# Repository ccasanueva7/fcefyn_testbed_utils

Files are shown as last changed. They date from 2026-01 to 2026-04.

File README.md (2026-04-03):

# fcefyn-testbed-utils

Complementary infrastructure for the FCEFyN HIL (Hardware-in-the-Loop) testbed: configs, scripts, and firmwares that are not part of the contributed repositories libremesh-tests and openwrt-tests.

---

Documentation: https://fcefyn-testbed.github.io/fcefyn_testbed_utils/

### Local preview (MkDocs)

Use the same dependencies as CI (includes `mkdocs-panzoom-plugin` for Mermaid pan/zoom):

```bash
python3 -m venv .venv-docs
source .venv-docs/bin/activate   # Windows: .venv-docs\Scripts\activate
pip install -r requirements-docs.txt
mkdocs serve #or mkdocs serve --livereload
```

If `mkdocs serve` reports `The "panzoom" plugin is not installed`, the active environment is missing dependencies: run `pip install -r requirements-docs.txt` again (or `pip install mkdocs-panzoom-plugin`) in that environment.

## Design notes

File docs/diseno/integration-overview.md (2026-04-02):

# Integration overview

How the FCEFyN testbed integrates with the existing openwrt-tests ecosystem. Intended as the entry point for the Design section: read this first, then follow the links to the detailed docs.

---

## 1. Starting point: openwrt-tests ecosystem

Before the FCEFyN lab existed, [openwrt-tests](https://github.com/openwrt/openwrt-tests) already operated a global testing infrastructure:

- A **VM in a datacenter** (public IP) runs a `labgrid-coordinator` and a pool of GitHub Actions **self-hosted runners**.
- **Remote labs** contributed by developers around the world each run a `labgrid-exporter`. They register their physical DUTs with the global coordinator over a **WireGuard** tunnel.
- When CI triggers (daily, PR, or manual), runners on the VM reserve and lock a device via the coordinator, then flash and test it by SSHing to the lab host over WireGuard.

```mermaid
flowchart TD
    subgraph vm ["Datacenter VM (Paul / aparcar)"]
        R_OWT["GitHub runners"]
        COORD["labgrid-coordinator :20408"]
    end

    subgraph lab_ext ["Remote lab (any contributor)"]
        EXP_E["labgrid-exporter"]
        HW_E["DUTs"]
    end

    R_OWT -- "1" --> COORD
    EXP_E -- "2" --> COORD
    R_OWT -- "3" --> HW_E
```

| # | Connection | Detail |
|---|---|---|
| 1 | Runner → Coordinator | WebSocket localhost:20408 (reserve / lock / unlock) |
| 2 | Exporter → Coordinator | WebSocket via WireGuard (register resources) |
| 3 | Runner → DUTs | SSH via WireGuard (LG_PROXY=labgrid-X) |

See [openwrt-tests CI flow](openwrt-tests-ci-flow.md) for the detailed sequence of how a single job runs end-to-end.

---

## 2. Our hardware contribution to openwrt-tests

The FCEFyN lab contributes physical devices to the openwrt-tests pool. This means:

- `labgrid-fcefyn` is added as a lab entry in `labnet.yaml` (the upstream registry).
- A **`labgrid-exporter`** on the FCEFyN host registers all DUTs with the global coordinator over WireGuard.
- Runners on Paul's VM can then run openwrt-tests jobs on our hardware, exactly as they do with any other lab.

From the coordinator's perspective, our lab is indistinguishable from any other contributor. The process to set this up is documented in [openwrt-tests onboarding](openwrt-tests-onboarding.md).

---

## 3. Our own CI: libremesh-tests runner

For LibreMesh-specific tests, we run our **own GitHub Actions self-hosted runner** on the FCEFyN lab host (not on Paul's VM). This is the key architectural difference from openwrt-tests.

```mermaid
flowchart TD
    subgraph vm ["Datacenter VM (Paul / aparcar)"]
        R_OWT["openwrt-tests runners"]
        COORD["labgrid-coordinator :20408"]
    end

    subgraph lab ["FCEFyN lab host"]
        R_LM["libremesh-tests runner"]
        EXP["labgrid-exporter"]
        BC["labgrid-bound-connect"]
        DUTs["DUTs"]
    end

    R_OWT -- "1" --> COORD
    EXP -- "2" --> COORD
    R_LM -- "3" --> COORD
    R_OWT -- "4" --> BC
    R_LM -- "5" --> BC
    BC -- "6" --> DUTs
```

| # | Connection | Detail |
|---|---|---|
| 1 | openwrt-tests runner → Coordinator | WebSocket localhost:20408 (reserve / lock) |
| 2 | Exporter → Coordinator | WebSocket via WireGuard (register resources) |
| 3 | libremesh-tests runner → Coordinator | WebSocket via WireGuard (LG_COORDINATOR=WG_IP:20408) |
| 4 | openwrt-tests runner → bound-connect | SSH via WireGuard (LG_PROXY=labgrid-fcefyn) |
| 5 | libremesh-tests runner → bound-connect | SSH local (LG_PROXY=labgrid-fcefyn → 127.0.1.1) |
| 6 | bound-connect → DUTs | socat bindtodevice → vlanXXX |

### Key differences vs openwrt-tests runner

| | openwrt-tests runner | libremesh-tests runner |
|---|---|---|
| **Location** | Paul's VM (datacenter) | FCEFyN lab host |
| **Runner label** | `global-coordinator` | `[self-hosted, testbed-fcefyn]` |
| **`LG_COORDINATOR`** | `localhost:20408` (default, same VM) | `vars.LG_COORDINATOR` = WireGuard IP of Paul's VM |
| **`LG_PROXY`** | SSH via WireGuard to lab host | SSH to `127.0.1.1` (localhost, same machine) |
| **SSH to DUT** | WireGuard + `labgrid-bound-connect` | Local `labgrid-bound-connect` |
| **VLAN per test** | Isolated VLANs 100-108 (no change needed) | Switches to VLAN 200 for mesh, restores on teardown |

### `LG_PROXY` in the local case

Both runners set `LG_PROXY=labgrid-fcefyn`. The difference is in how that hostname resolves:

- From Paul's VM: `labgrid-fcefyn` is a WireGuard peer - SSH traverses the tunnel.
- From the lab host itself: Ansible sets `127.0.1.1 labgrid-fcefyn` in `/etc/hosts` - SSH goes to localhost. The `labgrid-bound-connect` proxy command still runs, but entirely on the same machine.

### VLAN difference between test suites

openwrt-tests runs single-node tests. Each DUT stays on its **isolated VLAN** (100-108) for the entire test - no switch reconfiguration needed.

libremesh-tests runs multi-node mesh tests. Participating DUTs must all be on **VLAN 200** to form a mesh. The test fixture switches each port to VLAN 200 at start and restores it on teardown. This is the only test suite that modifies VLAN state.

See [Lab architecture](lab-architecture.md) for the full VLAN design and the `vlan_manager` API.

### `LG_COORDINATOR` configuration

`LG_COORDINATOR` is set as a **GitHub Actions repository variable** in the libremesh-tests repo (`Settings > Secrets and variables > Actions > Variables`):

```
LG_COORDINATOR = <WireGuard IP of Paul's VM>:20408
```

The workflows use `vars.LG_COORDINATOR || 'localhost:20408'`, so if the variable is unset they fall back to localhost (useful for local development against a local coordinator).

---

## 4. Shared coordinator, no conflicts

Both runners - Paul's (openwrt-tests) and ours (libremesh-tests) - talk to the **same `labgrid-coordinator`** on Paul's VM. They share the same pool of places (DUTs).

The coordinator serializes access via **Labgrid locks**: only one runner can hold a lock on a place at a time. A runner that wants a busy device waits (`reserve --wait`) until the lock is released.

```mermaid
sequenceDiagram
    participant R_OWT as openwrt-tests runner
    participant COORD as coordinator
    participant R_LM as libremesh-tests runner

    R_OWT->>COORD: reserve device=linksys_e8450
    COORD-->>R_OWT: LG_TOKEN=A
    R_OWT->>COORD: lock +A

    R_LM->>COORD: reserve device=linksys_e8450
    Note over COORD: place locked
    COORD-->>R_LM: waiting...

    Note over R_OWT: test runs
    R_OWT->>COORD: unlock +A

    COORD-->>R_LM: LG_TOKEN=B
    R_LM->>COORD: lock +B
    Note over R_LM: test runs
    R_LM->>COORD: unlock +B
```

---

## 5. Reading guide for the Design section

| Goal | Start here |
|---|---|
| Understand how openwrt-tests CI runs step by step | [openwrt-tests CI flow](openwrt-tests-ci-flow.md) |
| Set up the WireGuard tunnel and contribute hardware to openwrt-tests | [openwrt-tests onboarding](openwrt-tests-onboarding.md) |
| VLAN design, `vlan_manager` API, switch configuration | [Lab architecture](lab-architecture.md) |
| Virtual mesh tests with QEMU and vwifi | [Virtual mesh](virtual-mesh.md) |

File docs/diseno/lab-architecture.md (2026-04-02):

# Lab architecture (dynamic VLAN per test) {: #lab-architecture }

**Technical design document** for the current HIL lab: one global coordinator, one exporter, shared DUT inventory, and VLAN as a per-test attribute. Context: [openwrt-tests](https://github.com/openwrt/openwrt-tests) and [LibreMesh](https://libremesh.org/) workloads on the same hardware.

---

## 1. Scope

- All DUTs are scheduled from a **single Labgrid inventory** (`dut-config.yaml` `duts` as hardware DB).
- VLAN changes apply only where a test requires them (e.g. mesh); openwrt-tests runs on isolated VLANs by default.

---

## 2. Design principle

The VLAN on a DUT port follows the **test run that holds the Labgrid lock**: the test applies the VLAN it needs at start and restores the port on teardown. Labgrid locking serializes access so two jobs do not reconfigure the same port at once.

---

## 3. Architecture

### 3.1 One coordinator, one exporter

| Component | Role |
|---|---|
| Coordinator | One global (datacenter VM, via WireGuard) |
| Exporter | One `labgrid-exporter` process for all DUTs |
| DUT inventory | `dut-config.yaml` `duts` (hardware database for Labgrid) |
| VLAN / scheduling | Per-test VLAN where needed; Labgrid lock serializes access |

The global coordinator is the single source of locks. libremesh-tests points `LG_COORDINATOR` at the coordinator WireGuard IP instead of `localhost:20408`. For the full connection topology (runners, WireGuard, LG_PROXY) see [Integration overview](integration-overview.md).

```mermaid
flowchart LR
    subgraph lab ["FCEFyN lab host"]
        EXP["labgrid-exporter"]
        SW["Switch TP-Link\n(VLANs 100-108, 200)"]
        DUTs["DUTs"]
    end

    COORD["labgrid-coordinator\n(datacenter VM)"]

    EXP -->|"WebSocket via WireGuard\n(register resources)"| COORD
    SW -->|"access port\n(isolated or VLAN 200)"| DUTs
```

### 3.2 Default state: isolated (fail-safe)

All switch ports start on their **isolated VLAN** (100-108):

- openwrt-tests needs no VLAN changes
- If a test fails or the runner crashes, the DUT stays isolated (no cross-talk)

### 3.3 Dynamic VLAN: the test that needs it changes it

Only libremesh-tests needs VLAN 200. Flow:

```mermaid
sequenceDiagram
    participant CI as libremesh runner
    participant COORD as Global Coordinator
    participant SW as Switch
    participant DUT as DUT port

    CI->>COORD: reserve device=belkin_rt3200
    COORD-->>CI: place allocated
    CI->>COORD: lock place
    CI->>SW: set_port_vlan port 12 vlan 200
    SW->>DUT: Port moves to VLAN 200
    Note over CI,DUT: Test runs - serial flash SSH
    CI->>SW: set_port_vlan port 12 vlan 101
    SW->>DUT: Port restored to isolated VLAN
    CI->>COORD: unlock place
```

Switching overhead: 2-5 s (SSH to switch + CLI). Negligible vs flash + boot (minutes).

### 3.4 Static infrastructure (all VLANs always on)

Configured once and left alone:

| Component | Permanent configuration |
|---|---|
| Switch uplinks (ports 9, 10) | Trunk of ALL VLANs (100-108 + 200) |
| Host netplan | vlan100-108 AND vlan200 up |
| dnsmasq | Instances for all VLANs (DHCP + TFTP) |
| Gateway | Interfaces for all VLANs |

## 4. Key component: `vlan_manager` API (labgrid-switch-abstraction)

Implementation lives in the **labgrid-switch-abstraction** package (`switch_abstraction.vlan_manager`). It uses `SwitchClient` + the existing driver:

```python
def set_port_vlan(dut_name, vlan_id, *, config_path=None):
    """Switch a DUT port to the target VLAN. Thread-safe via flock."""
```

The primitive already exists on the driver interface: `assign_port_vlan_commands(port, vlan_id, mode, remove_vlans)`. Expose it as a high-level function with DUT-to-port resolution from `dut-config.yaml`.

### Pytest fixture (libremesh-tests)

```python
@pytest.fixture
def mesh_vlan(request):
    """Switch DUT port to VLAN 200 before test, restore on teardown."""
    set_port_vlan(dut_name, VLAN_MESH)
    yield
    set_port_vlan(dut_name, isolated_vlan)
```

## 5. Repository split

The split between openwrt-tests and libremesh-tests **does not change**:

| Repo | Responsibility | What changes |
|---|---|---|
| **openwrt-tests** (upstream) | Vanilla OpenWrt tests, single-node | Nothing |
| **libremesh-tests** (ours) | LibreMesh single and multi-node | VLAN fixture; `LG_COORDINATOR` to global |
| **fcefyn_testbed_utils** (ours) | Lab infra, switch drivers, scripts | Static config; host: `switch-vlan` CLI |

## 6. Layers and upstream contribution

```mermaid
flowchart TB
    subgraph layer1 [Layer 1 - Switch Abstraction - contributable]
        DRV[switch_drivers/\ntplink_jetstream openwrt_ubus]
        SC[SwitchClient\nNetmiko]
        VM["vlan_manager API\n(set_port_vlan)"]
        DRV --> SC
        SC --> VM
    end

    subgraph layer2 [Layer 2 - Topology Fixture - contributable]
        TF["topology_fixture\ngeneric pytest\nVLAN per test restore teardown"]
    end

    subgraph layer3a [Layer 3a - libremesh-tests]
        MF["conftest_mesh.py\nVLAN 200 N devices"]
    end

    subgraph layer3b [Layer 3b - openwrt-tests future]
        WF["multi-device fixture\nWiFi speed test"]
    end

    VM --> TF
    TF --> MF
    TF --> WF
```

**Layer 1** supports an abstract layer for switches or network topologies.

**Layer 2** enables multi-device tests for openwrt-tests (WiFi speed, golden-device pattern).

## 7. Relation to Switch Topology Daemon (future)

The `vlan_manager` module in **labgrid-switch-abstraction** is the library base for a daemon. If an HTTP API is needed (like PDUDaemon), add an HTTP server on top of `set_port_vlan()`. Internal logic stays the same.

## 8. Trade-offs

| Aspect | Value | Mitigation |
|---|---|---|
| WireGuard dependency | All testing depends on the tunnel | Stable WireGuard with keepalive; temporary local coordinator fallback |
| Coordinator API latency | Lock/unlock via WireGuard | Light messages; SSH to DUTs is local |
| dnsmasq complexity | 9+ VLANs at once | One-time config; independent instances |
| VLAN switching overhead | 2-5 s per test (libremesh only) | Negligible vs flash+boot |

## 9. What is reused

- `SwitchClient` + `tplink_jetstream.py` driver
- `assign_port_vlan_commands()` (driver interface)
- `dut-config.yaml` `duts` section (DUT to switch port map)
- PDUDaemon and `poe_switch_control.py`
- Serial, TFTP, SSH proxy infra

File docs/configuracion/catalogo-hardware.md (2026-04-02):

# Lab hardware catalog

**Photos and main characteristics** of the physical testbed equipment.

## Sponsors and acknowledgments {: #sponsors-and-acknowledgments }

Part of the equipment arrived as **donations** from manufacturers, institutions or people:

| Sponsor | Equipment |
|---|---|
| [**Banana Pi**](https://banana-pi.org/) | **OpenWrt One** and **Banana Pi R4** boards. |
| [**Nisuta**](https://nisuta.com/) | **USB hub** connected to the host. |
| [**AlterMundi**](https://altermundi.net/) | Several **LibreRouter** units; **TP-Link TL-WDR3500** testbed **gateway** router. |
| [**LibreMesh**](https://libremesh.org/) / [**aparcar**](https://github.com/aparcar) | **Belkin RT3200** DUT routers (LibreMesh ecosystem; hardware via community / typical contact **aparcar**). |
| [**FCEFyN**](https://fcefyn.unc.edu.ar/) | **Lenovo ThinkPad T430** orchestration host (**university** equipment). |
| [**GL.iNet**](https://www.gl-inet.com/) | **Mango** router; **not yet** integrated in the rack (hardware too limited for the usual DUT role in the lab). |

<div class="catalog-sponsors" markdown="0">
<div class="catalog-sponsors__row">
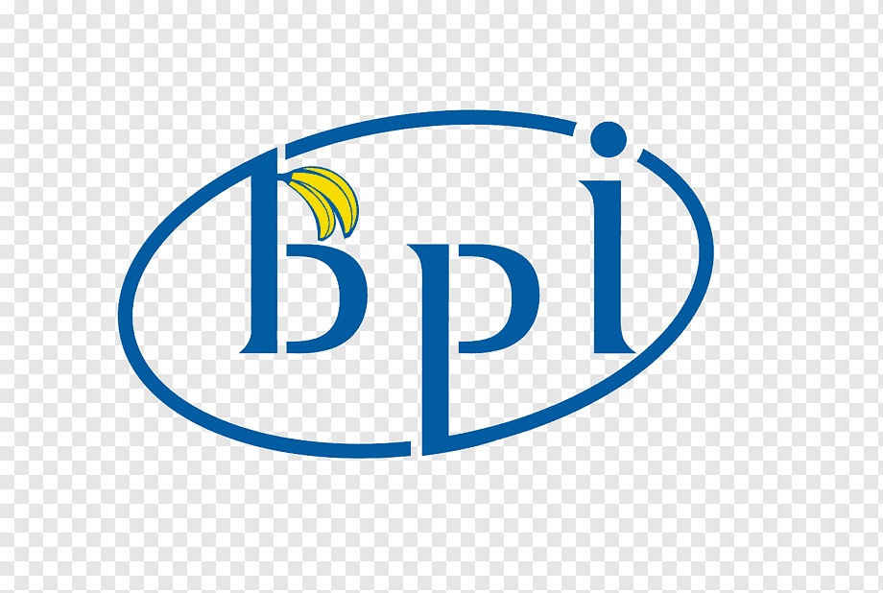
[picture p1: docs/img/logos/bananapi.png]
Banana Pi logo

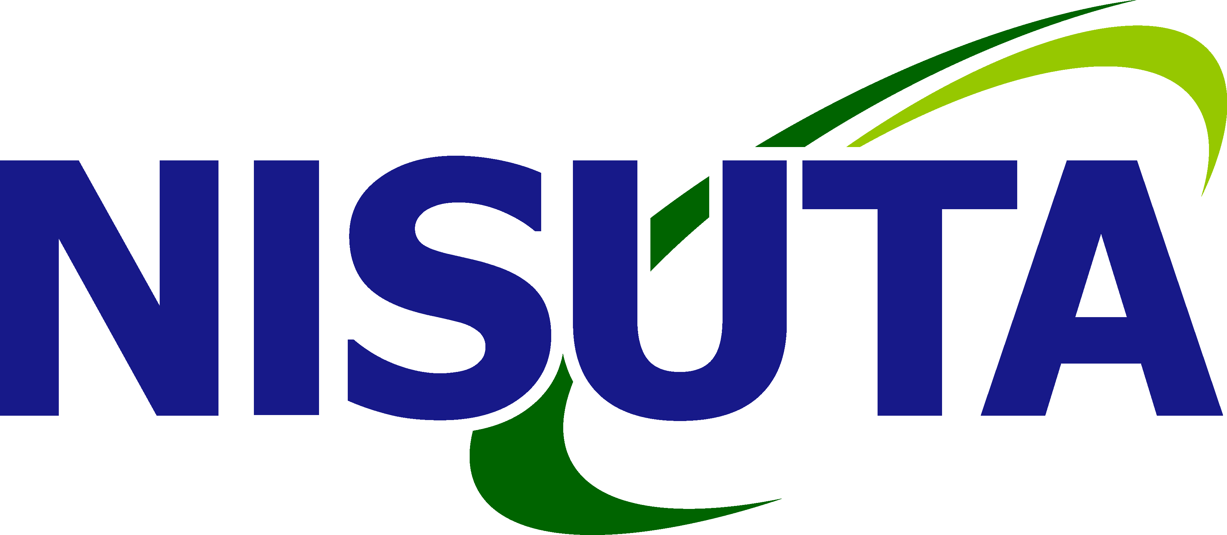
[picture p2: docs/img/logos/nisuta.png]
Nisuta logo

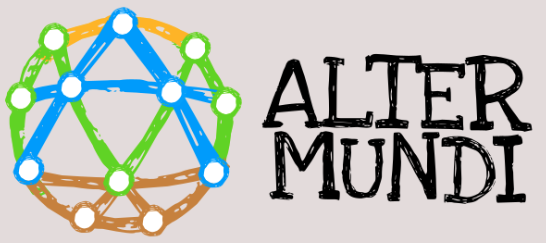
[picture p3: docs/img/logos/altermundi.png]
AlterMundi logo

<a href="https://www.fcefyn.unc.edu.ar/" class="catalog-sponsors__link" title="FCEFyN - UNC">FCEFyN logo</a>
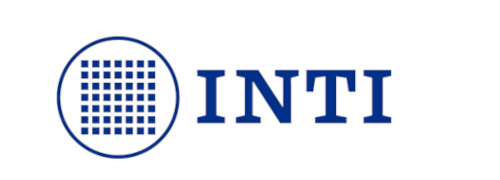
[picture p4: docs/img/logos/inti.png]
INTI logo

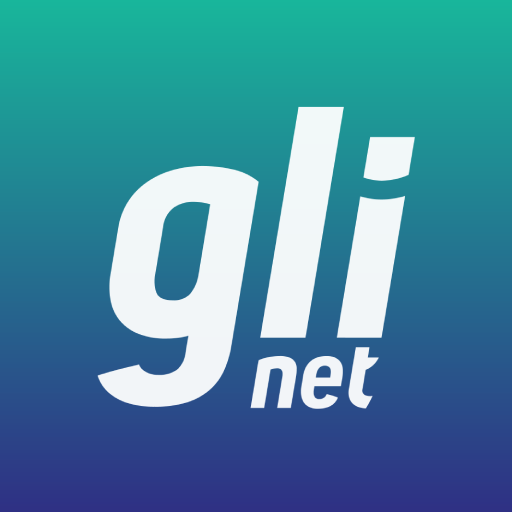
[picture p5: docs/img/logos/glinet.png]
GL.iNet logo

</div>
</div>

## Arduino-controlled rack relays {: #arduino-rack-relays }

The **Arduino Nano** switches power to DUTs and rack infrastructure (cooler, PSU) by sending GPIO signals to the control pins of the relays. More details[here](arduino-relay.md).

### Arduino Nano

<div class="catalog-hardware-row catalog-hardware-row--balanced" markdown="block">

| Attribute | Detail |
|---|---|
| MCU | Microchip **ATmega328P** |
| Logic voltage | 5 V |
| USB | Mini-USB or USB depending on clone (serial to PC) |
| Clock | 16 MHz (typical) |
| In the lab | Custom firmware; **11 outputs** to SSR modules and mechanical relays |

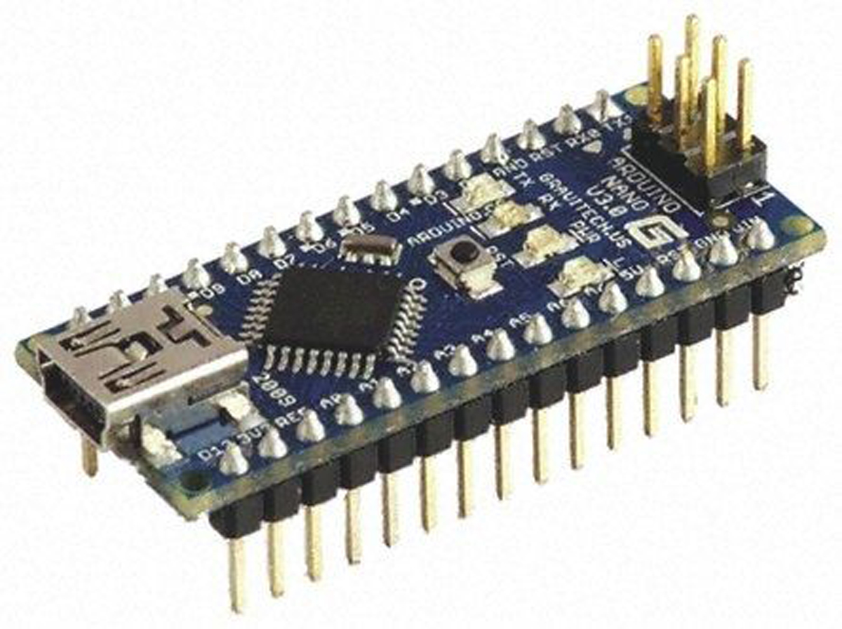
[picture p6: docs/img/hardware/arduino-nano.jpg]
Arduino Nano (relay control)


</div>

### 4-channel SSR module (Omron G3MB-202P)

Placed inside the rack's [AC control box](arduino-relay.md#ac-control-box-lab-build).

<div class="catalog-hardware-row catalog-hardware-row--balanced" markdown="block">

| Parameter | Value |
|---|---|
| Relay | Omron G3MB-202P per channel; phototriac; zero-cross |
| Control | 5 V DC; active low (~0-2.5 V, ~2 mA); module up to ~48 mA |
| Load | 100-240 V AC, 0.1-2 A per channel; fuse |
| Board / connections | ~57 x 55 x 25 mm; **DC+** / **DC-**; **CH1-CH4** |
| In the lab | CH1 no load (D10 wired); CH2 cooler; CH3-CH4 per [arduino-relay](arduino-relay.md) |

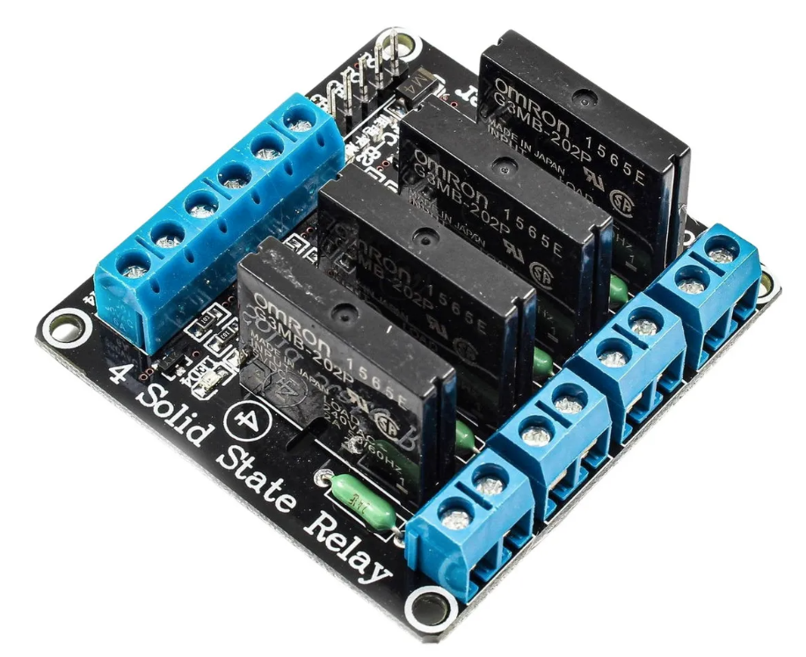
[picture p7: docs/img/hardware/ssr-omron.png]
4-channel Omron G3MB-202P SSR module


</div>

### Fotek SSR-25DA (channel 10)

Placed inside the rack's [AC control box](arduino-relay.md#ac-control-box-lab-build).

This SSR cuts phase to the **AC** load on channel 10 (rack PSU). In Arduino firmware logic is **active high** (channel 10: HIGH = ON; channels 0-9: LOW = ON).

<div class="catalog-hardware-row catalog-hardware-row--balanced catalog-hardware-row--micro-photo" markdown="block">

| Parameter | Value |
|---|---|
| Type | DC in → AC out, high voltage |
| Input | 4-32 V DC |
| Output | 90-480 V AC, up to 25 A (per manufacturer and wiring) |

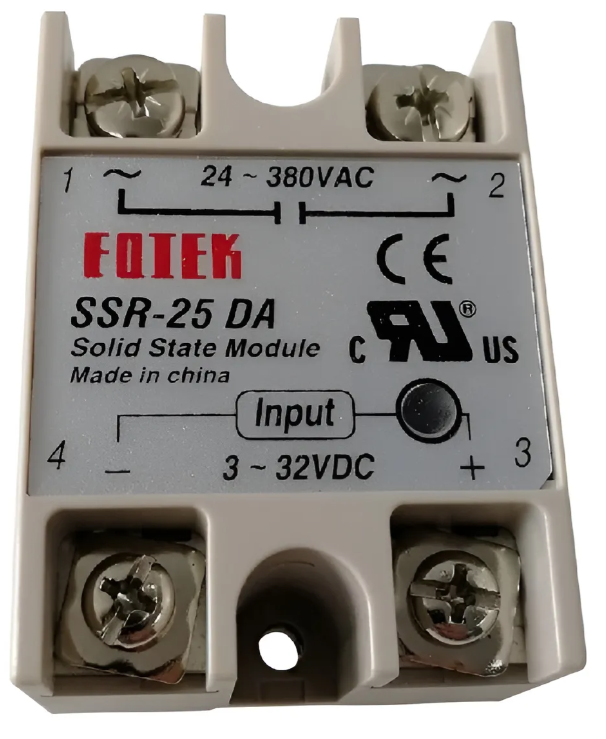
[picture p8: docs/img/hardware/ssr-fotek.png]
Fotek SSR-25DA


</div>

### 8-relay module

Used for channels **0 to 7** (Arduino pins **D2-D9**): optocoupled electromechanical relays, **5 V DC** supply.

<div class="catalog-hardware-row catalog-hardware-row--balanced catalog-hardware-row--relay8" markdown="block">

| Parameter | Value |
|---|---|
| Supply | 5 V DC; opto; SMD LED per channel |
| Contacts | Up to 10 A @ 250 V AC or 30 V DC / 10 A (per module) |
| Firmware | Same digital drive pattern as other inputs |

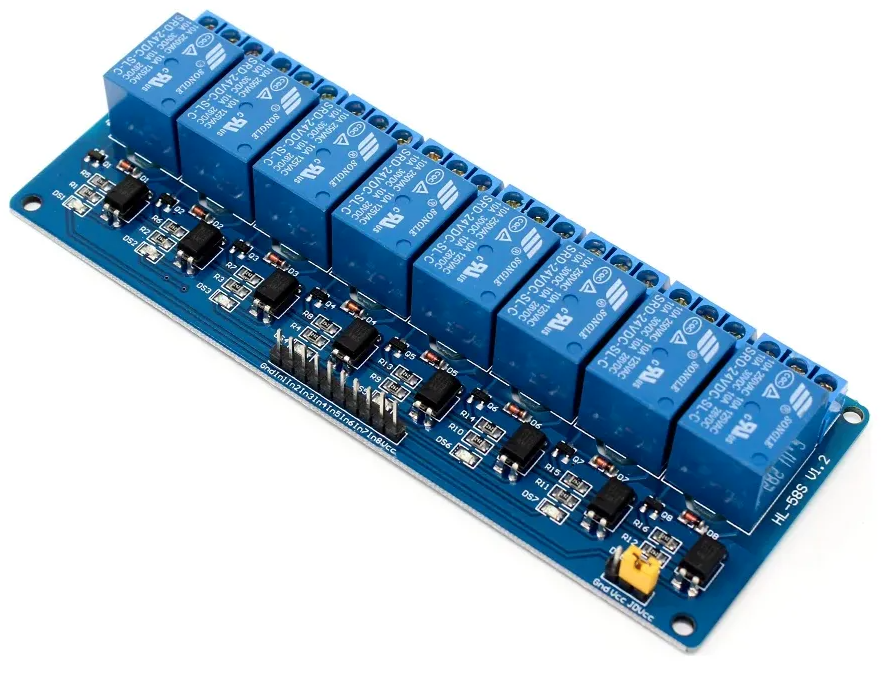
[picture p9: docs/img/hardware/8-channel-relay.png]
8-channel electromechanical relay module


</div>

**AC to rack outlet boxes:** modular switch with **phase break**; visual reference under [Electrical safety and connection](#electrical-safety-and-connection).

## Electrical safety and connection {: #electrical-safety-and-connection }

Reference parts for **AC** (outlet), **12 V DC** positive from DUT relays toward jacks, **common GND** from PSU toward jacks, and **DC connector** assembly per DUT. Wiring detail: [arduino-relay](arduino-relay.md).

| Part | Role in the rack |
|---|---|
| Modular switch / flush outlet | **AC** branch toward outlet boxes; **phase break**. |
| Polyamide terminal block | **12 V+** from DUT relay outputs toward cables to barrel jacks. |
| DIN-rail unipolar distributor (ground) | **GND** from **12 V** PSU toward barrel jack return per DUT. |
| Male DC plug with screw terminals | **Barrel jack** body feeding each DUT (workshop assembly). |

<div class="rack-gallery rack-gallery--catalog-safety" data-rack-gallery tabindex="0">
  <div class="rack-gallery__viewport">
    <figure class="rack-gallery__slide" data-caption="x4 Modular outlets used in the AC control box (phase break, AC branch).">
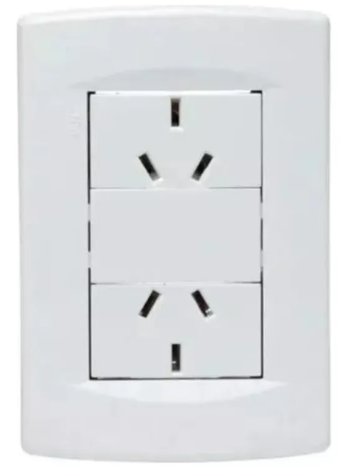
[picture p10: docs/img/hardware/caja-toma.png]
Modular flush outlet reference
      
    </figure>
    <figure class="rack-gallery__slide" data-caption="Polyamide terminal block: 12 V+ from DUT relays to jacks.">
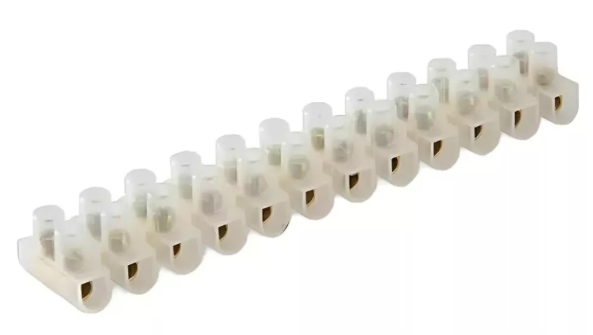
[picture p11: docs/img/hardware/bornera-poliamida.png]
Polyamide pass-through terminal for 12 V positive
      
    </figure>
    <figure class="rack-gallery__slide" data-caption="GND distributor on DIN rail: 12 V PSU to jacks.">
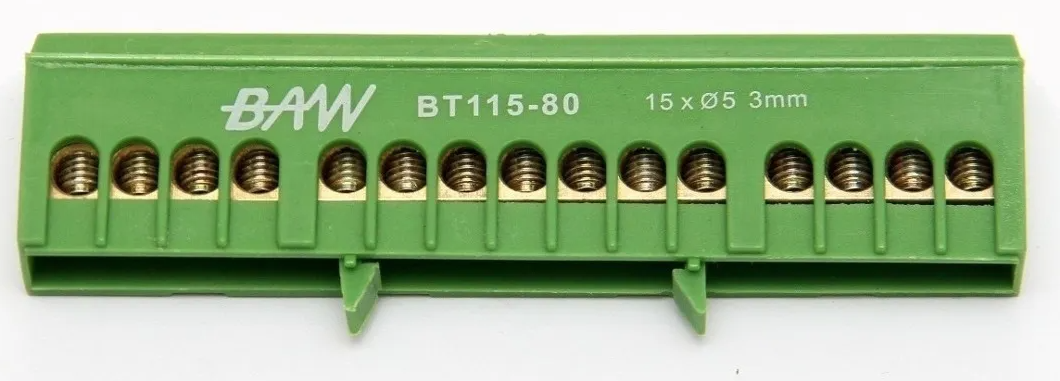
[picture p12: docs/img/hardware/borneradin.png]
Unipolar ground distributor on DIN rail
      
    </figure>
    <figure class="rack-gallery__slide" data-caption="Male DC plug with screw terminals: barrel jack per DUT.">
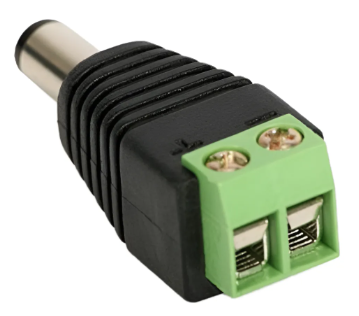
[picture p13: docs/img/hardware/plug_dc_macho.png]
Male DC connector with screw terminals for barrel jack
      
    </figure>
    <div class="rack-gallery__overlay">
      <span class="rack-gallery__counter" data-rack-counter aria-live="polite"></span>
      <button type="button" class="rack-gallery__btn" data-rack-prev aria-label="Previous image">&#8249;</button>
      <button type="button" class="rack-gallery__btn" data-rack-next aria-label="Next image">&#8250;</button>
    </div>
  </div>
  
</div>

## AC supply (channel 10 load) {: #ac-supply-channel-10-load }

The PSU feeding that **AC** branch plugs behind the **Fotek**; channel 10 role in the rack is explained in [arduino-relay](arduino-relay.md).

<div class="catalog-hardware-row catalog-hardware-row--balanced catalog-hardware-row--psu-photo" markdown="block">

| Specification | Value |
|---|---|
| Brand / model | Coper Light metal case |
| Power | 480 W |
| Input | 12-110 VAC, 50/60 Hz |
| Output | 12-220 V |
| Operating temperature | 0-40 °C |
| Protection | Short circuit |

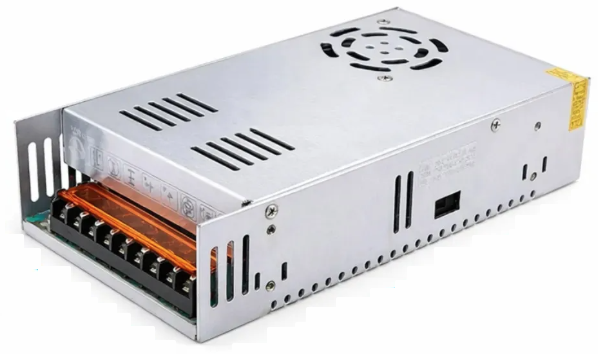
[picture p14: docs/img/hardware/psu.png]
Coper Light metal PSU


</div>

## Bosser 120 mm AC fan {: #bosser-120mm-rack-fan }

**120 mm** frame axial fan at **220 V** mains at the **rack base** (not the Arduino 12 V supply). Pushes air into the curved printed duct; assembly with 3D parts is in [Physical rack](../diseno/diy-rack.md).

<div class="catalog-hardware-row catalog-hardware-row--balanced catalog-hardware-row--cooler-photo" markdown="block">

| Attribute | Value |
|---|---|
| Brand | Bosser |
| Line | 220 V coolers |
| Model | **CBO-12038B-220** |
| Supply | AC **220 V** |
| Current | 0.09 A |
| Frequency | 50 / 60 Hz |
| Bearing | Ball |
| Form factor | **120 x 120 mm** frame |

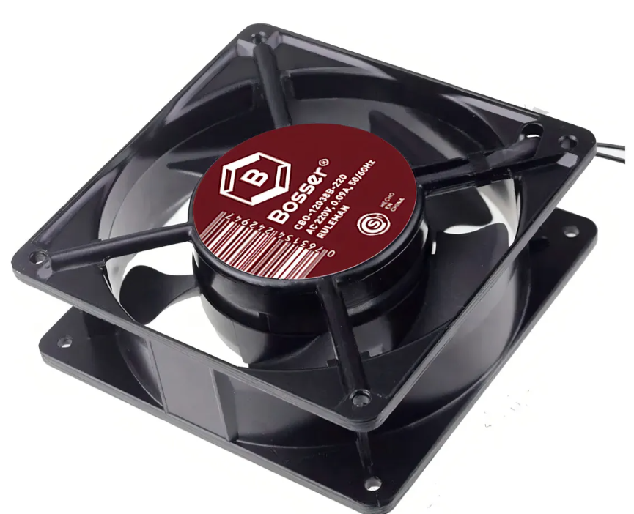
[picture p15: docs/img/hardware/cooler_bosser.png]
Bosser 120 mm fan (product reference)


</div>

In the lab the cooler is switched via **SSR** (channel 9); detail in [arduino-relay](arduino-relay.md).

## USB hub

Mounted in the rack and connected to the orchestration host: **metal enclosure** hub with several USB 3.0 ports.

*Donation **Nisuta** (see [sponsors table](#sponsors-and-acknowledgments)).*

<div class="catalog-hardware-row catalog-hardware-row--balanced catalog-hardware-row--hub-photo" markdown="block">

| Attribute | Detail |
|---|---|
| USB ports | 10 x USB 3.0 (5 Gbps), type A female |
| Fast charge | 1 x QC3.0 port (5 V / 3 A; 9 V / 2 A; 12 V / 1.5 A) |
| Compatibility | USB 2.0 and older |
| Enclosure | Metal |
| Included cable | USB 3.0 A male - B male, 1 m (to PC) |
| External PSU | 12 V, 5.4 A |
| Per USB 3.0 port | Up to 5 V, 0.9 A max per port |

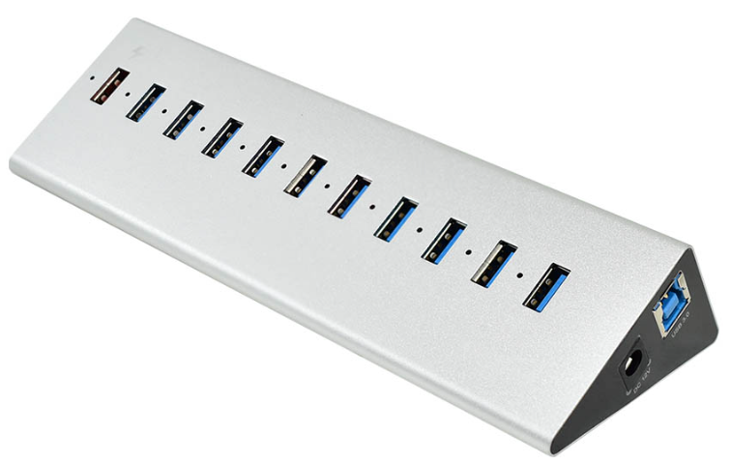
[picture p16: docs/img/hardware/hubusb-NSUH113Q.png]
10-port USB 3.0 hub with PSU


</div>

With several serial adapters and peripherals, the hub runs with **external PSU connected** in addition to the PC USB bus.

## Managed switch (TP-Link SG2016P)

**L2+** lab switch: trunk to host and gateway, access ports to DUTs, some ports **PoE**. Configuration: [switch-config.md](switch-config.md). **Switch power does not go through the Arduino or rack SSR module** (fixed mains); see [arduino-relay](arduino-relay.md).

<div class="catalog-hardware-row catalog-hardware-row--balanced catalog-hardware-row--switch-photo" markdown="block">

| Attribute | Detail |
|---|---|
| Model | **TP-Link SG2016P** |
| Ports | **16 x Gigabit Ethernet** |
| PoE | **8 ports** with PoE (802.3af/at per manufacturer datasheet) |
| Management | Web / SNMP; VLAN 802.1Q, trunk and access |
| In the lab | Port 9 trunk **host** (Lenovo), 10 trunk **gateway**, 1-4 and 11-16 to DUTs (see switch-config) |

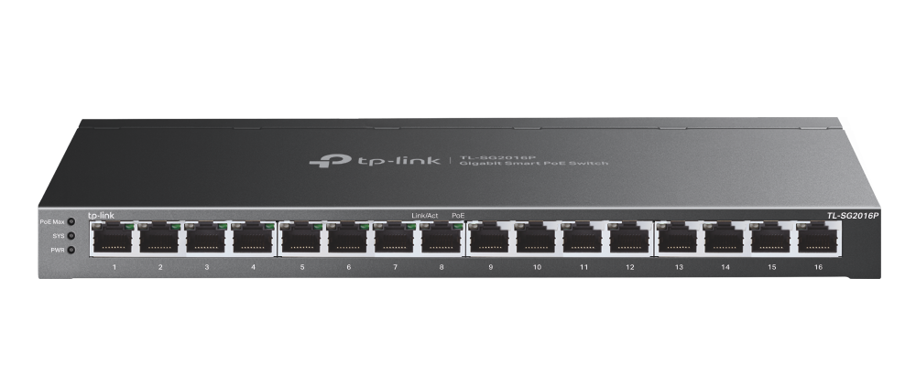
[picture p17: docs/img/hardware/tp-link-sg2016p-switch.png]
TP-Link SG2016P


</div>

## Orchestration host (Lenovo ThinkPad T430)

Lab orchestration host is a **Lenovo ThinkPad T430** notebook with **Ubuntu**: Labgrid, dnsmasq/TFTP, switch scripts, PDUDaemon, and CI runner. Documentation: [host-config.md](host-config.md).

<div class="catalog-hardware-row catalog-hardware-row--balanced catalog-hardware-row--dut-board" markdown="block">

| Attribute | Detail |
|---|---|
| Model | **Lenovo ThinkPad T430** (14" chassis, **T430** generation) |
| Platform | Intel **QM77** chipset; **Ivy Bridge** mobile dual-core CPU (SKU varies) |
| RAM | **DDR3L** 1600 MHz; up to **16 GB** (2 x SO-DIMM) |
| Storage | **2.5" SATA** bay (SSD/HDD per lab unit) |
| Ethernet | **1 x GbE** Intel (e.g. **82579LM**), RJ-45 to switch (802.1Q trunk; typical iface `enp0s25`) |
| USB | **2 x USB 3.0** + **2 x USB 2.0** |
| Display | **14"** (resolution per panel) |
| Video outputs | VGA, **Mini DisplayPort** |
| Expansion | **ExpressCard/54** |
| OS in lab | **Ubuntu** (LTS); Netplan + NetworkManager: [host-config](host-config.md) |
| Lab role | Labgrid, dnsmasq/TFTP, switch scripts, PDUDaemon, SSH to DUTs, CI runners |

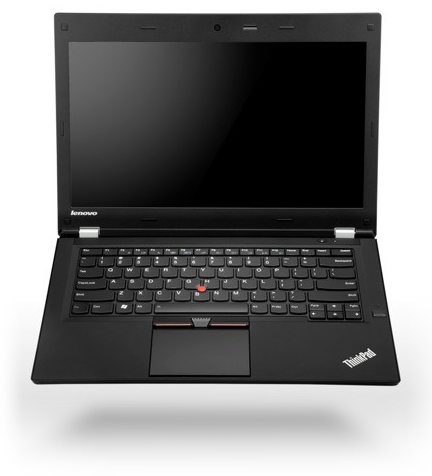
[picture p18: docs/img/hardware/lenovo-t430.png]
Lenovo ThinkPad T430 (lab host)


</div>

*Host **Lenovo**: **faculty** property (FCEFyN / UNC). **INTI** contributes **project hours** (no hardware donation); **INTI** logo in the strip below is acknowledgment only.*

## USB-TTL serial adapters

**USB-UART TTL** converters for DUT console. Symlinks under `/dev/` and **udev** rules: [host-config](host-config.md#7-udev-rules-for-serial-adapters).

| Type | In the lab |
|---|---|
| **FT232RNL** | Preferred: **one USB serial per unit**; **udev** may not depend on hub port. |
| **CH340** | Acceptable budget option; clones share **VID/PID**. TTL level per jumper (**3.3 V** / **5 V**). |
| **CH341** | Budget; **not** reliable on **LibreRouter** console in the rack: during boot serial showed garbage and **U-Boot prompt could not be captured** with labgrid/minicom at 115200, breaking TFTP boot and tests. After **replacing the adapter** with an FT232RNL, console became readable. |
| **Three cheap generics** (last 3 carousel photos) | **Not** used in rack: no DUT console; after DUT reboot **USB must be re-plugged** to recover serial; overheating or sporadic failures under test. |

<div class="rack-gallery rack-gallery--catalog-ttl" data-rack-gallery tabindex="0">
  <div class="rack-gallery__viewport">
    <figure class="rack-gallery__slide" data-caption="FT232RNL (preferred).">
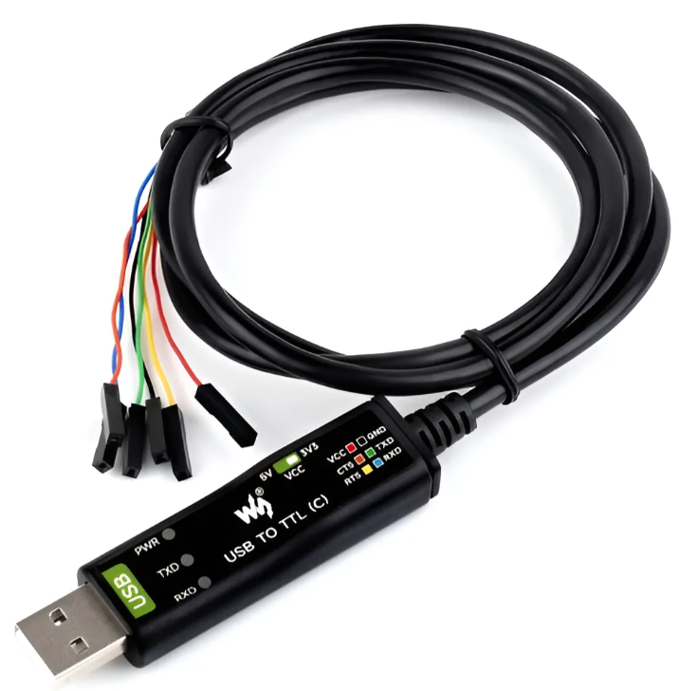
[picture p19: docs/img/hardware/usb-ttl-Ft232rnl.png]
FTDI FT232RNL USB-TTL adapter
      
    </figure>
    <figure class="rack-gallery__slide" data-caption="CH340.">
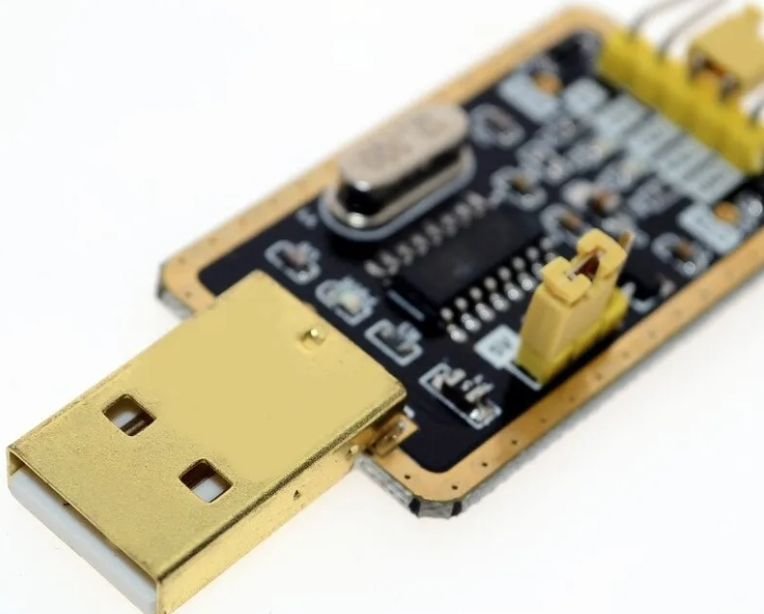
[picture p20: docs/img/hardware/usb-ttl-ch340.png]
CH340 USB-TTL adapter
      
    </figure>
    <figure class="rack-gallery__slide" data-caption="CH341 (budget): unreadable console on lab LibreRouter at boot; see table.">
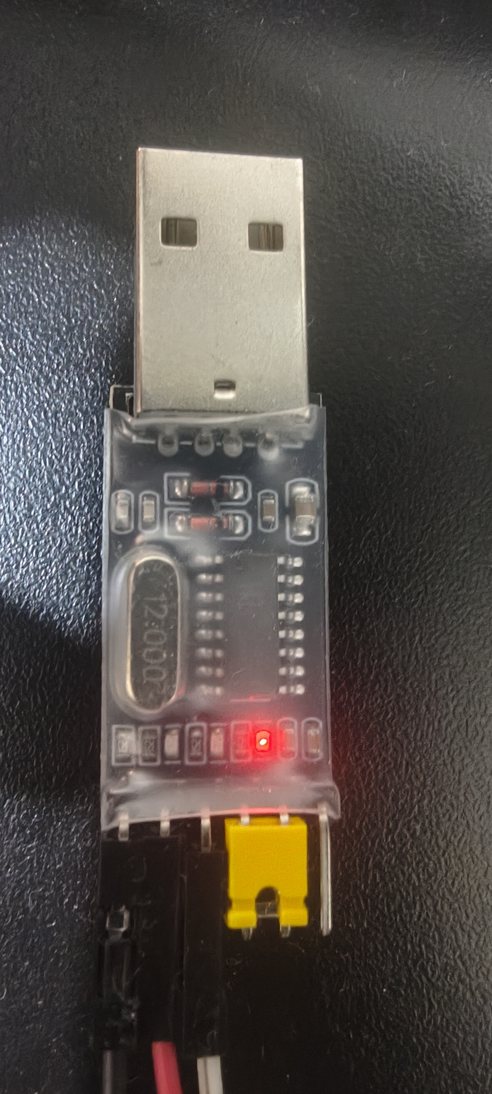
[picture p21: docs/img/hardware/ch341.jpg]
CH341 USB-TTL adapter
      
    </figure>
    <figure class="rack-gallery__slide" data-caption="Cheap generic: not recommended.">
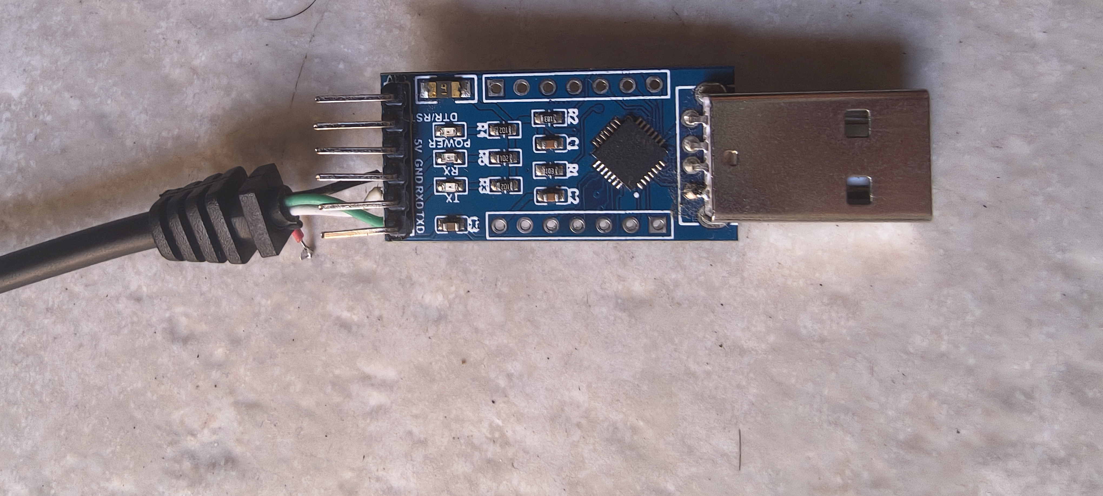
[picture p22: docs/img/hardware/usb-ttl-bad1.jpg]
Cheap generic USB-TTL adapter 1
      
    </figure>
    <figure class="rack-gallery__slide" data-caption="Cheap generic: not recommended.">
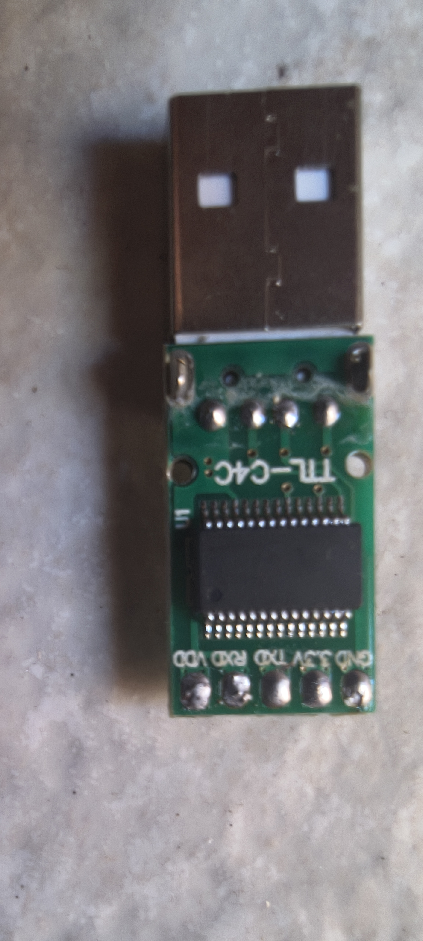
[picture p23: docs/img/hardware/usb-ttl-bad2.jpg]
Cheap generic USB-TTL adapter 2
      
    </figure>
    <figure class="rack-gallery__slide" data-caption="Cheap generic: not recommended.">
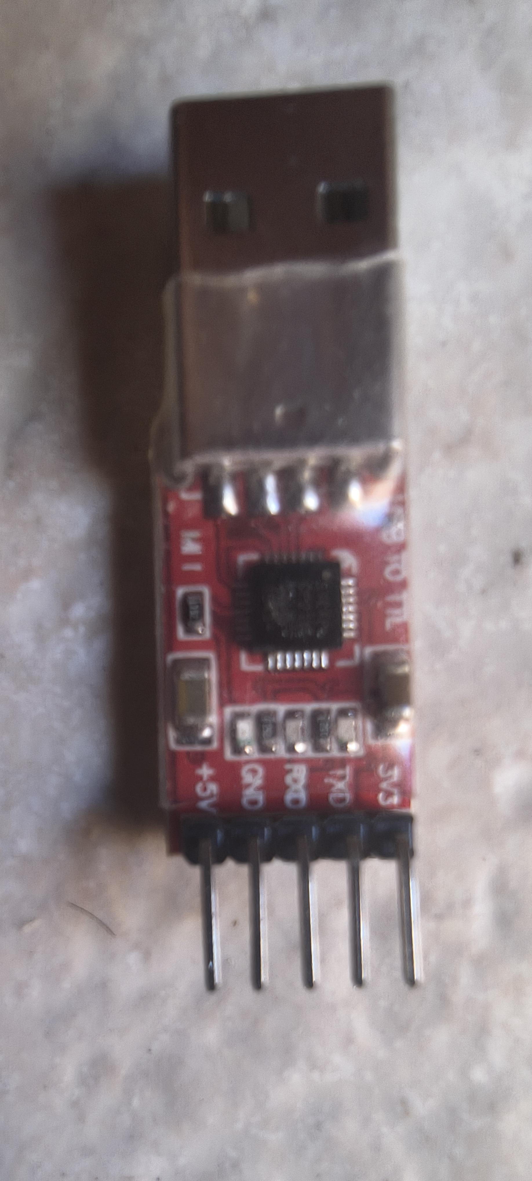
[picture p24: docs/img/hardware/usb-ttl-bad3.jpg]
Cheap generic USB-TTL adapter 3
      
    </figure>
    <div class="rack-gallery__overlay">
      <span class="rack-gallery__counter" data-rack-counter aria-live="polite"></span>
      <button type="button" class="rack-gallery__btn" data-rack-prev aria-label="Previous image">&#8249;</button>
      <button type="button" class="rack-gallery__btn" data-rack-next aria-label="Next image">&#8250;</button>
    </div>
  </div>
  
</div>

For **logs** when boot fails in multi-node tests (libremesh-tests, `mesh_boot_node`), see [LibreMesh testing approach](https://github.com/francoriba/libremesh-tests/blob/main/docs/libremesh-testing-approach.md#mesh-boot-logs) (libremesh-tests repo).

## Testbed gateway (TP-Link TL-WDR3500)

**OpenWrt** router on switch trunk: DUT VLANs, `.254` gateway per subnet. Detail in [gateway.md](gateway.md).

<div class="catalog-hardware-row catalog-hardware-row--balanced catalog-hardware-row--gateway-photo" markdown="block">

| Attribute | Detail |
|---|---|
| Manufacturer | TP-Link |
| SoC | Qualcomm Atheros **AR9344** (MIPS 74Kc) ~560 MHz |
| Architecture | MIPS |
| RAM | 128 MB |
| Flash | 8 MB NOR |
| Ethernet | 5 x **100 Mbit/s** (1 WAN + 4 LAN, integrated AR934x switch) |
| Wi-Fi | Dual-band **N600**: 2.4 GHz 2x2 + 5 GHz 2x2 (802.11n) |
| PoE | No |
| USB | 1 x USB 2.0 |
| OpenWrt | **ath79**; in lab as gateway (e.g. 24.x / 25.x). [TOH / techdata](https://openwrt.org/toh/hwdata/tp-link/tp-link_tl-wdr3500_v1) |

TP-Link TL-WDR3500 (testbed gateway)

</div>

!!! note "TL-WDR3500 role in the testbed"
    For current standards CPU and Fast Ethernet are limiting; the unit is adequate as **VLAN/gateway router** for the lab, not as a high-performance DUT.

*Donation **AlterMundi**.*

## Devices under test (DUTs)

Rack status, switch ports, VLANs, firmware: [duts-config.md](duts-config.md). Technical sheets per model in use; data may vary by board revision. General reference: [OpenWrt Techdata](https://openwrt.org/toh/start).

### OpenWrt One

**Official OpenWrt community** board (Banana Pi hardware); dual NAND + NOR flash oriented to recovery.

<div class="catalog-hardware-row catalog-hardware-row--balanced catalog-hardware-row--dut-board" markdown="block">

| Attribute | Detail |
|---|---|
| Manufacturer / design | Banana Pi (hardware) + **OpenWrt** (official project design) |
| SoC | MediaTek **MT7981B** (Filogic 820), dual-core Cortex-A53 @ 1.3 GHz |
| Architecture | ARM64 |
| RAM | 1 GB DDR4 |
| Storage | **256 MB** SPI NAND + **16 MB** SPI NOR (recovery) |
| Expansion | **M.2** 2242/2230 **NVMe** (PCIe Gen2 x1) |
| Ethernet | 1 x **2.5 GbE** (WAN) + 1 x **1 GbE** (LAN) |
| Wi-Fi | Wi-Fi 6, **MT7976C**: 2.4 GHz **2x2** + 5 GHz **3x3** |
| PoE | **Yes** (802.3af/at on WAN input, per product docs) |
| USB | 1 x USB 2.0 type A + **USB-C** (power / data, per SKU) |
| Other | RTC with battery, **mikroBUS**, MMCX antennas |
| OpenWrt | **Official** support (`mediatek/filogic` images) |

OpenWrt One

</div>

*Donation **Banana Pi**.*

### Banana Pi BPI-R4

Powerful router with **10G** and optional Wi-Fi 7 via miniPCIe modules; used in the lab as a high-performance DUT.

<div class="catalog-hardware-row catalog-hardware-row--balanced catalog-hardware-row--dut-board" markdown="block">

| Attribute | Detail |
|---|---|
| Manufacturer | Banana Pi (Sinovoip) |
| SoC | MediaTek **MT7988A** (Filogic 880), quad-core Cortex-A73 @ 1.8 GHz |
| Architecture | ARM64 |
| RAM | **4 GB or 8 GB** DDR4 (per commercial variant) |
| Storage | **8 GB eMMC** + SPI-NAND (**128 MB or 256 MB**, per revision) |
| Expansion | microSD + **M.2 NVMe** (KEY-M) + M.2 KEY-B (cellular, per board) |
| Ethernet | **4 x 1 GbE** + **2 x 10 GbE SFP+** (RJ45/SFP combo variants exist) |
| Wi-Fi | No on-board radio; **2 x miniPCIe** (PCIe 3.0) for modules (e.g. Wi-Fi 7) |
| PoE | Not integrated on base board |
| USB | 1 x **USB 3.2** |
| OpenWrt | **Yes** (`mediatek/filogic`); in lab as DUT with 10G links |

Banana Pi BPI-R4

</div>

*Donation **Banana Pi**.*

### Libre Router (AlterMundi / LibreRouter.org)

Open hardware for **community networks** and LibreMesh; in the lab with case or bare board per unit.

<div class="catalog-hardware-row catalog-hardware-row--double-img" markdown="block">

| Attribute | Detail |
|---|---|
| Manufacturer / project | **AlterMundi** / **LibreRouter** community |
| SoC | Qualcomm Atheros **QCA9558** MIPS ~720 MHz |
| Architecture | MIPS |
| RAM | 128 MB DDR2 |
| Flash | 16 MB NOR |
| Ethernet | 2 x **1 GbE** (QCA8337 switch), **PoE** and **passthrough** per design |
| Wi-Fi | Integrated 2.4 GHz **2x2** + up to **2 x miniPCIe** for 5 GHz radios (e.g. 802.11an/ac) |
| USB | **2 x USB 2.0** on PCB (may be inaccessible in some enclosures) |
| Other | Published schematics/Gerbers, GPIO, watchdog |
| OpenWrt / LibreMesh | **Yes**; in lab often **LibreRouterOS** / LibreMesh derived from OpenWrt |

<div class="catalog-hardware-row__stack">
<p>Libre Router (rack unit)</p>
<p>Libre Router (board)</p>
</div>

</div>

*Donation **AlterMundi** (LibreRouter project).*

### Belkin RT3200 / Linksys E8450

Same hardware under **Belkin** (RT3200) and **Linksys** (E8450) brands. OpenWrt uses **UBI** layout.

<div class="catalog-hardware-row catalog-hardware-row--double-img" markdown="block">

| Attribute | Detail |
|---|---|
| Commercial OEM | **Belkin** (RT3200) / **Linksys** (E8450) |
| SoC | MediaTek **MT7622BV** (dual Cortex-A53) + **MT7915E** (Wi-Fi 6) |
| Architecture | ARM64 |
| RAM | 512 MB DDR3 |
| Flash | 128 MB SPI-NAND (**UBI** layout on OpenWrt) |
| Ethernet | 5 x **1 GbE** (1 WAN + 4 LAN) |
| Wi-Fi | Dual-band **AX3200** (per manufacturer spec) |
| PoE | No |
| USB | 1 x USB 2.0 on chassis |
| OpenWrt | Install and **UBI** migration: [TOH E8450 / RT3200](https://openwrt.org/toh/linksys/e8450) |

<div class="catalog-hardware-row__stack">
<p>Belkin RT3200</p>
<p>Linksys E8450 (same hardware)</p>
</div>

</div>

*Hardware **LibreMesh** community / **aparcar** channel (see [sponsors](#sponsors-and-acknowledgments)).*

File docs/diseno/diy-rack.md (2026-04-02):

---
title: DIY Rack
---

# DIY Rack

Overview of the lab's **DIY rack** consisting of:

* **Stackable plastic drawers**
* **Multiple 3D printed parts** (ventilation ducts and cases for devices) - CAD sources [`here`](https://github.com/fcefyn-testbed/fcefyn_testbed_utils/tree/main/3d_parts)
* **AC control box interface** for control of devices via SSR relays - electrical schematics can be found in [here](../configuracion/arduino-relay.md).

## Rack photos

<div class="rack-gallery" data-rack-gallery tabindex="0">
  <div class="rack-gallery__viewport">
    <figure class="rack-gallery__slide" data-caption="Tower rack overview: drawers, cabling, and gear per shelf.">
      Tower rack with plastic drawers and cabling
    </figure>
    <figure class="rack-gallery__slide" data-caption="Initial bench setup: routers, USB hub, relays, and wiring before rack integration.">
      Bench test setup with routers and relays
    </figure>
    <figure class="rack-gallery__slide" data-caption="Inside a drawer: USB hub, relay module, and cable routing.">
      Rack drawer with USB hub and relays
    </figure>
    <figure class="rack-gallery__slide" data-caption="Upper drawers open: PSU, hub, and inter-level wiring.">
      Two rack levels open with PSU and wiring
    </figure>
    <div class="rack-gallery__overlay">
      <span class="rack-gallery__counter" data-rack-counter aria-live="polite"></span>
      <button type="button" class="rack-gallery__btn" data-rack-prev aria-label="Previous image">&#8249;</button>
      <button type="button" class="rack-gallery__btn" data-rack-next aria-label="Next image">&#8250;</button>
    </div>
  </div>
  
</div>

## AC Control box

Separate box from the rack: relays/SSR, **UTP** (signals) and **230 V** to cooler and PSU. Detailed wiring schematics [here](../configuracion/arduino-relay.md#electrical-schematics-reference).

<div class="rack-gallery" data-rack-gallery tabindex="0">
  <div class="rack-gallery__viewport">
    <figure class="rack-gallery__slide" data-caption="Relay module enclosure (control box) exterior.">
      Relay module enclosure exterior
    </figure>
    <figure class="rack-gallery__slide" data-caption="Interior: Arduino, relays/SSR, wiring to terminals and UTP.">
      Relay box interior
    </figure>
    <div class="rack-gallery__overlay">
      <span class="rack-gallery__counter" data-rack-counter aria-live="polite"></span>
      <button type="button" class="rack-gallery__btn" data-rack-prev aria-label="Previous image">&#8249;</button>
      <button type="button" class="rack-gallery__btn" data-rack-next aria-label="Next image">&#8250;</button>
    </div>
  </div>
  
</div>

## Thermal considerations and ventilation {: #thermal-considerations }

With vertical stacking, hot air from lower levels **rises** and tends to stagnate at the top, risking overheating of upper equipment. Mitigation is a **bottom fan** (120 mm, 220 V) pushing **cold air upward** and **printed ducts** guiding flow toward the drawers. Fan datasheet: [Hardware catalog - Bosser 120 mm](../configuracion/catalogo-hardware.md#bosser-120mm-rack-fan).

## 3D printed parts

Renders and photos of parts used for ducts, bases, and accessories. Models aim for **support-free** printing where applicable (printer used was a Creality Ender 3 Pro).

| Qty | STL file | Use |
|-----|---|-----|
| 1 | `curved_intake_duct.stl` | Curved duct: 120 mm fan to chimney |
| 4 | `airflow_chimney_duct_3levels.stl` | Vertical segments with grilles (3 levels each) |
| 1 | `airflow_chimney_duct_2levels.stl` | Segment with 2 levels |
| 1 | `chimney_duct_cover.stl` | Chimney top cover |
| 3 | `belkin_rt3200_base.stl` | Compact Belkin RT3200 base |
| 1 | `CE3PRO_librerouter_rack.stl` | Open LibreRouter enclosure (vented base, standoffs) |
| 1 | `NanoHolderA.stl` | Arduino Nano holder |
| 1 | (aux.) `drawer_stop` | Drawer guide / stop (visual asset; filename per `3d_parts/`) |
| 1 | `logo fcefyn.stl`, `logo unc.stl` | Decorative logos |

<div class="rack-gallery rack-gallery--schematics" data-rack-gallery tabindex="0">
  <div class="rack-gallery__viewport">
    <figure class="rack-gallery__slide" data-caption="Curved intake duct (OpenSCAD render / reference).">
      Curved intake duct render
    </figure>
    <figure class="rack-gallery__slide" data-caption="3-level chimney module (grilles toward routers).">
      Three-level chimney render
    </figure>
    <figure class="rack-gallery__slide" data-caption="2-level chimney module.">
      Two-level chimney render
    </figure>
    <figure class="rack-gallery__slide" data-caption="Chimney top cover.">
      Chimney cover render
    </figure>
    <figure class="rack-gallery__slide" data-caption="120 mm fan with curved duct mounted (photo).">
      Fan with curved duct mounted
    </figure>
    <figure class="rack-gallery__slide" data-caption="Printed Belkin RT3200 base in rack.">
      Adapted Belkin base in rack
    </figure>
    <figure class="rack-gallery__slide" data-caption="Open LibreRouter enclosure.">
      Open LibreRouter enclosure
    </figure>
    <figure class="rack-gallery__slide" data-caption="Arduino Nano holder (NanoHolder).">
      Printed Nano holder
    </figure>
    <figure class="rack-gallery__slide" data-caption="FCEFyN and UNC logos.">
      FCEFyN and UNC logos
    </figure>
    <div class="rack-gallery__overlay">
      <span class="rack-gallery__counter" data-rack-counter aria-live="polite"></span>
      <button type="button" class="rack-gallery__btn" data-rack-prev aria-label="Previous image">&#8249;</button>
      <button type="button" class="rack-gallery__btn" data-rack-next aria-label="Next image">&#8250;</button>
    </div>
  </div>
  
</div>

The Belkin base was adapted from [RT3200/E8450 Wall Mount Case](https://www.thingiverse.com/thing:5864938) (TuxInvader): base only, open top for ventilation.

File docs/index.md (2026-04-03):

# FCEFyN testbed documentation

**Hardware-in-the-loop** testing for [OpenWrt](https://openwrt.org/) and [LibreMesh](https://libremesh.org/) at [FCEFyN](https://fcefyn.unc.edu.ar/), [Universidad Nacional de Córdoba](https://www.unc.edu.ar/). Source and tooling live in [fcefyn_testbed_utils](https://github.com/ccasanueva7/fcefyn_testbed_utils). Tests align with [openwrt-tests](https://github.com/aparcar/openwrt-tests) and [libremesh-tests](https://github.com/francoriba/libremesh-tests).

---

## Before you start

**Testbed goal** and scope, in brief:

- **Validate firmware** for *OpenWrt* and *LibreMesh*-based routers in an **automated, repeatable** way using the [Labgrid](https://labgrid.readthedocs.io/en/latest/) + [pytest](https://docs.pytest.org/en/stable/) ecosystem, following *openwrt-tests* and *libremesh-tests*.
- **Cover physical and emulated targets**: tests on **physical devices** in a rack over physical links and on [QEMU](https://www.qemu.org/) instances with WiFi simulated via [vwifi](https://github.com/sysprog21/vwifi).
- **Operate a shared lab**: one DUT inventory for both projects ([Lab architecture](diseno/lab-architecture.md)) and remote access for administrators.

### Testbed overview

Relationship between orchestration host, switch, gateway, DUTs, power, and serial access:

High-level diagram of the testbed and main components

The design builds on the **remote lab** model from [openwrt-tests](https://github.com/aparcar/openwrt-tests), but scope is not limited to **adding devices** to that network. It also **reuses and extends** the approach with **local infrastructure**, along the same axes (orchestration, network, power, serial) with a focus on **LibreMesh** testing.
<!-- test comment mié 01 abr 2026 17:27:50 -03 -->

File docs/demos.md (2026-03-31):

# Video demos

This section collects demo videos showing various operations on the testbed.

---

## Remote access to the HIL testbed

Demonstration of **remote access** to the testbed.

**Watch on YouTube:** [Demo Remote Access to HIL Testbed](https://www.youtube.com/watch?v=QeCQGfZZQgE)

<div class="video-embed">
  <iframe
    src="https://www.youtube.com/embed/QeCQGfZZQgE"
    title="Demo Remote Access to HIL Testbed"
    allow="accelerometer; autoplay; clipboard-write; encrypted-media; gyroscope; picture-in-picture; web-share"
    allowfullscreen
    loading="lazy"
    referrerpolicy="strict-origin-when-cross-origin"
  ></iframe>
</div>

---

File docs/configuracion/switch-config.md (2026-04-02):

# Switch configuration

The lab uses a **TP-Link SG2016P** (16× Gigabit, 8× PoE). **VLAN configuration** is **applied by scripts**, not as a manual CLI routine. Another **802.1Q** switch can reuse the same scheme with another driver under `scripts/switch/switch_drivers/`.

---

## 1. Context

The switch connects three roles:

1. **Gateway** (OpenWrt; formerly MikroTik): layer 3, routes between VLANs and Internet. [gateway.md](./gateway.md).
2. **Host** (Lenovo T430): Labgrid, dnsmasq/TFTP, SSH to DUTs.
3. **DUTs:** one OpenWrt or LibreMesh router per VLAN.

Gateway and host use **trunk** ports (802.1Q, tagged traffic). Each DUT is **access** (untagged traffic on its VLAN).

| Type | Role | Traffic |
|---|---|---|
| **Access** | One DUT per port | Untagged |
| **Trunk**  | Multi-VLAN | Tagged (802.1Q) |

Trunks carry several VLANs; each DUT has a dedicated access port.

---

## 2. Switch requirements

- **802.1Q:** numeric IDs (e.g. 100+); each port access (untagged) or trunk (tagged).
- **PVID:** default VLAN if the frame arrives untagged (access = DUT VLAN; trunk = 1).
- **Ingress checking** on; **acceptable frame types:** Admit All.

---

## 3. Port-to-device mapping (FCEFyN)

### 3.1 Assignment table

| SG2016P port | Device | VLAN | Type |
|---|---|---|---|
| 1 | OpenWrt One | 104  | Access |
| 2 | LibreRouter #1 | 105  | Access (PoE + 48V→12V splitter) |
| 3 | LibreRouter #2 | 106  | Access |
| 4 | LibreRouter #3 | 107  | Access |
| 9 | Lenovo T430 (server) | Trunk | Trunk |
| 10 | OpenWrt router (gateway) | Trunk | Trunk |
| 11 | Belkin RT3200 #1  | 100  | Access |
| 12 | Belkin RT3200 #2  | 101  | Access |
| 13 | Belkin RT3200 #3  | 102  | Access |
| 14 | Banana Pi R4 | 103  | Access |
| 15 | (available) | - | - |
| 16 | OpenWrt One (LAN) | 104  | Access |

Port 16 connects **LAN** of OpenWrt One when **PoE** power is on port 1; see [duts-config OpenWrt One](duts-config.md#openwrt-one). Ports 5-8 unassigned (default VLAN 1).

### 3.2 VLAN names in use

| VLAN ID | Name on switch | Subnet |
|---|---|---|
| 100 | belkin_rt3200_1 | 192.168.100.0/24 |
| 101 | belkin_rt3200_2 | 192.168.101.0/24 |
| 102 | belkin_rt3200_3 | 192.168.102.0/24 |
| 103 | banana-pi-r4 | 192.168.103.0/24 |
| 104 | openwrt-one | 192.168.104.0/24 |
| 105 | libre_router_1 | 192.168.105.0/24 |
| 106 | libre_router_2 | 192.168.106.0/24 |
| 107 | libre_router_3 | 192.168.107.0/24 |
| **200** | **mesh** | 192.168.200.0/24 |

!!! note "Gateway and Internet on DUTs when changing mode"
    Besides **applying the VLAN preset on the switch**, `switch-vlan` (labgrid-switch-abstraction) can open **parallel SSH** to each DUT and adjust gateway, routes, and interfaces per preset. Steps and tables: [duts-config Internet access (opkg)](duts-config.md#internet-access-opkg).

    - **isolated:** per-VLAN gateway `192.168.XXX.254`.
    - **mesh:** gateway `192.168.200.254`.

    In both cases the script sets a **secondary IP** on the gateway subnet (`192.168.{vlan}.x` or `192.168.200.x` per `libremesh_fixed_ip`). Without it the testbed gateway does not route return traffic correctly (NAT / Internet). The same flow **stops the firewall** on the DUT.

---

## 4. Automated configuration

Testbed VLAN configuration is **not done manually** on the switch; these tools apply it:

| Tool | Use |
|---|-----|
| **switch-vlan** | labgrid-switch-abstraction CLI: per-DUT VLAN change (`switch-vlan <dut> <vlan>`, `--restore`, `--restore-all`). Used by tests and manual ops. |
| **labgrid-bound-connect** | SSH ProxyCommand (`socat` + `SO_BINDTODEVICE`) binds each DUT alias to its isolated VLAN. See [SSH access to DUTs](../operar/dut-ssh-access.md). |

Day-to-day: [Routine operations - Dynamic VLAN](../operar/lab-routine-operations.md#dynamic-vlan-and-switch-vlan) (`switch-vlan` / `labgrid-switch-abstraction`; design: [Lab architecture](../diseno/lab-architecture.md)).

!!! note "Manual configuration (reference)"
    For recovery or debug: one test VLAN per access port (untagged); trunk ports with all VLANs tagged; PVID and ingress as in §2 (Admit All).

---

## 5. TP-Link SG2016P: SSH and PoE

### 5.1 SSH and CLI access

The switch accepts SSH for CLI management. Default IP: `192.168.0.1`. The switch **does not accept public-key auth**; use **password**.

See [host-config 3.6](host-config.md#36-ssh-config-for-manual-access-sshconfig) or template `configs/templates/ssh_config_fcefyn`.

Connect:

```bash
ssh switch-fcefyn
```

Prompt is `SG2016P>`.

!!! note "SSH client and authentication"
    The client tries public keys first; the switch rejects and drops the session. Set `PreferredAuthentications password` and `PubkeyAuthentication no` (template above).

**OpenWrt One** is on port 1 (PoE). For software power-cycle:

**Manual (SSH from host):**
```text
enable
configure
interface gigabitEthernet 1/0/1
power inline supply disable    # Power off OpenWrt One
# Wait 5-10 seconds
power inline supply enable     # Power on OpenWrt One
end
```

**Automatic (script):** Install via Ansible (recommended) or manually. Script needs `switch_client.py` and `switch_drivers/` alongside.

**Ansible install:**
```bash
# From fcefyn_testbed_utils
ansible-playbook -i ansible/inventory/hosts.yml ansible/playbook_testbed.yml --tags poe_switch -K
```

**Manual install:** Install `labgrid-switch-abstraction` (`pip install git+https://github.com/fcefyn-testbed/labgrid-switch-abstraction.git`). Copy `scripts/switch/poe_switch_control.py` to `/usr/local/bin/`. Switch config in `~/.config/switch.conf`.

!!! warning "Credentials (out of repo)"
    That file holds the switch password: restrictive perms (`chmod 600`) and do not commit to git.

```bash
# Once: copy template and set switch password
cp configs/templates/switch.conf.example ~/.config/switch.conf
chmod 600 ~/.config/switch.conf
# Edit and set SWITCH_PASSWORD=real_password

# Use (from any directory)
poe_switch_control.py on 1    # Power on port 1 (OpenWrt One)
poe_switch_control.py off 1   # Power off
poe_switch_control.py cycle 1 # Power cycle (off, 5s, on)
poe_switch_control.py on 2    # Port 2 (Librerouter 1)
```

!!! note "Running with sudo"
    Both `poe_switch_control.py` and `switch-vlan` read config from the home of the user who invoked sudo (`SUDO_USER`). If you run `sudo switch-vlan libremesh`, password comes from `/home/<user>/.config/switch.conf`, not `/root/.config/`.

!!! note "PoE and concurrent SSH sessions"
    PDUDaemon may invoke several `poe_switch_control.py` in parallel (multiple PoE DUTs). TP-Link firmware **does not reliably tolerate** concurrent SSH sessions (timeouts). The script serializes access with a lock (`/tmp/switch.lock`, `fcntl.flock`); background calls queue.

!!! note "PDUDaemon integration"
    PoE uses **one** PDUDaemon PDU (`fcefyn-poe`); Labgrid selects the switch port via **index** (same number as in `poe_switch_control.py`). Multiple PoE DUTs do not use separate PDU names. Concurrent power scripts queue on a **lockfile** (switch SSH is not safe in parallel). See [host-config 5.2](host-config.md#52-pdudaemon-etcpdudaemonpdudaemonconf). If PDUDaemon was installed with Ansible (DynamicUser), use systemd override with `SWITCH_PASSWORD`; see [host-config 5.2.1](host-config.md#521-poe-pdu-password-with-dynamicuser).

### 5.2 OpenWrt One: two cables (PoE + LAN for U-Boot TFTP)

!!! note "WAN PHY timeout and second link (LAN)"
    With PoE on port 1, U-Boot on WAN (EN8811H) can hit PHY timeout. **Two links:** WAN (PoE) to port 1; LAN to port 16. Port 16 is VLAN 104 (untagged, PVID 104) so DHCP/TFTP reach the host. More in [duts-config OpenWrt One](duts-config.md#openwrt-one).

!!! note "LibreRouter 1 (port 2) and PoE"
    Uses PoE via 48V→12V splitter. LibreRouter needs passive PoE; switch delivers active (802.3af/at). A generic injector/splitter (e.g. POE-48V-12W Gigabit) converts 48V→12V. Enable PoE on switch port 2 to feed the splitter.

---

## 6. Labgrid integration

### 6.1 Consistency with exporter

VLAN ↔ DUT mapping must match Labgrid `exporter.yaml`:

```yaml
labgrid-fcefyn-belkin_rt3200_1:
  NetworkService:
    address: "192.168.1.1%vlan100"   # VLAN 100 = port 11
    username: "root"

labgrid-fcefyn-openwrt_one:
  NetworkService:
    address: "192.168.1.1%vlan104"   # VLAN 104 = port 1
    username: "root"
```

The `%vlanXXX` in `address` must match the DUT port **VLAN ID** on the switch; tagged traffic hits that interface on the server.

### 6.2 Traffic flow

1. Server sends to `192.168.1.1` from `192.168.1.100` (`vlan100` interface).
2. Frame leaves tagged VLAN 100 toward switch (port 9).
3. Switch forwards on port 11 (VLAN 100 access) untagged to Belkin.
4. Belkin replies; switch retags and sends to port 9 (server) or 10 (gateway) as appropriate.

---

## 7. Other switches

Same 802.1Q logic; need a driver that emits the vendor CLI commands.

1. Add a driver in `labgrid-switch-abstraction` per [DRIVER_INTERFACE.md](https://github.com/fcefyn-testbed/labgrid-switch-abstraction/blob/main/src/switch_abstraction/drivers/DRIVER_INTERFACE.md).
2. In `~/.config/switch.conf`: `SWITCH_DRIVER=<name>` and `SWITCH_DEVICE_TYPE=<netmiko_type>`.

Implement `PRESETS`, `build_preset_commands()`, `build_poe_commands()`, `build_hybrid_commands()`. Reference: `tplink_jetstream.py`.

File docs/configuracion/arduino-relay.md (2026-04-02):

# Relay control via Arduino microcontroller

Automated power control over USB-serial (**115200** baud): DUTs and rack infrastructure (cooler, PSU). The **network switch is neither fed nor switched** from this Arduino; it stays on mains continuously.

## 1. System overview

The Arduino Nano controls **11 channels** over USB-serial. Device: `/dev/arduino-relay` (udev). The `arduino_daemon.py` daemon keeps serial open to avoid bootloader resets; `arduino_relay_control.py` talks to the daemon or the port directly.

| Range | Role |
|---|---|
| 0-7 | Electromechanical relays (8-ch module, 5 V, opto) for DUTs |
| 8-10 | SSR / Fotek: infrastructure (channel 8 wired no-load; cooler; PSU) |

## 2. Hardware and channel map

**Module and channel 10 PSU photos:** [Hardware catalog - Arduino relays](catalogo-hardware.md#arduino-rack-relays) and [AC supply (channel 10)](catalogo-hardware.md#ac-supply-channel-10-load).

### 2.1 Infrastructure (SSR)

| Channel | Pin | Device | Hardware | Logic |
|---|-----|---|---|---|
| **8** | D10 | No load (CH1 on 4-ch SSR; signal wired on UTP) | 4-ch SSR module, CH1 | Active low |
| **9** | D11 | Booster AC cooler | 4-ch SSR module, CH2 | Active low |
| **10** | D12 | Power supply | Fotek SSR-25DA (standalone) | **Active high** |

!!! note "Channel polarity"
    Channel 10: HIGH = ON. Channels 0-9: LOW = ON.

Per-channel AC box build (Omron **CH1-CH4**, Fotek): [AC control box (lab build)](#ac-control-box-lab-build).

### 2.2 DUTs (mechanical relays)

| Channels | Pins | Hardware |
|---|---|---|
| 0-7 | D2-D9 | 8-channel electromechanical relay module (5 V DC, optocoupled) |

### 2.3 Module specifications

Manufacturer tables, load limits, and board data: [Hardware catalog - Arduino relays](catalogo-hardware.md#arduino-rack-relays).

## 3. Physical wiring (DUTs - DC power)

**12 V DC** cut by electromechanical relay (channels 0-7):

| Conductor | Path |
|---|---|
| 12 V+ (PSU) | PSU V+ → relay COM bus → NO contact → DUT DC+ |
| GND (PSU) | PSU GND → common GND bus → DUT GND (not switched) |

## 4. Signal wiring (UTP)

UTP Cat5e/6, ~2 m: signals and common GND.

| Pair | Color | Function | Arduino pin | Relay terminal |
|---|---|---|---|---|
| Orange | Orange | Channel 8 signal (CH1, no load) | D10 | CH1 (4-ch SSR) |
| | White/Orange | GND | GND | DC- |
| Green | Green | Cooler signal | D11 | CH2 (4-ch SSR) |
| | White/Green | GND | GND | DC- |
| Brown | Brown | PSU signal | D12 | Terminal 3 (Fotek) |
| | White/Brown | GND | GND | Terminal 4 (Fotek) |

### Electrical schematics (arduino - relays inside AC control box) {: #electrical-schematics-reference }

<div class="rack-gallery rack-gallery--schematics" data-rack-gallery tabindex="0">
  <div class="rack-gallery__viewport">
    <figure class="rack-gallery__slide" data-caption="UTP signal wiring: D10/D11 to 4-ch SSR (CH1 no load, CH2 cooler), D12 to Fotek, common GND.">
      UTP signal wiring Arduino SSR Fotek
    </figure>
    <figure class="rack-gallery__slide" data-caption="230 V AC infrastructure (single-line): 4-ch SSR, cooler, channel without Arduino signal, Fotek and Coper Light PSU.">
      AC single-line rack SSR and loads
    </figure>
    <figure class="rack-gallery__slide" data-caption="DUTs 0-7: Arduino D2-D9, 8-relay module, 12 V DC PSU and feed per DUT.">
      DC DUTs 8-channel relays and 12 V PSU
    </figure>
    <div class="rack-gallery__overlay">
      <span class="rack-gallery__counter" data-rack-counter aria-live="polite"></span>
      <button type="button" class="rack-gallery__btn" data-rack-prev aria-label="Previous image">&#8249;</button>
      <button type="button" class="rack-gallery__btn" data-rack-next aria-label="Next image">&#8250;</button>
    </div>
  </div>
  
</div>

### AC control box {: #ac-control-box-lab-build }

Serial **command channels** are **0-10** (`ON n`, `arduino_relay_control.py`). On the **Omron G3MB-202P**, silkscreen **CH1-CH4** map as below.

* **Cmd ch** = arduino sketch
* **—** = no Arduino output for that module channel

| Module | Omron CH | Cmd ch | Pin | AC box wired | Load | Arduino signal |
|---|---|---|-----|---|---|---|
| G3MB-202P | CH1 | 8 | D10 | Yes | None | Yes |
| G3MB-202P | CH2 | 9 | D11 | Yes | AC cooler | Yes |
| G3MB-202P | CH3 | — | — | Yes | None | No |
| G3MB-202P | CH4 | — | — | No | None | No |
| Fotek SSR-25DA | Single | 10 | D12 | Yes | PSU (AC branch) | Yes |

Channels **0-9**: active low. Channel **10**: active high. Summary: [§2.1 Infrastructure (SSR)](#21-infrastructure-ssr).

## 5. Serial commands

Baud rate: **115200** bps.

| Command | Description | Example |
|---|---|---|
| `ON n [n ...]` | Turn channel(s) on | `ON 9 10` |
| `OFF n [n ...]` | Turn off | `OFF 10` |
| `TOGGLE n [n ...]` | Toggle | `TOGGLE 9` |
| `PULSE n ms` | Pulse ms | `PULSE 0 500` |
| `ALLON` / `ALLOFF` | All on/off | |
| `STATUS` | State of 11 channels | |
| `HELP` / `ID` | Help / ID | |

```bash
# With arduino_relay_control.py (uses daemon if running)
arduino_relay_control.py on 9 10
arduino_relay_control.py off 10
arduino_relay_control.py pulse 0 3000
arduino_relay_control.py status

# Direct serial (no daemon)
stty -F /dev/arduino-relay 115200 raw -echo && echo "ON 9 10" > /dev/arduino-relay
```

## 6. Arduino Relay Daemon (`arduino_daemon.py`) {: #arduino-relay-daemon }

Avoids Arduino reset when opening/closing the port: persistent serial connection, Unix socket `/tmp/arduino-relay.sock`. `arduino_relay_control.py` and PDUDaemon benefit when the service is enabled.

### 6.1 systemd service (recommended)

Unit source: `configs/templates/arduino-relay-daemon.service` → `/etc/systemd/system/`.

```bash
# From fcefyn-testbed-utils repo root:
sudo cp scripts/arduino/arduino_daemon.py /usr/local/bin/ && sudo chmod +x /usr/local/bin/arduino_daemon.py
sudo cp configs/templates/arduino-relay-daemon.service /etc/systemd/system/
sudo systemctl daemon-reload && sudo systemctl enable --now arduino-relay-daemon
```

### 6.2 Manual (testing)

```bash
./scripts/arduino/start_daemon.sh
# or: python3 scripts/arduino/arduino_daemon.py start --port /dev/arduino-relay
```

Daemon commands: `start`, `stop`, `status`. PID `/tmp/arduino-relay.pid`, socket as above, log `/tmp/arduino-daemon.log` with `start_daemon.sh`.

## 7. Resolve the symlink

```bash
readlink -f /dev/arduino-relay
```

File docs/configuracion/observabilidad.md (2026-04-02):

# Observability - DUT and host metrics

The **lab host** runs the metrics stack. On each **DUT**, only the OpenWrt exporter is required (`prometheus-node-exporter-lua`); the orchestration host exposes its own metrics via `prometheus-node-exporter`. The Ansible **`observability`** role automates the following on the host:

* **Public HTTPS** [Grafana](https://grafana.com/) (Oracle VM, Nginx, reverse SSH tunnel), [more details here](grafana-public-access.md). 
* **Below:** [Prometheus](https://prometheus.io/) scrape and local Grafana on the lab host.

---

## What Ansible automates

| Action | Detail |
|---|---|
| Packages | Installs `autossh`, `prometheus`, `grafana` (official Grafana repo), `prometheus-node-exporter` (host). |
| DUT tunnels | For each `observability_duts` row: unit **`dut-metrics-tunnel-<name>.service`** (`autossh`, forward `127.0.0.1:<local_port>` to `127.0.0.1:9100` on the DUT). |
| Host node exporter | Installs `prometheus-node-exporter`, binds to loopback `127.0.0.1:9100`, generates job `orchestrator-host` in `jobs.d/`. |
| Prometheus | Writes **`/etc/prometheus/prometheus.yml`** from template; validates with `promtool`. Loads jobs from **`/etc/prometheus/jobs.d/*.yml`**. |
| Grafana | Creates **Prometheus** datasource (`uid: prometheus`) via provisioning. Provisions dashboards from JSON in the repo: **Orchestrator Host** and **DUTs & gateway**. |
| Services | Enables and starts tunnels, `prometheus`, `prometheus-node-exporter`, `grafana-server`. |

**Does not** automate: exporter installation on the DUT (opkg) or optional Wi-Fi/hwmon collectors.

---

## Data flow

```mermaid
flowchart LR
  DUT[DUT exporter loopback :9100]
  Proxy[labgrid-bound-connect SSH]
  Tunnel[autossh host :191XX]
  Host[host node_exporter :9100]
  Prom[Prometheus scrape localhost]
  Graf[Grafana PromQL]
  DUT -->|"-L"| Proxy
  Proxy --> Tunnel
  Tunnel --> Prom
  Host --> Prom
  Prom --> Graf
```

Prometheus only talks to **127.0.0.1** on the host; the DUT IP on the VLAN is resolved via SSH + `labgrid-bound-connect` (static isolated VLAN per DUT). If the DUT VLAN changes briefly during tests, the session drops and **`autossh`** brings the forward back up.

---

## systemd units on the host (multiple DUTs)

Each DUT with observability has **its own** tunnel unit. Prometheus and Grafana are **one** each. The host exposes its metrics directly (no tunnel).

```mermaid
flowchart LR
  Tunnels["dut-metrics-tunnel-*.service x7"]
  HostExp[node_exporter.service]
  PromSvc[prometheus.service]
  GrafSvc[grafana-server.service]
  Tunnels -->|"127.0.0.1:1910x"| PromSvc
  HostExp --> PromSvc
  PromSvc --> GrafSvc
```

One tunnel unit per `observability_duts` entry. Useful commands: `systemctl status dut-metrics-tunnel-<name>`, `journalctl -u dut-metrics-tunnel-<name> -n 30`.

---

## Web UIs

| Service | URL | Access |
|---|-----|---|
| Prometheus | [http://127.0.0.1:9090](http://127.0.0.1:9090) | Host or SSH tunnel only |
| Grafana (local) | [http://127.0.0.1:3000](http://127.0.0.1:3000) | Host or SSH tunnel only |
| Grafana (public) | [https://fcefyn-testbed.duckdns.org](https://fcefyn-testbed.duckdns.org) | Internet via Oracle VPS + HTTPS |

In Prometheus: **Status → Targets** lists each job (name = `name` in `observability_duts`). In Grafana: **Prometheus** datasource is provisioned by Ansible.

VPS, Certbot, and tunnel unit: [grafana-public-access.md](grafana-public-access.md).

---

## Grafana dashboards

Two dashboards:

| Dashboard | Source | Description |
|---|---|---|
| **FCEFyN Testbed - DUTs & gateway** | Provisioned (JSON in repo) | DUTs + WDR3500 gateway. **device** variable with `label_values(up{dut!="lab-orchestrator"}, dut)`: **does not** include the orchestration host. All queries use `dut="$device"` and datasource `uid: prometheus`. |
| **FCEFyN Testbed - Orchestrator Host** | Provisioned (JSON in repo) | Orchestration host (~30 panels). Job `orchestrator-host`, label `dut=lab-orchestrator`. |

### DUTs & gateway dashboard sections

| Section | Content |
|---|---|
| Overview | Uptime, CPU, RAM, load, disk `/`, `up` |
| Device info | Instant tables `node_uname_info`, `node_openwrt_info` |
| CPU & load | CPU by mode (stacked), load 1/5/15m |
| Memory | Total / available / used |
| Network | Traffic and packets per interface (excluding `lo`) |
| Disk | Usage % per mountpoint, free space |
| Temperature | `node_hwmon_temp_celsius`, `node_thermal_zone_temp`, CPU stats / max / ieee80211 radios |
| Wi-Fi | `wifi_network_*` (AP), `wifi_stations` / `wifi_station_signal_dbm` (stations, if opkg packages present) |
| Labels | Table of scrape labels (`firmware`, `target`, etc.) from `up{dut="$device"}` |

### Orchestrator Host dashboard sections

| Section | Panels |
|---|---|
| System Overview | Uptime, CPU %, RAM %, Disk %, Swap %, Load, Processes, Open FDs |
| CPU | Usage stacked by mode, Load Average (1/5/15m + cores), Context Switches/Interrupts, Processes & Threads |
| Memory | Usage stacked (apps/buffers/cached/free), Swap |
| Disk / Filesystem | Usage % (bar gauge), Available Space, Inodes % |
| Disk I/O | Throughput (read/write), IOPS, I/O Wait Time, I/O in Progress |
| Network - Physical | Bandwidth (bps), Packets/s, Errors & Drops, TCP Connections |
| Network - VLANs | Bandwidth and packets for vlan100-108, vlan200 (collapsible) |
| System Internals | File Descriptors, Entropy, Sockets by Protocol, Systemd Units (active/failed), Socket Memory |

For **orchestration host only** metrics, always use **Orchestrator Host**; the DUT dashboard excludes it on purpose from the **device** dropdown.

---

## Deploy (Ansible)

```bash
ansible-playbook -i ansible/inventory/hosts.yml ansible/playbook_testbed.yml --tags observability -K
```

Active DUTs are listed in `ansible/roles/observability/defaults/main.yml` (repo root) under `observability_duts`.

---

## Adding a DUT

### Step 1 - On the DUT (manual, once over SSH)

Requires Internet on the DUT (opkg feeds). See also [duts-config - Internet access](duts-config.md#internet-access-opkg).

```sh
opkg update
opkg install prometheus-node-exporter-lua prometheus-node-exporter-lua-openwrt
uci set prometheus-node-exporter-lua.main.listen_interface='loopback'
uci commit prometheus-node-exporter-lua
/etc/init.d/prometheus-node-exporter-lua enable
/etc/init.d/prometheus-node-exporter-lua start
```

Verify: `wget -qO- http://127.0.0.1:9100/metrics | head -5`

The exporter listens **only on loopback** for security.

Optional collectors (hardware dependent):

```sh
opkg install prometheus-node-exporter-lua-hwmon prometheus-node-exporter-lua-wifi
```

#### Filesystem collector (no official package)

The `node_filesystem_*` collector is not an opkg package: upstream PR [#25535](https://github.com/openwrt/packages/pull/25535) has been open since 2020. Install manually as a Lua file:

```sh
cat > /usr/lib/lua/prometheus-collectors/filesystem.lua << 'EOF'
local nix = require "nixio"

local function scrape()
  local metric_size_bytes = metric("node_filesystem_size_bytes", "gauge")
  local metric_free_bytes = metric("node_filesystem_free_bytes", "gauge")
  local metric_avail_bytes = metric("node_filesystem_avail_bytes", "gauge")
  local metric_files = metric("node_filesystem_files", "gauge")
  local metric_files_free = metric("node_filesystem_files_free", "gauge")
  local metric_readonly = metric("node_filesystem_readonly", "gauge")

  for e in io.lines("/proc/self/mounts") do
    local fields = space_split(e)
    local device, mount_point, fs_type = fields[1], fields[2], fields[3]

    if mount_point:find("/dev/?", 1) ~= 1
    and mount_point:find("/proc/?", 1) ~= 1
    and mount_point:find("/sys/?", 1) ~= 1
    and fs_type ~= "overlay" and fs_type ~= "squashfs"
    and fs_type ~= "tmpfs"   and fs_type ~= "sysfs"
    and fs_type ~= "proc"    and fs_type ~= "devtmpfs"
    and fs_type ~= "devpts"  and fs_type ~= "debugfs"
    and fs_type ~= "cgroup"  and fs_type ~= "cgroup2"
    and fs_type ~= "pstore" then
      local ok, stat = pcall(nix.fs.statvfs, mount_point)
      if ok and stat then
        local labels = { device = device, fstype = fs_type, mountpoint = mount_point }
        local ro = (nix.bit.band(stat.flag, 0x001) == 1) and 1 or 0
        metric_size_bytes(labels, stat.blocks * stat.bsize)
        metric_free_bytes(labels, stat.bfree  * stat.bsize)
        metric_avail_bytes(labels, stat.bavail * stat.bsize)
        metric_files(labels, stat.files)
        metric_files_free(labels, stat.ffree)
        metric_readonly(labels, ro)
      end
    end
  end
end

return { scrape = scrape }
EOF
```

After creating or editing the file, **restart** the service so the collector loads (without restart, `wget … | grep node_filesystem` is often empty):

```sh
/etc/init.d/prometheus-node-exporter-lua restart
wget -qO- http://127.0.0.1:9100/metrics | grep node_filesystem
```

Requires `nixio` (usual dependency of `prometheus-node-exporter-lua`; if it fails, `opkg install luci-lib-nixio`).

**Note:** Root filesystem `/` is `overlay` (filtered by design, same as standard node_exporter).

### Thermal sensors by device

Not all SoCs expose temperature sensors in Linux. The table shows which devices report `node_hwmon_temp_celsius`:

| DUT | CPU sensor | Wi-Fi radio sensor | Notes |
|-----|---|---|---|
| openwrt-one | Yes (`thermal_thermal_zone0`) | Yes (`ieee80211_phy0`, `phy1`) | MediaTek Filogic |
| bananapi | Yes (`thermal_thermal_zone0`) | Yes (`ieee80211_phy0`) | MediaTek MT7988 |
| belkin-1 | No | Yes (`ieee80211_phy0`, `phy1`) | MediaTek MT7622 |
| belkin-2 | No | Yes (`ieee80211_phy0`) | MediaTek MT7622 |
| belkin-3 | No | Yes (`ieee80211_phy0`) | MediaTek MT7622 |
| librerouter-1 | No | No | IPQ4019 - not supported |
| gateway-wdr3500 | No | No | QCA9558 (ath79) - not supported |

In Grafana, temperature panels show "No data" for devices without sensors.

### Step 2 - In the repo

Add an entry under `observability_duts` in `ansible/roles/observability/defaults/main.yml`:

```yaml
observability_duts:
  - name: dut-name
    ssh_alias: dut-dut-name
    local_port: 19106
    remote_port: 9100
    labels:
      dut: dut-name
      firmware: openwrt-X.Y.Z
      target: platform-arch
```

Local ports (`local_port`) per DUT (align with [duts-config](duts-config.md) when changing firmware):

| `dut` (Grafana label) | Device | `local_port` | `ssh_alias` |
|---|---|---|---|
| openwrt-one | OpenWrt One | 19100 | `dut-openwrt-one` |
| belkin-1 | Belkin RT3200 #1 | 19101 | `dut-belkin-1` |
| belkin-2 | Belkin RT3200 #2 | 19102 | `dut-belkin-2` |
| belkin-3 | Belkin RT3200 #3 | 19103 | `dut-belkin-3` |
| bananapi | Banana Pi R4 | 19104 | `dut-bananapi` |
| librerouter-1 | Librerouter 1 | 19105 | `dut-librerouter-1` |

Until step 1 is done, the Prometheus target stays **DOWN** for that name; the tunnel may restart in a loop if the DUT is off.

### Step 3 - Apply

```bash
ansible-playbook -i ansible/inventory/hosts.yml ansible/playbook_testbed.yml --tags observability -K
```

---

## Verification

```bash
systemctl status dut-metrics-tunnel-<name>
curl -sS http://127.0.0.1:<local_port>/metrics | head -5
promtool check config /etc/prometheus/prometheus.yml
```

In [Prometheus](http://127.0.0.1:9090): **Status → Targets** - all DUTs plus `orchestrator-host` should appear. In [Grafana](http://127.0.0.1:3000): **FCEFyN Testbed - DUTs & gateway** and **FCEFyN Testbed - Orchestrator Host** (both provisioned by Ansible).

```bash
# Host node exporter
curl -sS http://127.0.0.1:9100/metrics | head -5
systemctl status prometheus-node-exporter
```

---

## Key files

Paths are relative to the repository root.

| Path | Description |
|---|---|
| `ansible/roles/observability/defaults/main.yml` | `observability_duts`, `orchestrator_node_exporter`, `grafana_public_tunnel`, `grafana_config` |
| `ansible/roles/observability/templates/dut-metrics-tunnel.service.j2` | autossh unit per DUT |
| `ansible/roles/observability/templates/dut-scrape-job.yml.j2` | Scrape fragment per DUT |
| `ansible/roles/observability/templates/orchestrator-scrape-job.yml.j2` | Host scrape fragment |
| `ansible/roles/observability/templates/prometheus.yml.j2` | Main `prometheus.yml` |
| `ansible/roles/observability/templates/grafana-dashboards-provider.yml.j2` | File-based dashboard provider in Grafana |
| `ansible/roles/observability/files/dashboards/orchestrator-node.json` | Orchestrator host dashboard JSON |
| `ansible/roles/observability/files/dashboards/duts-node.json` | DUTs + gateway dashboard JSON (variable excludes `lab-orchestrator`) |

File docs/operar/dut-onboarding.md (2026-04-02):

# Guide: add or replace a DUT on the testbed

Onboard a new DUT or replace hardware on an existing switch port.

---

## Summary: files to change

Repos involved: **fcefyn-testbed-utils** (lab config) and **libremesh-tests** (labnet, ansible, targets).

| Step | Repo | File / action |
|---|---|---|
| 1. Hardware | - | USB serial to hub, cable to switch, power (relay or PoE) |
| 2. udev | fcefyn-testbed-utils | `configs/templates/99-serial-devices.rules` → `/etc/udev/rules.d/` |
| 3. dut-config | fcefyn-testbed-utils | `configs/dut-config.yaml` (`duts` section) |
| 4. labnet | libremesh-tests | `labnet.yaml` (devices, device_instances) |
| 5. Exporter / dnsmasq | libremesh-tests | `ansible/files/exporter/labgrid-fcefyn/exporter.yaml`, `dnsmasq.conf` |
| 6. PDUDaemon | libremesh-tests | `ansible/files/exporter/labgrid-fcefyn/pdudaemon.conf` (if power changes) |
| 7. Targets | libremesh-tests | `targets/<device>.yaml` (only if new device type) |
| 8. Netplan | libremesh-tests | `ansible/files/exporter/labgrid-fcefyn/netplan.yaml` (if new VLAN) |
| 9. TFTP | Host | `mkdir /srv/tftp/<place>/`, firmware, symlink |
| 10. Observability | fcefyn-testbed-utils | Install exporter on DUT + add `observability_duts` entry (see [observabilidad](../configuracion/observabilidad.md)) |
| 11. Deploy | - | Ansible (`playbook_labgrid.yml`) |
| 12. Verify | - | `labgrid-client places`, serial, SSH |

---

## New DUT (connecting to a free port on switch)

### 1. Hardware

- Connect a *trustable* DUT USB-serial adapter to hub.
- Ethernet from DUT to free switch port (e.g. port 3 or 15).
- Power: Arduino relay (free channel) or PoE (free port). See [switch-config](../configuracion/switch-config.md) and [host-config 5](../configuracion/host-config.md#5-power-control-and-mapping).

### 2. Identify serial adapter

Follow [host-config 7.5](../configuracion/host-config.md#75-identifying-new-devices):

- Run `sudo dmesg -W` and plug the adapter to see `/dev/ttyUSB*` or `/dev/ttyACM*`.
- Inspect attributes with `udevadm info -a -n /dev/ttyUSB0` (adjust port).
- If **unique serial** (FTDI): rule by `ATTRS{serial}`.
- If **no serial** (CH340, generic CP210x): rule by `KERNELS` per hub port.

### 3. udev

Edit `fcefyn-testbed-utils/configs/templates/99-serial-devices.rules` and add the rule for the new adapter. Example by serial:

```
# Belkin RT3200 #4 - FTDI, serial BG01ABCD
SUBSYSTEM=="tty", ATTRS{idVendor}=="0403", ATTRS{idProduct}=="6001", ATTRS{serial}=="BG01ABCD", \
  SYMLINK+="belkin-rt3200-4", MODE="0666", GROUP="dialout", ENV{ID_MM_DEVICE_IGNORE}="1"
```

On the host:

```bash
sudo cp configs/templates/99-serial-devices.rules /etc/udev/rules.d/
sudo udevadm control --reload-rules && sudo udevadm trigger
ls -la /dev/belkin-rt3200-4   # must exist with DUT connected
```

### 4. dut-config.yaml

In `fcefyn-testbed-utils/configs/dut-config.yaml`, add under `duts`:

```yaml
  belkin_rt3200_4:
    location: fcefyn-testbed
    serial_port: "/dev/belkin-rt3200-4"
    serial_speed: 115200
    pdu_host: "localhost:16421"
    pdu_name: "fcefyn-arduino"
    pdu_index: 4                    # free relay channel
    switch_port: 3                  # physical switch port
    switch_vlan_isolated: 106       # free VLAN (100-108)
    tftp_path: "belkin_rt3200_4/"
    libremesh_fixed_ip: "10.13.200.XXX"   # LibreMesh fixed IP (avoid collisions)
```

For PoE DUTs: use a **single** PDUDaemon PDU name `fcefyn-poe` and set `pdu_index` to the switch PoE port number (same index passed to `poe_switch_control.py`). See `openwrt_one` and `librerouter_1` in `configs/dut-config.yaml` and `libremesh-tests` `ansible/files/exporter/labgrid-fcefyn/exporter.yaml`.

### 5. labnet.yaml

In `libremesh-tests/labnet.yaml`:

- If **device type already exists** and you add another instance (e.g. another Belkin): add under `device_instances`:

```yaml
    device_instances:
      linksys_e8450:
        - belkin_rt3200_1
        - belkin_rt3200_2
        - belkin_rt3200_3
        - belkin_rt3200_4    # new
```

- If it is a **new device type** (not in `devices`): add under `devices` and `labs.labgrid-fcefyn.devices`. For a single unit, `device_instances` may be optional (place `labgrid-fcefyn-<device>`).

### 6. Exporter and dnsmasq

In `libremesh-tests/ansible/files/exporter/labgrid-fcefyn/`:

**exporter.yaml** - add place with RawSerialPort, PDUDaemonPort, TFTPProvider, NetworkService:

```yaml
labgrid-fcefyn-belkin_rt3200_4:
  RawSerialPort:
    port: "/dev/belkin-rt3200-4"
    speed: 115200
  PDUDaemonPort:
    host: "localhost:16421"
    pdu: "fcefyn-arduino"
    port: 4
  TFTPProvider:
    internal: "/srv/tftp/belkin_rt3200_4/"
    external: "belkin_rt3200_4/"
    external_ip: "192.168.106.1"
  NetworkService:
    address: "192.168.1.1%vlan106"
    username: "root"
```

**dnsmasq.conf** - if VLAN is new, add:

```
interface=vlan106
dhcp-range=vlan106,192.168.106.100,192.168.106.200,24h
```

### 7. PDUDaemon

If you use a **new Arduino channel** or **new PoE port**: edit `pdudaemon.conf` to add PDU/port if missing. For multi-channel Arduino relay, same PDU works; for PoE you may need one PDU per port (see [host-config 5.2](../configuracion/host-config.md#52-pdudaemon-etcpdudaemonpdudaemonconf)).

### 8. Targets

Only for a **new device type** not supported yet: create `libremesh-tests/targets/<device>.yaml` (drivers, prompts, boot strategies). See `targets/linksys_e8450.yaml` as reference. If reusing an existing device, skip.

### 9. Netplan

If you added a **new VLAN** (100-108), edit exporter `netplan.yaml` and add the interface. Example:

```yaml
    vlan106:
      id: 106
      link: enp0s25
      addresses:
        - 192.168.106.1/24
        - 192.168.1.106/24
```

Then `netplan apply` and `systemctl restart dnsmasq` on the host.

### 10. TFTP

On the host:

```bash
sudo mkdir -p /srv/tftp/belkin_rt3200_4
# Copy firmware to device type firmwares dir
# Symlink with U-Boot expected name (see tftp-server.md)
ln -sf /srv/tftp/firmwares/linksys_e8450/openwrt-*.bin /srv/tftp/belkin_rt3200_4/linksys_e8450-initramfs-kernel.bin
```

See [tftp-server](../configuracion/tftp-server.md) for naming per device.

### 11. Gateway router

If VLAN is new, configure gateway to route `192.168.XXX.0/24`. See [gateway](../configuracion/gateway.md).

### 12. SSH config (optional)

For alias `ssh dut-belkin-4`: add block in `~/.ssh/config` per `configs/templates/ssh_config_fcefyn`, with `ProxyCommand sudo labgrid-bound-connect vlan106 192.168.1.1 22` (use the DUT's isolated VLAN).

### 13. Deploy and verify

```bash
cd fcefyn-testbed-utils
ansible-playbook -i ansible/inventory/hosts.yml ansible/playbook_labgrid.yml -K
labgrid-client places        # should list labgrid-fcefyn-belkin_rt3200_4
# Test serial and SSH
screen /dev/belkin-rt3200-4 115200
ssh dut-belkin-4
```

---

## Case B: Replace DUT (using a port where another device was connected)

When replacing hardware on an existing port (e.g. broken device in port 1 for another device in that port):

1. **udev**: If serial adapter differs (other chip or USB port), update rule in `99-serial-devices.rules` and reload udev. Same adapter: skip.
2. **dut-config**: Update `serial_port`, `libremesh_fixed_ip` if changed; `pdu_*` if power changes; keep `switch_port` and `switch_vlan_isolated`.
3. **labnet**: If device type changes (e.g. Belkin to LibreRouter), move between `device_instances` or adjust `devices`. Same type: often only place name changes if desired.
4. **exporter.yaml**: Update `RawSerialPort.port`, `TFTPProvider` if path changes, `NetworkService.address` if IP (mesh) changes. VLAN usually unchanged.
5. **pdudaemon.conf**: Only if PDU or port changes.
6. **targets**: Only if new device type.
7. **TFTP**: New directory if place name changes; appropriate firmware.
8. **Netplan / dnsmasq**: Unchanged (same VLAN).
9. **Deploy**: Ansible (`playbook_labgrid.yml`).
10. **duts-config.md**: Update DUT state in [duts-config](../configuracion/duts-config.md) and [rack-cheatsheets](rack-cheatsheets.md).

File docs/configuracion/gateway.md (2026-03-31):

# Gateway / ingress router

* OpenWrt router (currently TL-WDR3500) on trunk to switch.
* VLANs 100-108 and 200, gateway `.254` per subnet.
* MikroTik (personal network) uplink to OpenWrt (192.168.99.0/30); temporary setup.

## 1. Context {: #1-context }

openwrt-tests needs serial, SSH, and TFTP access to each DUT in an **isolated** way.

Each DUT on its own VLAN:

| Requirement | Effect |
|---|---|
| **Determinism** | Traffic stays on the VLAN; no cross-talk between DUTs in concurrent tests. |
| **Security** | No L2 between DUTs; lower risk of one misconfigured router affecting another. |
| **Addressing convention** | OpenWrt defaults to `192.168.1.1` on LAN; with one VLAN per DUT, the same IP can repeat per subnet without conflict (different broadcast domains). |
| **Coordinator** | The Labgrid exporter has an interface on each VLAN; SSH to `192.168.1.1` with binding to that VLAN interface. |

**Gateway role:** L3 (subnets, per-VLAN gateway), optional internet (opkg), firewall. The switch connects on a trunk port (802.1Q).

**DHCP:** The gateway router (OpenWrt) does not run DHCP on test VLANs. The orchestration host runs dnsmasq as DHCP and TFTP on each VLAN; see [tftp-server.md](./tftp-server.md).

---

## 2. Requirements

- **Trunk** - Port carrying tagged VLANs (802.1Q).
- **VLAN interfaces** - One per DUT for OpenWrt (VLANs 100-108, subnets 192.168.100.0/24, etc.). Plus VLAN 200 for LibreMesh (all DUTs on shared 192.168.200.0/24).
- **Firewall** - Allow traffic from test VLANs to the router (SSH, LuCI) and to the internet.
- **NAT** (optional) - For DUT internet access.

### Current implementation: TP-Link TL-WDR3500 v1

- **OpenWrt** installed (tested with 25.12.1, ath79).
- Dedicated WAN port for uplink to the MikroTik.
- At least one LAN port for 802.1Q trunk to the switch.
- VLAN support on the internal switch (swconfig or DSA).

| Field | Value |
|---|---|
| SoC | AR9344 (ath79/generic) |
| Internal switch | AR934x, swconfig, 5 ports (CPU + 4 LAN) |
| WAN | eth1 (separate interface, not through switch) |
| LAN | eth0 through internal switch (ports 1-4) |
| Trunk | Switch port 1 (physically LAN4 on rear panel) |

---

## 3. Network layout

### 3.1 Topology

```mermaid
flowchart TB
    isp["Internet ISP"]
    mt["MikroTik RB750Gr3\nHome LAN · VLANs 10-50 · DHCP · NAT\nether4 · 192.168.99.1/30"]
    ow["OpenWrt router · testbed gateway\nVLANs 100-108 and 200\nWAN 192.168.99.2/30 · gw 192.168.99.1\nLAN trunk 802.1Q tagged"]
    sw["TP-Link SG2016P\nPort 9 · trunk to host Lenovo\nPort 10 · trunk to OpenWrt\nPorts 1-4, 11-16 · access DUTs"]

    isp -->|"PPPoE"| mt
    mt -->|"Direct cable no VLANs"| ow
    ow -->|"Trunk · port 10"| sw
```

The MikroTik only provides internet to the OpenWrt router over a point-to-point link (192.168.99.0/30). The OpenWrt router NATs toward the MikroTik without the MikroTik knowing testbed subnets.

### 3.2 VLAN modes

FCEFyN lab mapping (8 DUTs). VLAN→gateway table: [duts-config.md](./duts-config.md#internet-access-opkg). Align IDs and subnets with `exporter.yaml` and host VLANs.

| Mode | VLANs | Use |
|---|---|-----|
| OpenWrt | 100-108 (isolated) | Isolated tests, one VLAN per DUT |
| LibreMesh | 200 (shared) | Multi-node L2 mesh tests |

### 3.3 Two IPs per VLAN on the host

The server uses two IPs per VLAN (see [host-config 2.4](./host-config.md#24-addressing-two-ips-per-vlan)):

- `192.168.X.1/24` - Provisioning phase: host as DHCP/TFTP server; DUT gets 192.168.X.x at boot.
- `192.168.1.X/24` - SSH phase: host on same subnet as OpenWrt (192.168.1.1); socket binding to reach the DUT.

### 3.4 Physical cabling

Two Ethernet cables:

| Cable | From | To |
|---|---|-----|
| **WAN** | OpenWrt router → WAN port | MikroTik → ether4 |
| **Trunk** | OpenWrt router → one LAN port | SG2016P switch → port 10 |

!!! note "TL-WDR3500: physical LAN port for trunk"
    The LAN port used as trunk maps to internal switch port 1. On the rear panel it is labeled LAN4 (reverse numbering: LAN1=port4, LAN2=port3, LAN3=port2, LAN4=port1).

---

## 4. Labgrid and host on this network {: #4-labgrid-and-host }

**OpenWrt router (from §5 onward):** VLANs 100-108 and 200, gateway `.254` per subnet, firewall, and trunk to the switch. Defines the testbed network environment.

**Orchestration host + Labgrid:** Not configured on the router. Each DUT in `exporter.yaml` declares a `NetworkService` with `%vlanXXX` suffix so SSH exits on the correct **host** VLAN; many DUTs share `192.168.1.1` on different broadcast domains.

```yaml
NetworkService:
  address: "192.168.1.1%vlan100"
  username: "root"
```

`%vlan100` forces traffic via the host `vlan100` interface. Labgrid uses `labgrid-bound-connect` (e.g. `socat` with `so-bindtodevice`) for TCP/SSH. Without binding, the kernel would use the default route and could not distinguish DUTs at the same IP.

**Flow summary (VLAN 100):**

1. The exporter publishes `address: "192.168.1.1%vlan100"` for the DUT place.
2. When opening SSH, Labgrid runs e.g. `labgrid-bound-connect vlan100 192.168.1.1 22`.
3. Traffic leaves on host `vlan100` (e.g. source `192.168.1.100`).
4. The switch delivers VLAN 100 to the DUT; in the SSH phase, host and DUT share `192.168.1.0/24` on that VLAN (same L2 domain): the session need not go through the gateway.

Netplan, host VLANs, and SSH detail: [host-config §1](host-config.md#1-context), [§2 Netplan](host-config.md#2-network-configuration-netplan-with-networkmanager), [§3 SSH to DUTs](host-config.md#3-ssh-to-duts).

---

## 5. OpenWrt configuration - current implementation

Apply over SSH or serial on a freshly installed OpenWrt router (`ssh root@192.168.1.1`).

### 5.1 `/etc/config/network`

Replace the entire file. Adapt commented sections if hardware differs from TL-WDR3500.

```
config interface 'loopback'
	option device 'lo'
	option proto 'static'
	list ipaddr '127.0.0.1/8'

config globals 'globals'
	option ula_prefix 'fdf5:5b96:8798::/48'

# --- Internal switch (only if router uses swconfig) ---
# On DSA routers, skip this section and use bridge VLANs.
# Check with: swconfig list

config switch
	option name 'switch0'
	option reset '1'
	option enable_vlan '1'

# VLAN 1: unused LAN ports (local management)
config switch_vlan
	option device 'switch0'
	option vlan '1'
	option vid '1'
	option ports '2 3 4 0t'

# Testbed VLANs: trunk on port 1 (tagged) + CPU (tagged)
# Port 1 = LAN port wired to SG2016P switch.

config switch_vlan
	option device 'switch0'
	option vlan '2'
	option vid '100'
	option ports '1t 0t'

config switch_vlan
	option device 'switch0'
	option vlan '3'
	option vid '101'
	option ports '1t 0t'

config switch_vlan
	option device 'switch0'
	option vlan '4'
	option vid '102'
	option ports '1t 0t'

config switch_vlan
	option device 'switch0'
	option vlan '5'
	option vid '103'
	option ports '1t 0t'

config switch_vlan
	option device 'switch0'
	option vlan '6'
	option vid '104'
	option ports '1t 0t'

config switch_vlan
	option device 'switch0'
	option vlan '7'
	option vid '105'
	option ports '1t 0t'

config switch_vlan
	option device 'switch0'
	option vlan '8'
	option vid '106'
	option ports '1t 0t'

config switch_vlan
	option device 'switch0'
	option vlan '9'
	option vid '107'
	option ports '1t 0t'

config switch_vlan
	option device 'switch0'
	option vlan '10'
	option vid '108'
	option ports '1t 0t'

config switch_vlan
	option device 'switch0'
	option vlan '11'
	option vid '200'
	option ports '1t 0t'

# --- WAN ---
# Uplink to MikroTik over point-to-point link.
# On TL-WDR3500, WAN is eth1 (outside the switch).

config interface 'wan'
	option device 'eth1'
	option proto 'static'
	option ipaddr '192.168.99.2'
	option netmask '255.255.255.252'
	option gateway '192.168.99.1'
	list dns '8.8.8.8'
	list dns '1.1.1.1'

# --- LAN (local management, unused ports) ---

config device
	option name 'br-lan'
	option type 'bridge'
	list ports 'eth0.1'

config interface 'lan'
	option device 'br-lan'
	option proto 'static'
	list ipaddr '192.168.1.1/24'

# --- Testbed VLAN interfaces ---
# One interface per VLAN. Gateway at .254 per subnet.
# Orchestration host is .1 and runs dnsmasq (DHCP/TFTP).

config interface 'vlan100'
	option device 'eth0.100'
	option proto 'static'
	option ipaddr '192.168.100.254'
	option netmask '255.255.255.0'

config interface 'vlan101'
	option device 'eth0.101'
	option proto 'static'
	option ipaddr '192.168.101.254'
	option netmask '255.255.255.0'

config interface 'vlan102'
	option device 'eth0.102'
	option proto 'static'
	option ipaddr '192.168.102.254'
	option netmask '255.255.255.0'

config interface 'vlan103'
	option device 'eth0.103'
	option proto 'static'
	option ipaddr '192.168.103.254'
	option netmask '255.255.255.0'

config interface 'vlan104'
	option device 'eth0.104'
	option proto 'static'
	option ipaddr '192.168.104.254'
	option netmask '255.255.255.0'

config interface 'vlan105'
	option device 'eth0.105'
	option proto 'static'
	option ipaddr '192.168.105.254'
	option netmask '255.255.255.0'

config interface 'vlan106'
	option device 'eth0.106'
	option proto 'static'
	option ipaddr '192.168.106.254'
	option netmask '255.255.255.0'

config interface 'vlan107'
	option device 'eth0.107'
	option proto 'static'
	option ipaddr '192.168.107.254'
	option netmask '255.255.255.0'

config interface 'vlan108'
	option device 'eth0.108'
	option proto 'static'
	option ipaddr '192.168.108.254'
	option netmask '255.255.255.0'

config interface 'vlan200'
	option device 'eth0.200'
	option proto 'static'
	option ipaddr '192.168.200.254'
	option netmask '255.255.255.0'
```

### 5.2 `/etc/config/firewall`

Replace the entire file.

```
config defaults
	option syn_flood '1'
	option input 'REJECT'
	option output 'ACCEPT'
	option forward 'REJECT'

config zone
	option name 'lan'
	option input 'ACCEPT'
	option output 'ACCEPT'
	option forward 'ACCEPT'
	list network 'lan'

config zone
	option name 'wan'
	option input 'REJECT'
	option output 'ACCEPT'
	option forward 'REJECT'
	option masq '1'
	option mtu_fix '1'
	list network 'wan'

config zone
	option name 'testbed'
	option input 'ACCEPT'
	option output 'ACCEPT'
	option forward 'ACCEPT'
	list network 'vlan100'
	list network 'vlan101'
	list network 'vlan102'
	list network 'vlan103'
	list network 'vlan104'
	list network 'vlan105'
	list network 'vlan106'
	list network 'vlan107'
	list network 'vlan108'
	list network 'vlan200'

config forwarding
	option src 'lan'
	option dest 'wan'

config forwarding
	option src 'testbed'
	option dest 'wan'

config rule
	option name 'Allow-DHCP-Renew'
	option src 'wan'
	option proto 'udp'
	option dest_port '68'
	option target 'ACCEPT'
	option family 'ipv4'

config rule
	option name 'Allow-Ping'
	option src 'wan'
	option proto 'icmp'
	option icmp_type 'echo-request'
	option target 'ACCEPT'
	option family 'ipv4'
```

### 5.3 Disable DHCP on testbed VLANs

The orchestration host runs dnsmasq as DHCP/TFTP server on each VLAN (see [tftp-server.md](./tftp-server.md)). The OpenWrt router **must not** serve DHCP on testbed VLANs.

```bash
for vid in 100 101 102 103 104 105 106 107 108 200; do
    uci set dhcp.vlan${vid}=dhcp
    uci set dhcp.vlan${vid}.interface="vlan${vid}"
    uci set dhcp.vlan${vid}.ignore='1'
done
uci commit dhcp
```

### 5.4 Apply and reboot

```bash
reboot
```

After reboot, move cables per section 3.4 if not done yet. Interfaces take ~30-60s to become usable (ARP resolution).

### 5.5 SSH access to gateway from host {: #55-ssh-access-to-gateway-from-host }

The host reaches the OpenWrt router via VLAN 100 (`192.168.100.254`) in both isolated and mesh modes. Switch trunks (ports 9 and 10) carry VLANs 100-108 tagged in both modes.

Add to the host `~/.ssh/config` (or copy from `configs/templates/ssh_config_fcefyn`):

```
Host gateway-openwrt
    HostName 192.168.100.254
    User root
```

Usage: `ssh gateway-openwrt`

| Mode | VLANs on trunk | Gateway access |
|---|---|---|
| Isolated | 100-108 | `192.168.100.254` (or any 101-108) |
| Mesh | 100-108, 200 | `192.168.100.254` or `192.168.200.254` |

### 5.6 Extroot (USB) - expand storage

The TL-WDR3500 has only 8MB flash (~1MB usable on `/overlay`). ZeroTier and etherwake need more space. Extroot mounts a USB stick as `/overlay`.

**Requirements:** USB stick (any size, e.g. 2-8GB), free USB port.

```bash
apk update
apk add kmod-usb-storage block-mount kmod-fs-ext4 e2fsprogs

ls /dev/sd*     # Expect /dev/sda, /dev/sda1
dmesg | tail -5

# Format as ext4 (compatible features)
mkfs.ext4 -O ^metadata_csum,^64bit,^orphan_file -F /dev/sda1

# If mkfs.ext4 fails, install kmod-fs-ext4 first.
# If space is tight, remove e2fsprogs: apk del e2fsprogs && apk add kmod-fs-ext4
# and format the USB on the orchestration host before plugging it in.

modprobe ext4
mount /dev/sda1 /mnt
cp -a /overlay/. /mnt/
umount /mnt

block detect | uci import fstab
uci set fstab.@mount[0].target='/overlay'
uci set fstab.@mount[0].enabled='1'
uci commit fstab

apk del e2fsprogs
reboot
```

Check: `df -h /overlay` (should show USB size).

### 5.7 ZeroTier (remote access) {: #57-zerotier-remote-access }

Remote access to the gateway router from outside the LAN. Needs extroot (section 5.6) due to flash size.

```bash
apk update
apk add zerotier

uci set zerotier.global.enabled='1'

# Join lab network: OpenWrt init only applies UCI sections of type "network"
# (see note below). Name "fcefyn_vpn" is arbitrary.
uci set zerotier.fcefyn_vpn=network
uci set zerotier.fcefyn_vpn.id='b103a835d2ead2b6'
uci set zerotier.fcefyn_vpn.allow_managed='1'
uci set zerotier.fcefyn_vpn.allow_global='0'
uci set zerotier.fcefyn_vpn.allow_default='0'
uci set zerotier.fcefyn_vpn.allow_dns='0'

uci commit zerotier

/etc/init.d/zerotier enable
/etc/init.d/zerotier restart
sleep 8

zerotier-cli info            # ONLINE
zerotier-cli listnetworks    # b103a835d2ead2b6 OK + IP (ej. 10.246.3.95/24)
```

**UCI and persistence:** `/etc/init.d/zerotier` calls `config_foreach join_network network`: only UCI `config …` sections of type `network` with `option id '<nwid>'` are applied; it generates `networks.d/<nwid>.conf`. Other templates (e.g. `list join` / `openwrt_network`) are ignored: the service starts but does not join on reboot. If a `network` section has an invalid NWID (`zerotier.earth` → `NOT_FOUND`), remove it and keep only the entry with `b103a835d2ead2b6`.

**Typical cleanup** (if `listnetworks` shows a NWID in `NOT_FOUND` or leftover template junk):

```bash
uci delete zerotier.earth 2>/dev/null
uci delete zerotier.openwrt_network 2>/dev/null
uci commit zerotier
```

Then add the `fcefyn_vpn` section (or equivalent) as above and `restart`.

Authorize the node at [my.zerotier.com](https://my.zerotier.com) → network `b103a835d2ead2b6` → Members.

**Firewall:** add ZeroTier interface to `testbed` zone:

```bash
uci add_list firewall.@zone[2].device='zt+'
uci commit firewall
service firewall restart
```

Wildcard `zt+` matches any `zt*` interface. If the zone index changes, adjust (`@zone[2]` = `testbed`). Check with `uci show firewall`.

| Symptom | Cause | Fix |
|---|---|-----|
| `disabled in /etc/config/zerotier` | `zerotier.global.enabled` is `0` | `uci set zerotier.global.enabled='1'; uci commit zerotier` |
| `missing port and zerotier-one.port not found` | Daemon not running | `/etc/init.d/zerotier restart` |
| `ACCESS_DENIED` in `listnetworks` | Node not authorized | Authorize on my.zerotier.com |
| `NOT_FOUND` for a NWID in `listnetworks` | Invalid NWID or missing network; often stale UCI `network` section (`earth`, etc.) | `uci delete zerotier.<name>` for that section; use only `option id` with correct NWID (see above) |
| `listnetworks` shows header only (no networks) | Missing UCI `network` section with `id`, or only `openwrt_network.join` left | Add `uci set zerotier.fcefyn_vpn=network` + `id='b103a835d2ead2b6'` + `allow_*`; `commit`; `restart` |
| `zerotier-cli info` ONLINE but SSH from outside: *No route to host* | Node not on ZT network or wrong IP | Check `listnetworks` OK on router; laptop on same ZT (`zerotier-cli listnetworks`) |
| `Connection refused` SSH to ZeroTier IP | Firewall blocks zt* | Add `zt+` to firewall (above) |

### 5.8 Wake-on-LAN (remote host power-on) {: #58-wake-on-lan-remote-host-power-on }

Power on the orchestration host remotely from the gateway router via ZeroTier.

```mermaid
flowchart LR
    admin["Remote admin"]
    router["OpenWrt router"]
    host["Orchestration host"]

    admin -->|"ZeroTier SSH"| router
    router -->|"etherwake"| host
```

**Requirements:**

1. **Orchestration host:** WoL enabled in BIOS and Linux. See [wake-on-lan-setup.md](../operar/wake-on-lan-setup.md).
2. **OpenWrt router:** `etherwake` installed and reachable over ZeroTier.

```bash
apk add etherwake
```

Send WoL from any machine with ZeroTier access to the router:

```bash
ssh root@<IP-ZeroTier-del-router> 'etherwake -i eth0.100 00:21:cc:c4:25:3b'
```

| Parameter | Value | Notes |
|---|---|---|
| Router ZeroTier IP | `10.246.3.95` (current) | Check my.zerotier.com or `zerotier-cli listnetworks` |
| Interface | `eth0.100` | VLAN 100 (any testbed VLAN works) |
| Orchestration host MAC | `00:21:cc:c4:25:3b` | Host iface `enp0s25` |

**Magic packet via `eth0.100`:** WoL is L2 broadcast. The packet leaves on `eth0.100`, enters the switch trunk (port 10), the switch forwards tagged to the host (port 9) and the NIC accepts with 802.1Q.

**wol.service on host (timing fix):** must run **after** NetworkManager because NM resets the setting. Contents: `/etc/systemd/system/wol.service`:

```ini
[Unit]
Description=Enable Wake On LAN
After=NetworkManager.service
Wants=NetworkManager.service

[Service]
Type=oneshot
ExecStartPre=/bin/sleep 5
ExecStart=/usr/sbin/ethtool -s enp0s25 wol g
RemainAfterExit=yes

[Install]
WantedBy=multi-user.target
```

Check: `sudo ethtool enp0s25 | grep Wake-on` (should be `g`, not `d`).

**Sequence:**

1. Admin connects to router over ZeroTier: `ssh root@10.246.3.95`
2. Send WoL: `etherwake -i eth0.100 00:21:cc:c4:25:3b`
3. Orchestration host boots (~30-60s). `wol.service` re-enables WoL for the next shutdown.
4. Admin can SSH to host over ZeroTier: `ssh laryc@10.246.3.118` (or host ZT IP)

---

## 6. Verification

From the orchestration host:

```bash
# Switch reachable (VLAN 1, management)
ping -c 2 192.168.0.1

# Gateway reachable on each VLAN
for v in 100 101 102 103 104 105 106 107 108; do
    ping -c 1 -W 2 192.168.${v}.254 && echo "VLAN $v: OK" || echo "VLAN $v: FAIL"
done

# Internet from OpenWrt router
ssh root@192.168.100.254 'ping -c 2 8.8.8.8'

# DNS from OpenWrt router
ssh root@192.168.100.254 'nslookup openwrt.org'
```

If a VLAN does not reply to ping right after reboot but SSH works, wait ~30 seconds (ARP).

---

## 7. Notes and troubleshooting

### swconfig vs DSA

- **swconfig** (TL-WDR3500, ath79): VLANs in `config switch_vlan` sections with `option vlan` (index) and `option vid` (802.1Q VLAN ID). Interfaces: `eth0.<vid>`.
- **DSA** (newer routers): each LAN port is a separate interface (`lan1`, `lan2`, …). VLANs via bridge VLAN filtering. See OpenWrt wiki.

```bash
swconfig list          # Si responde → swconfig
ls /sys/class/net/     # Si hay lan1, lan2, ... → DSA
```

### Port mapping (swconfig)

```bash
swconfig dev switch0 show
```

Confirm CPU port (usually 0) and LAN ports (1-4). Trunk is on one LAN port, tagged (`t`).

### Verify VLANs created

```bash
swconfig dev switch0 show   # Internal switch VLAN table
ifconfig | grep "inet addr" # Assigned IPs
ls /sys/class/net/          # Existing interfaces
```

### Lost access to SG2016P switch

If after `switch-vlan` (or manual VLAN changes) the switch (192.168.0.1) is unreachable:

1. **Trunk without VLAN 1 untagged**: SG2016P trunk ports must keep VLAN 1 untagged with PVID 1 for management (192.168.0.x). Check in `tplink_jetstream.py` that trunks include `switchport general allowed vlan 1 untagged` and `switchport pvid 1`.
2. **NetworkManager DHCP on physical iface**: if the host has `dhcp4: true` on the trunk iface (enp0s25) and no DHCP server on VLAN 1, NetworkManager drops the iface every ~45s. Fix: `dhcp4: false` in netplan.
3. **"Wired connection N" profiles**: delete auto NM profiles that fight netplan: `nmcli connection delete "Wired connection 1"`.

---

## 8. Adapting to another router

To use a router other than TL-WDR3500:

1. **Install OpenWrt** and check compatibility on [Table of Hardware](https://openwrt.org/toh/start).
2. **Identify interfaces**: `swconfig list` (or DSA), `ip link show`. Determine WAN and LAN.
3. **Adapt `/etc/config/network`**:
   - Change `option device 'eth1'` on WAN if the iface name differs.
   - Adjust `option ports` in `switch_vlan` per port map.
   - If DSA, replace `config switch*` sections with bridge VLAN filtering.
4. **Firewall and DHCP**: usually unchanged (hardware-independent).
5. **Verify** with section 6 commands.

| Parameter | Current value | What to change |
|---|---|---|
| WAN device | `eth1` | WAN iface name on new router |
| WAN IP | `192.168.99.2/30` | Only if changing link to MikroTik |
| Switch name | `switch0` | Check with `swconfig list` |
| Trunk port | `1` (internal) | Check with `swconfig dev switch0 show` |
| CPU port | `0` (tagged) | Usually 0 |
| Unused ports | `2 3 4` | Remaining LAN |
| VLAN range | 100-108, 200 | Adjust if DUTs added/removed |
| Gateway IPs | `192.168.X.254/24` | Consistent with host and switch |

---

## 9. MikroTik RouterOS (deprecated after WDR3500 switch)

The lab gateway is OpenWrt on the trunk. If the MikroTik still has VLANs or firewall from when it was L3 to the testbed, the blocks below document that config; cleanup is in section 9.5. 8 DUTs (VLANs 100-108), VLAN 200 for LibreMesh. Switch-facing interface: `LAB-TRUNK` (renamed from `ether3`).

### 9.1 Create VLAN interfaces

```routeros
/interface vlan
add interface=LAB-TRUNK name=vlan100-testbed vlan-id=100
add interface=LAB-TRUNK name=vlan101-testbed vlan-id=101
add interface=LAB-TRUNK name=vlan102-testbed vlan-id=102
add interface=LAB-TRUNK name=vlan103-testbed vlan-id=103
add interface=LAB-TRUNK name=vlan104-testbed vlan-id=104
add interface=LAB-TRUNK name=vlan105-testbed vlan-id=105
add interface=LAB-TRUNK name=vlan106-testbed vlan-id=106
add interface=LAB-TRUNK name=vlan107-testbed vlan-id=107
add interface=LAB-TRUNK name=vlan108-testbed vlan-id=108
add interface=LAB-TRUNK name=vlan200-mesh vlan-id=200
```

### 9.2 Assign IP addresses

```routeros
/ip address
add address=192.168.100.254/24 interface=vlan100-testbed network=192.168.100.0
add address=192.168.101.254/24 interface=vlan101-testbed network=192.168.101.0
add address=192.168.102.254/24 interface=vlan102-testbed network=192.168.102.0
add address=192.168.103.254/24 interface=vlan103-testbed network=192.168.103.0
add address=192.168.104.254/24 interface=vlan104-testbed network=192.168.104.0
add address=192.168.105.254/24 interface=vlan105-testbed network=192.168.105.0
add address=192.168.106.254/24 interface=vlan106-testbed network=192.168.106.0
add address=192.168.107.254/24 interface=vlan107-testbed network=192.168.107.0
add address=192.168.108.254/24 interface=vlan108-testbed network=192.168.108.0
add address=192.168.200.254/24 interface=vlan200-mesh network=192.168.200.0
```
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

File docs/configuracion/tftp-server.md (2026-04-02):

# TFTP server with dnsmasq

The orchestration host runs **dnsmasq** as **DHCP** and **TFTP** server on each VLAN. DUTs download firmware during boot (recovery mode); WAN can get an IP when connected.

**Paths:** `/etc/dnsmasq.conf`, `/srv/tftp/`.

**Sections:** 1. dnsmasq | 2. configuration | 3. TFTP directories | 4. Labgrid | 5. firmware | 6. verification | 7. retention | 8. references.

---

## 1. What dnsmasq is for

dnsmasq provides DNS, DHCP, and TFTP. Here only **DHCP** and **TFTP** are used (DNS disabled with `port=0`).

**Recovery flow:** DUT boots, requests DHCP, gets IP and TFTP server, downloads firmware over TFTP, flashes, and reboots.

```mermaid
flowchart LR
    boot["DUT boot / recovery"] --> dhcp["DHCP on VLAN"]
    dhcp --> info["IP + TFTP next-server"]
    info --> tftp["Firmware download"]
    tftp --> flash["Flash and reboot"]
```
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

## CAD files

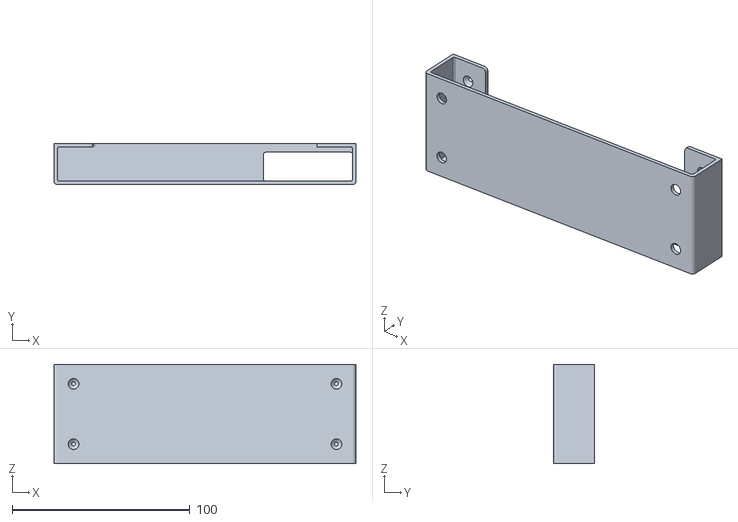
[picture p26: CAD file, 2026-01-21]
rack_design/hub_shelf_TP-LINK_UH700.stl
170.0 x 23.3 x 56.0

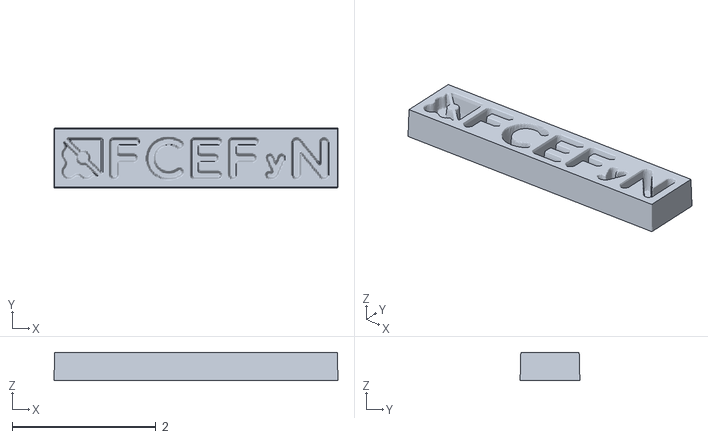
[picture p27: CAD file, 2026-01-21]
3d_parts/logo fcefyn.stl
3.95 x 0.831 x 0.394

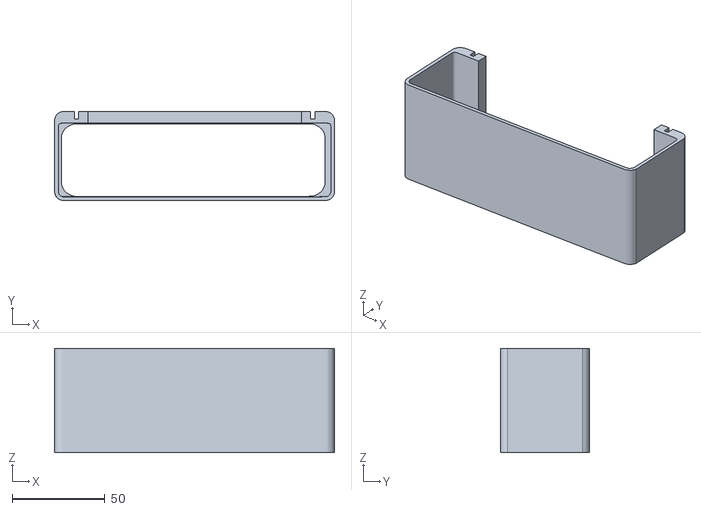
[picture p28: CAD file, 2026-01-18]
rack_design/drawer_stop.stl
150.6 x 48.0 x 56.0

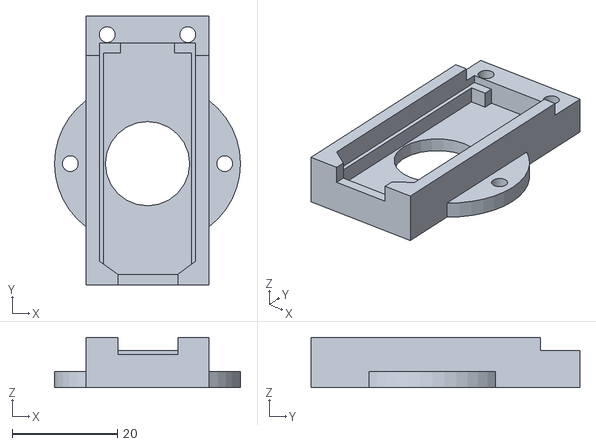
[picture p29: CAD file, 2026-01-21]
3d_parts/NanoHolderA.stl
35.3 x 51.0 x 9.50

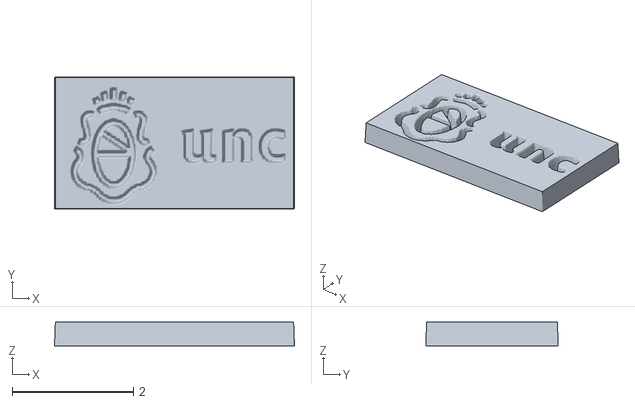
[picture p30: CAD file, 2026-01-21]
3d_parts/logo unc.stl
3.95 x 2.18 x 0.394

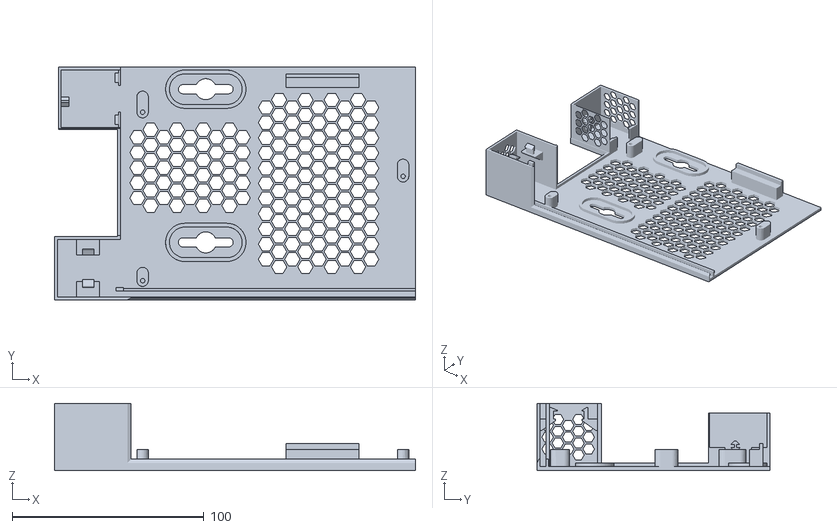
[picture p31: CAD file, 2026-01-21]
3d_parts/belkin_rt3200_base.stl
188.5 x 121.5 x 35.0

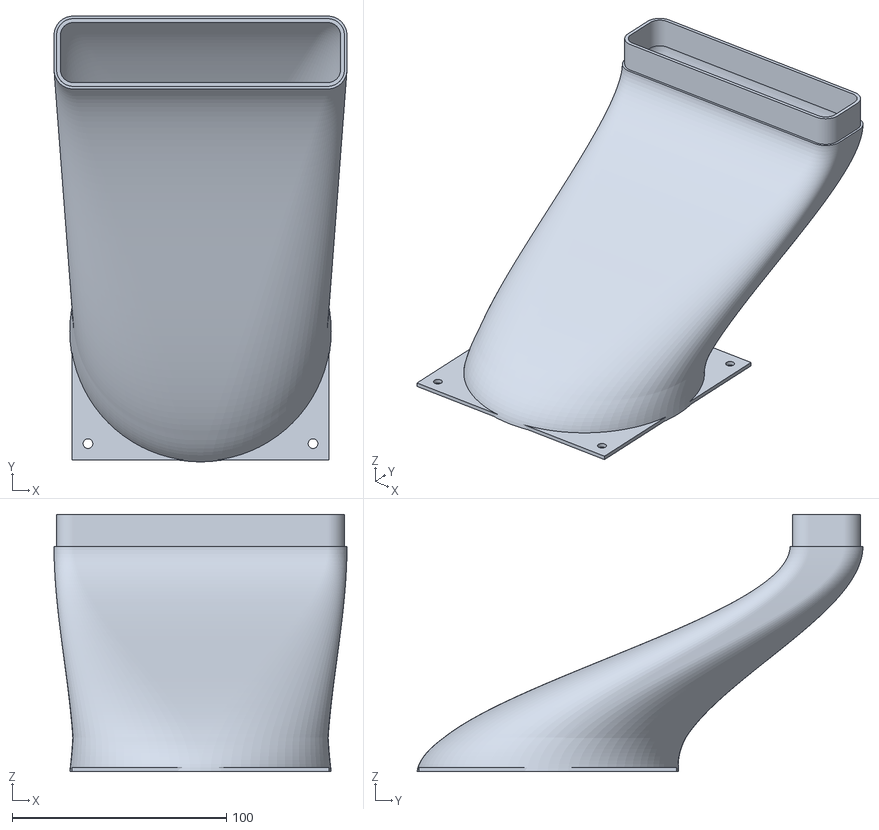
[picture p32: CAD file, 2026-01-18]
3d_parts/curved_intake_duct.stl
136.7 x 208.0 x 120.0

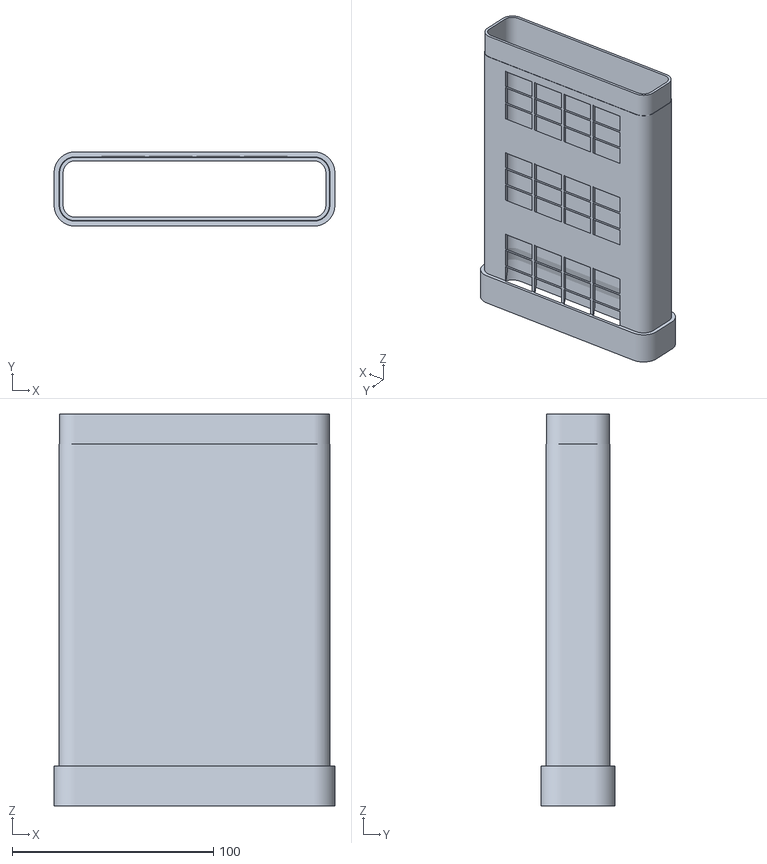
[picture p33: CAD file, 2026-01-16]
3d_parts/airflow_chimney_duct_3levels.stl
139.7 x 37.0 x 195.0

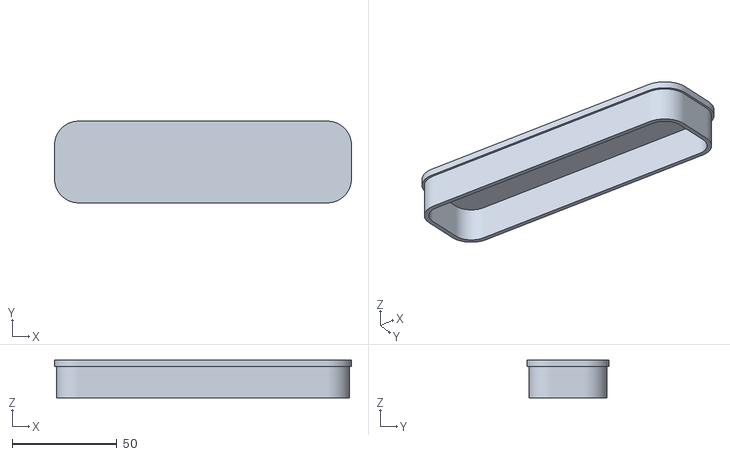
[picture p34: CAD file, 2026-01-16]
3d_parts/chimney_duct_cover.stl
141.7 x 39.0 x 18.0

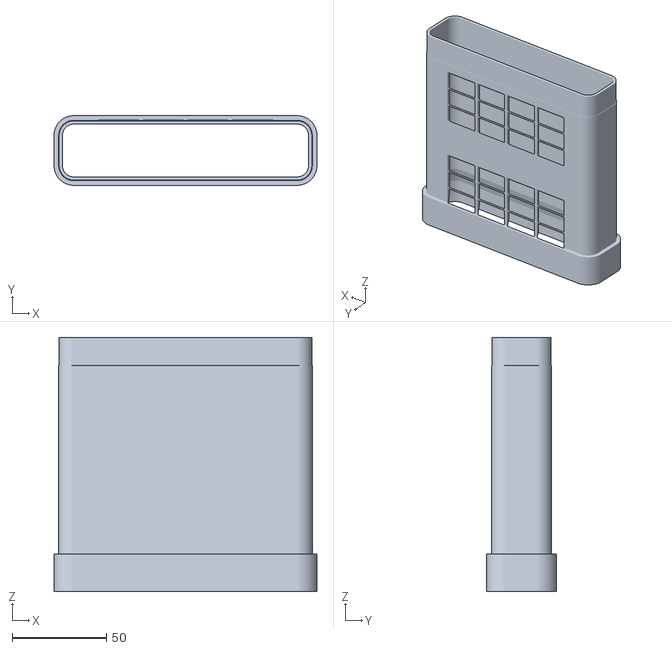
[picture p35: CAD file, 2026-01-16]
3d_parts/airflow_chimney_duct_2levels.stl
139.7 x 37.0 x 135.0

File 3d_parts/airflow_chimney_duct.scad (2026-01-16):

// tubo.scad - CORREGIDO PARA ENCASTRE Y FUSIÓN
$fn = 80;

niveles_por_modulo = 2; 
dist_niveles = 60;
altura_cuerpo = niveles_por_modulo * dist_niveles; 

rect_x = 134.7; 
rect_y = 32;    
radio_final = 8;
grosor_pared = 2.0;
tolerancia = 0.5; // Aumentada ligeramente para facilitar encastre

chimenea_larga();

module chimenea_larga() {
    union() {
        difference() {
            // --- CUERPO EXTERIOR ---
            union() {
                // 1. Zócalo Hembra inferior (Reforzado y más ancho)
                linear_extrude(20) 
                    offset(r = grosor_pared + tolerancia) perfil_rect(0);
                
                // 2. Cuerpo principal (Ahora nace desde Z=0 para una fusión total)
                linear_extrude(altura_cuerpo) 
                    perfil_rect(0);
            }
            
            // --- VACIADO INTERIOR ---
            union() {
                // 3. HUECO HEMBRA (Ajustado para el saxofón ya impreso)
                // Usamos '+' tolerancia para que el hueco sea más grande que el macho
                translate([0,0,-1]) 
                    linear_extrude(16) 
                        perfil_rect(tolerancia); 
                
                // 4. RAMPA DE TRANSICIÓN (Aerodinámica y anti-soporte)
                hull() {
                    translate([0,0,15]) linear_extrude(0.1) perfil_rect(tolerancia);
                    translate([0,0,15 + 10]) linear_extrude(0.1) perfil_rect(-grosor_pared);
                }
                
                // 5. TÚNEL DE AIRE SUPERIOR
                translate([0,0,15 + 10]) 
                    linear_extrude(altura_cuerpo + 10) perfil_rect(-grosor_pared);
            }
            
            // --- BRANQUIAS SEGMENTADAS ---
            for(nivel = [0 : niveles_por_modulo - 1]) {
                z_base = nivel * dist_niveles;
                for(j = [0:2], c = [0:3]) { 
                    x_pos = - (rect_x-40)/2 + c*((rect_x-40)/4) + (rect_x-40)/8;
                    translate([x_pos, rect_y/2, z_base + 25 + j*12])
                        rotate([45, 0, 0]) 
                            cube([(rect_x-40)/4 - 2, 25, 8], center=true);
                }
            }
        }

        // --- CONECTOR MACHO SUPERIOR ---
        // Para seguir apilando más tubos
        translate([0, 0, altura_cuerpo]) {
            difference() {
                linear_extrude(15) perfil_rect(-tolerancia/2); 
                translate([0,0,-1]) linear_extrude(17) perfil_rect(-grosor_pared);
            }
        }
    }
}

module perfil_rect(extra) {
    offset(r = radio_final + extra) 
        square([rect_x - 2*radio_final, rect_y - 2*radio_final], center = true);
}

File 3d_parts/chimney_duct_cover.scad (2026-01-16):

// TAPA_FINAL_CHIMENEA.scad
// Diseñada para cerrar el sistema modular y forzar el flujo de aire por las branquias.
$fn = 80;

// Medidas coincidentes con tubo.scad para un encastre perfecto
rect_x = 134.7; 
rect_y = 32;    
radio_final = 8;
grosor_pared = 2.0;
tolerancia = 0.5; 

tapa_chimenea();

module tapa_chimenea() {
    color("IndianRed")
    union() {
        // 1. PLACA SUPERIOR (El techo que sella el tubo)
        // La hacemos un poco más ancha para que sea fácil de agarrar
        linear_extrude(3) 
            offset(r = grosor_pared + tolerancia + 1) 
                perfil_rect(0);
        
        // 2. FALDA DE ENCASTRE (Hembra)
        // Esta parte abraza el conector macho superior del último tubo
        translate([0, 0, -15]) {
            difference() {
                // Exterior de la falda
                linear_extrude(15) 
                    offset(r = grosor_pared + tolerancia) 
                        perfil_rect(0);
                
                // Hueco interno (Hembra)
                // Usamos la misma lógica de tolerancia que en la base del tubo
                translate([0, 0, -1]) 
                    linear_extrude(17) 
                        perfil_rect(tolerancia);
            }
        }
    }
}

module perfil_rect(extra) {
    offset(r = radio_final + extra) 
        square([rect_x - 2*radio_final, rect_y - 2*radio_final], center = true);
}

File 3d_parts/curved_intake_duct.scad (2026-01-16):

// --- PARÁMETROS FINALES (COMPATIBLE CON TUBO.SCAD) ---
$fn = 80;

// Medidas cooler Bosser
ancho_placa_base = 120.0;     
distancia_agujeros_base = 105.0; 
diametro_tornillo = 4.5;
cooler_diam_interno = 116.0; 

// Medidas salida (Coincidentes con tubo.scad)
rect_x = 134.7;
rect_y = 32;
radio_final = 8; 

// Trayecto
altura_saxofon = 105;   // Altura de la curva
desplazamiento_y = 130; 
grosor_pared = 2.0;     // Pared robusta para mejor impresión
tolerancia = 0.4;       // Misma tolerancia que en tubo.scad

// --- MOTOR DE GENERACIÓN ---

module perfil_interpolado(t, offset_manual) {
    ease = t * t * (3 - 2 * t); 
    z_pos = t * altura_saxofon;
    y_pos = ease * desplazamiento_y;

    // Flare inferior (solo en la base del cooler)
    max_flare_inf = (ancho_placa_base - cooler_diam_interno) / 2;
    flare_inf = (t < 0.15) ? (1 - t/0.15) * max_flare_inf : 0;

    radio_actual = (cooler_diam_interno/2) * (1 - ease) + radio_final * ease;
    
    size_x = (cooler_diam_interno - 2*(cooler_diam_interno/2)) * (1 - ease) + (rect_x - 2*radio_final) * ease;
    size_y = (cooler_diam_interno - 2*(cooler_diam_interno/2)) * (1 - ease) + (rect_y - 2*radio_final) * ease;

    translate([0, y_pos, z_pos]) {
        linear_extrude(height = 0.1) {
            offset(r = radio_actual + offset_manual + flare_inf) {
                square([max(0.01, size_x), max(0.01, size_y)], center = true);
            }
        }
    }
}

module generar_loft(extra_offset) {
    pasos = 60; 
    for (i = [0 : pasos - 1]) {
        hull() {
            perfil_interpolado(i / pasos, extra_offset);
            perfil_interpolado((i + 1) / pasos, extra_offset);
        }
    }
}

// --- ENSAMBLE ---

union() {
    // 1. CUERPO CURVO (Saxofón)
    difference() {
        generar_loft(grosor_pared/2);
        generar_loft(-grosor_pared/2);
    }

    // 2. CONECTOR MACHO (Para encastrar en tubo.scad)
    // Se posiciona al final de la curva
    translate([0, desplazamiento_y, altura_saxofon]) {
        difference() {
            // El macho debe ser ligeramente más pequeño que el hueco hembra
            linear_extrude(15) 
                offset(r = radio_final - tolerancia/2) 
                    square([rect_x - 2*radio_final, rect_y - 2*radio_final], center = true);
            
            // Hueco interno para el aire
            translate([0,0,-1])
                linear_extrude(17) 
                    offset(r = radio_final - grosor_pared) 
                        square([rect_x - 2*radio_final, rect_y - 2*radio_final], center = true);
        }
    }

    // 3. PLACA BASE (Lado Ventilador)
    color("DarkSlateGray")
    difference() {
        translate([0, 0, 1])
            cube([ancho_placa_base, ancho_placa_base, 2], center = true);
        
        generar_loft(extra_offset = -grosor_pared/2);
        
        for(x=[-1,1], y=[-1,1]) 
            translate([x*distancia_agujeros_base/2, y*distancia_agujeros_base/2, -1]) 
                cylinder(d = diametro_tornillo, h = 5);
    }
}

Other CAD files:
3d_parts/CE3PRO_librerouter_rack.stl
rack_design/drawer_stop.f3d

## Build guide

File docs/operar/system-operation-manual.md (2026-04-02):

# System operation manual: FCEFyN testbed

Vision, ownership, connectivity, and typical incidents for operators. Testbed procedures and commands can be found in [Routine operations](lab-routine-operations.md).

---

## Mission summary

A testbed that can be accessed/operates remotely by allowed users validates **OpenWrt** and **LibreMesh** firmware automatically with **Labgrid** and **pytest**, on physical rack DUTs and, when applicable, emulated targets (QEMU). It integrates [openwrt-tests](https://github.com/aparcar/openwrt-tests) and the [libremesh-tests](https://github.com/francoriba/libremesh-tests) fork. Availability depends on the academic calendar and shared lab use; it is not a 24x7 service unless explicitly agreed.

---

## Technical summary

An orchestration host, either manually operated or running a CI runner, coordinates the execution of tests and infrastructure components. It runs a [Labgrid exporter](https://labgrid.readthedocs.io/en/stable/man/exporter.html), a [TFTP server](../configuracion/tftp-server.md), switch control commands, and [Pytest](https://docs.pytest.org/en/stable/) test suites.

Device access and scheduling are handled by a [Labgrid coordinator](https://labgrid.readthedocs.io/en/latest/man/coordinator.html), referred to as the [**global coordinator**](../diseno/openwrt-tests-onboarding.md/#1-global-coordinator-architecture) and provided by openwrt-tests. This component manages locks and reservations over devices and their associated labgrid remote [resources and places](https://labgrid.readthedocs.io/en/stable/overview.html#remote-resources-and-places).

The physical infrastructure is organized in a [DIY rack](../diseno/diy-rack.md), which includes a managed switch, power control mechanisms such as PoE and relays, USB serial adapters, Ethernet connections to the Devices Under Test (DUTs) and a fan/cooler.

---

## Ownership and support {: #ownership-and-support }

| Role | Responsibility |
|---|---|
| **UNC / FCEFyN Educative Community** | Rack maintenance, network infrastructure changes, onboarding of new devices, assistance for new contributors of openwrt-tests/libremesh-tests. |

Current support contacts from FCEFyN:

* [Ing. Jorge, Javier Alejandro](mailto:javier.jorge@unc.edu.ar)
* [Riba, Franco](mailto:franco.riba@mi.unc.edu.ar)
* [Casanueva, María Constanza](mailto:ccasanueva@mi.unc.edu.ar)

Auxiliar support contacts from our friends from related projects: 

* [Paul Spooren](mailto:mail@aparcar.org) (openwrt-tests project owner)
* [Ilario Gelmetti](mailto:iochesonome@gmail.com) (LibreMesh main representative)
---

## Stakeholders and consumers

| Actor | Usage |
|---|---|
| **FCEFyN lab maintainers** | Development, manual test runs, toubleshooting, debugging. |
| **Global coordinator (Aparcar)** | Manages locks for all DUTs; lab exporter registers via WireGuard. |
| **CI runners (openwrt-tests)** | Jobs that reserve places and run pytest with `LG_PLACE` / `LG_IMAGE`. |
| **CI runners (libremesh-tests)** | Jobs that reserve places, change VLAN dynamically, and run pytest. |

---

## Architecture (high level)

High-level topology: [testbed overview on the home page](../index.md#testbed-overview) and diagram asset `docs/img/diagrams/general-design-overview.png`.

---

## Network connectivity

Summary of flows relevant to operations and incidents. Host firewall detail: [host-config](../configuracion/host-config.md). DUT Internet egress: [duts-config - Internet access](../configuracion/duts-config.md#internet-access-opkg).

| Direction | Scope | Source / destination | Protocol | Port | Notes |
|---|---|---|---|---|---|
| INPUT | Inside | Admin → host | SSH | 22 | Orchestrator management (LAN/VPN per policy). |
| INPUT | Inside | Host → DUT | SSH | 22 | Via `labgrid-bound-connect` (static isolated VLAN per DUT). |
| INPUT | Inside | DUT → host | TFTP | 69/udp | Initramfs load from host (udp). |
| INPUT | Inside | Host → switch | SSH | 22 | VLAN management (e.g. `switch-fcefyn`). |
| OUTPUT | Cross | Exporter → global coordinator | WebSocket | 20408 | To coordinator on datacenter VM via WireGuard. |
| INPUT | Public | Internet → Oracle VPS | HTTPS | 443 | Public Grafana (TLS on Nginx). |
| INPUT | Public | Internet → VPS | SSH | 22 | VPS admin; Grafana reverse tunnel goes **from** the lab. |
| OUTPUT | Cross / Public | DUT → Internet | HTTP/S | 80, 443, … | Per lab gateway NAT; see duts-config. |

---

## Automation

Automation of necessary operations is achieved using: 

- **Ansible:** `ansible/playbook_labgrid.yml` (exporter, places, users). See [ansible-labgrid](../configuracion/ansible-labgrid.md).
- **Dynamic VLAN:** `labgrid-switch-abstraction` (used by libremesh-tests in CI); manual ops: `switch-vlan`. Details in [Lab architecture](../diseno/lab-architecture.md).

---

## Observability

The infrastructure includes support for a [public grafana setup](../configuracion/grafana-public-access.md) which is possible using this [observavility stack](../configuracion/observabilidad.md).

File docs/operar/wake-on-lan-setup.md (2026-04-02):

# Wake-on-LAN - Lenovo ThinkPad T430 (orchestration host)

The Wake-on-LAN setup allows to power on the orchestration host remotely if it is off. WoL lets testbed admins power the lab from outside without physical access.

**Context:** If powered-off, the host does not receive ZeroTier traffic. The WoL packet must be sent from an always-on device on the same LAN (the OpenWrt gateway router, which runs ZeroTier). See [gateway 5.8](../configuracion/gateway.md#58-wake-on-lan-remote-host-power-on) for the full remote flow.

---

## 1. Prerequisites

- Active Ethernet interface (on our T430 host: `enp0s25`).
- Ethernet cable to switch/gateway (same VLAN/LAN as the orchestration host).

---

## 2. BIOS - Enable Wake-on-LAN

BIOS must allow WoL. On ThinkPad T430:

### 2.1 Enter BIOS

1. Reboot the laptop.
2. When the ThinkPad logo appears, press **F1**.
3. **BIOS Setup Utility** opens.

### 2.2 Enable Wake-on-LAN

Navigate to: `Config > Network > Wake On Lan`

Set `Wake on LAN = AC Only` (AC power only).

Save and exit.

---

## 3. Linux - ethtool (after boot)

After Ubuntu boots, enable WoL on the Ethernet interface.

### 3.1 Check interface and state

```bash
ip link show
# Identify Ethernet (on T430: enp0s25)

sudo ethtool enp0s25
```

In the output, find `Wake-on:`. If it shows `d` (disabled), enable it.

### 3.2 Enable WoL

```bash
sudo ethtool -s enp0s25 wol g
```

`g` = magic packet (standard WoL). After this, `ethtool enp0s25` should show `Wake-on: g`.

### 3.3 Behavior after reboot

!!! warning "WoL persistence"
    Without extra configuration, the setting is lost on reboot. Use the systemd persistence service (section 4) or the Ansible role (section 5).

---

## 4. Persistence - systemd service (manual)

To keep WoL enabled after each boot, use a systemd unit that runs `ethtool` at startup.

### 4.1 Create the service

```bash
sudo nano /etc/systemd/system/wol.service
```

Content (adjust `enp0s25` if the Ethernet name differs):

```ini
[Unit]
Description=Enable Wake On LAN
After=NetworkManager.service
Wants=NetworkManager.service

[Service]
Type=oneshot
ExecStartPre=/bin/sleep 5
ExecStart=/usr/sbin/ethtool -s enp0s25 wol g
RemainAfterExit=yes

[Install]
WantedBy=multi-user.target
```

!!! note "Order vs NetworkManager"
    The service must run **after** NetworkManager. With `After=network.target`, NM may reset `Wake-on` to `d` after the service sets `g`. `ExecStartPre=sleep 5` gives NM time to finish.

### 4.2 Enable the service

```bash
sudo systemctl daemon-reload
sudo systemctl enable wol
sudo systemctl start wol
```

On each reboot, the service enables WoL automatically.

### 4.3 Verification

```bash
sudo systemctl status wol
sudo ethtool enp0s25
# Should show Wake-on: g
```

---

## 5. Automation with Ansible

The Ansible `wol` role creates and enables the systemd service idempotently. See [host-config 8.4](../configuracion/host-config.md#84-wake-on-lan-persistence).

Run:

```bash
ansible-playbook -i ansible/inventory/hosts.yml ansible/playbook_testbed.yml --tags wol -K
```

---

## 6. Get the host MAC

To send the magic packet from the gateway (or another LAN host), you need the Lenovo MAC.

```bash
ip link show enp0s25
# Find "link/ether XX:XX:XX:XX:XX:XX"
```

Or:

```bash
cat /sys/class/net/enp0s25/address
```

Store that MAC (e.g. as `LABGRID_HOST_MAC` in gateway docs) for `wakeonlan` or equivalents.

---

## 7. Send WoL (from gateway or LAN)

The magic packet must come from a device on the same subnet as the Lenovo (or broadcast). The gateway router (always on) is the natural sender when accessing remotely via ZeroTier.

### 7.1 OpenWrt (current setup: TL-WDR3500)

Testbed gateway is OpenWrt with `etherwake` installed and ZeroTier for remote access. Send WoL on a testbed VLAN:

```bash
ssh root@<ZeroTier-IP-of-router> 'etherwake -i eth0.100 00:21:cc:c4:25:3b'
```

See [gateway 5.8](../configuracion/gateway.md#58-wake-on-lan-remote-host-power-on) for full router configuration.

### 7.2 MikroTik (deprecated - previous setup)

If a MikroTik were used again as testbed gateway:

```routeros
/tool wol mac=00:21:CC:C4:25:3B interface=LAB-TRUNK
```

### 7.3 Via ZeroTier (full flow)

1. SSH to OpenWrt router via ZeroTier: `ssh root@10.246.3.95`
2. Send WoL: `etherwake -i eth0.100 00:21:cc:c4:25:3b`
3. Wait ~2 min for the Lenovo to boot.
4. SSH to host via ZeroTier: `ssh laryc@10.246.3.118`

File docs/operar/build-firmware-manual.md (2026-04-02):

# Manual firmware build

Quick guide to build firmware images for use in the lab (`LG_IMAGE`, TFTP, flash). The same DUT profiles apply whether the stack is **vanilla OpenWrt**, **LibreMesh**, or **LibreRouter OS**.

---

## Build config per DUT

Pick **Target System**, **Subtarget**, and **Target Profile** in `make menuconfig` from this table (or the device vendor docs).

| DUT | Arch | Subtarget | Profile |
|-----|---|---|---|
| Belkin RT3200 | Mediatek (ARM) | mt7622 | linksys_e8450-ubi |
| Banana Pi R4 | Mediatek (ARM) | filogic | bananapi_bpi-r4 |
| OpenWRT One | Mediatek (ARM) | filogic | openwrt_one |
| LibreRouter 1 | ath79 (MIPS 24Kc) | generic | librerouter_librerouter-v1 |
| Gateway TL-WDR3500 | ath79 (MIPS 74Kc) | generic | tplink_tl-wdr3500-v1 |
| **QEMU x86-64** | x86 | x86_64 | generic |
| **QEMU Malta BE** | malta | be | generic |
| **QEMU armsr-armv8** | armsr | armv8 | generic |

**Path in menuconfig:** Target System → (Arch) → Subtarget → Target Profile → (Profile).

---

## 1. Vanilla OpenWrt

Use when tests or workflows expect **stock OpenWrt** packages only (no `lime-*`, no LibreRouterOS bundle).

1. **Clone** OpenWrt (pin a release branch or tag, e.g. `v23.05.5`):

   ```bash
   git clone -b v23.05.5 --single-branch https://git.openwrt.org/openwrt/openwrt.git
   cd openwrt
   ```

2. **Feeds** (defaults only):

   ```bash
   ./scripts/feeds update -a
   ./scripts/feeds install -a
   ```

3. **Configure** target and profile: `make menuconfig` using the [table above](#build-config-per-dut). Add any extra packages the suite requires.

4. **Build:**

   ```bash
   make -j$(nproc)
   ```

Artifacts: `bin/targets/<target>/<subtarget>/`.

**References:** [OpenWrt build system](https://openwrt.org/docs/guide-developer/build-system/use-buildsystem), [install build dependencies](https://openwrt.org/docs/guide-developer/build-system/install-buildsystem).

---

## 2. LibreMesh (lime-packages)

Use for **community mesh** images: add the LibreMesh feeds and select `lime-*` packages (as required by the test suite or [libremesh-tests](https://github.com/francoriba/libremesh-tests)).

**1. Clone OpenWrt and enter build root**

```bash
git clone -b v23.05.5 --single-branch https://git.openwrt.org/openwrt/openwrt.git
cd openwrt
```

**2. Feeds - OpenWrt default + LibreMesh**

```bash
cp feeds.conf.default feeds.conf
cat << 'EOF' >> feeds.conf

src-git libremesh https://github.com/libremesh/lime-packages.git;v2024.1
src-git profiles https://github.com/libremesh/network-profiles.git
EOF
```

`v2024.1` matches OpenWrt 23.05.5. Using `master` without a tag typically tracks OpenWrt 24.10+.

**3. Update and install packages**

```bash
./scripts/feeds update -a
./scripts/feeds install -a
```

**4. `make menuconfig` - Deselect**

| Location | Action |
|---|---|
| Image configuration → Separate feed repositories → Enable feed **libremesh** | Deselect |
| Image configuration → Separate feed repositories → Enable feed **profiles** | Deselect |
| Base system → **dnsmasq** | Deselect |
| Network → **odhcpd-ipv6only** | Deselect |

**5. `make menuconfig` - Select LibreMesh (example set)**

| Location |
|----------|
| LibreMesh → **babeld-auto-gw-mode** |
| LibreMesh → Offline Documentation → **lime-docs-minimal** |
| LibreMesh → **lime-app** |
| LibreMesh → **lime-hwd-openwrt-wan** |
| LibreMesh → **lime-proto-anygw** |
| LibreMesh → **lime-proto-babeld** |
| LibreMesh → **lime-proto-batadv** |
| LibreMesh → **shared-state** → shared-state-babeld_hosts |
| LibreMesh → **shared-state** → shared-state-bat_hosts |
| LibreMesh → **shared-state** → shared-state-nodes_and_links |

Set **Target System / Profile** from the [DUT table](#build-config-per-dut).

**5.1 Virtual targets with vwifi (optional)**

For mesh tests in QEMU (x86-64, Malta, armsr-armv8) with virtual WiFi:

| Step | Action |
|---|---|
| Feeds | Add to `feeds.conf`: `src-git vwifi https://github.com/javierbrk/vwifi_cli_package` |
| Update | `./scripts/feeds update vwifi && ./scripts/feeds install -a` |
| Menuconfig | Network → **vwifi** |
| wpad | Include **wpad-basic-mbedtls** (needed for batman on vwifi) |

**6. Build**

```bash
make -j$(nproc)
```

Output layout: `bin/targets/.../`.  
Upstream: [libremesh.org development](https://libremesh.org/development.html).

---

## 3. LibreRouter OS

[LibreRouterOS](https://gitlab.com/librerouter/librerouteros) is also an OpenWrt-based tree with feeds and defaults oriented to **LibreRouter** hardware with LibreMesh networking capabilities. Prebuilt images: [GitLab releases](https://gitlab.com/librerouter/librerouteros/-/releases).

**Dependencies:** Same base toolchain as OpenWrt ([install packages](https://openwrt.org/docs/guide-developer/build-system/install-buildsystem) for your distro).

**Build steps (from upstream README)**

1. Clone and enter the repo:

   ```bash
   git clone https://gitlab.com/librerouter/librerouteros.git
   cd librerouteros
   ```

   Use a **tag or branch** that matches the release you need (e.g. check [branches / tags](https://gitlab.com/librerouter/librerouteros/-/tags) on GitLab).

2. Feeds:

   ```bash
   ./scripts/feeds update -a
   ./scripts/feeds install -a
   ```

3. Default configuration:

   ```bash
   cp configs/default_config .config
   ```

4. **Non-LibreRouter board:** apply the vendor patch so cmdline defaults match generic hardware:

   ```bash
   patch -p1 < configs/revert-cmdline-config.patch
   ```

5. Optional: `make menuconfig` to change target profile (see [DUT table](#build-config-per-dut) for lab devices) or packages.

6. Build:

   ```bash
   make -j$(nproc)
   ```

Firmware appears under `bin/` as in standard OpenWrt.

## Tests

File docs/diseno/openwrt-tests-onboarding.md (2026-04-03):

# Onboarding to openwrt-tests

Process for contributing hardware from a local lab to the [openwrt-tests](https://github.com/openwrt/openwrt-tests) ecosystem. Covers architecture, exporter connection, SSH keys, Ansible, and the step sequence to integrate DUTs with the upstream coordinator.

---

## 1. Global-coordinator architecture

The openwrt-tests **global-coordinator** is a **VM in a datacenter** with a public IP, maintained by Paul (aparcar). All remote labs connect to it over **WireGuard**. **GitHub Actions self-hosted runners** also run on that VM and reach labs through the WireGuard tunnel to run tests.

```mermaid
flowchart TD
    subgraph datacenter ["Datacenter VM"]
        GC["labgrid-coordinator :20408"]
        RUNNERS["GitHub Actions runners"]
    end

    subgraph lab_aparcar ["Aparcar lab"]
        EXP_A["labgrid-exporter"]
        BC_A["labgrid-bound-connect"]
        DUT_A["DUTs"]
    end

    subgraph lab_fcefyn ["FCEFyN lab"]
        EXP_F["labgrid-exporter"]
        BC_F["labgrid-bound-connect"]
        DUT_F["DUTs"]
    end

    RUNNERS -- "1" --> GC
    EXP_A -- "2" --> GC
    EXP_F -- "2" --> GC
    RUNNERS -- "3" --> BC_A
    RUNNERS -- "3" --> BC_F
    BC_A -- "4" --> DUT_A
    BC_F -- "4" --> DUT_F
```

| # | Connection | Detail |
|---|---|---|
| 1 | Runners → Coordinator | WebSocket localhost:20408 (reserve / lock / unlock) |
| 2 | Exporter → Coordinator | WebSocket via WireGuard (register resources) |
| 3 | Runners → bound-connect | SSH via WireGuard (LG_PROXY=labgrid-X) |
| 4 | bound-connect → DUTs | socat with so-bindtodevice on correct VLAN interface |

All connections between labs and the VM traverse a **WireGuard** tunnel (point-to-point VPN).

| Component | Location | Role |
|---|---|---|
| **Coordinator** | Datacenter VM (public IP) | WebSocket server. Registers places (`places.yaml`), coordinates reservations and locks. Does **not** proxy SSH. |
| **GitHub runners** | Same VM | Self-hosted runners executing CI workflow jobs against remote DUTs via `LG_PROXY`. |
| **WireGuard** | Between each lab and the VM | Tunnel so runners can SSH to lab hosts and lab exporters can reach the coordinator. |
| **Exporter** | Lab host | Registers local DUT resources (serial, power, network) with the coordinator over WebSocket. |
| **`labgrid-bound-connect`** | Lab host | SSH ProxyCommand invoked by the runner. Uses `socat` with `so-bindtodevice` to connect to a DUT IP on the correct VLAN interface. |
| **Place** | Configuration | Abstraction of one DUT: resources (serial, power, SSH target), boot strategy, firmware. |

See [CI execution flow](openwrt-tests-ci-flow.md) for the full sequence of how a workflow job runs end-to-end.

!!! note "WireGuard latency"
    If the WireGuard link between the datacenter and the lab is poor (high latency), tests may fail on timeout. The maintainer cited this as a known issue with labs in Eastern Europe.

---

## 2. Exporter connection to the coordinator

The exporter initiates the connection *toward* the coordinator.

```bash
labgrid-exporter --coordinator ws://<coordinator_host>:<port> /etc/labgrid/exporter.yaml
```

In practice the exporter runs as a systemd service (`labgrid-exporter.service`) and the coordinator is set in config or environment (`LG_COORDINATOR`).

**What you need from the upstream maintainer:**

- Coordinator URL (host and WebSocket port).
- Coordinator SSH public key to add to `authorized_keys` for user `labgrid-dev` on the lab (already included in the openwrt-tests Ansible playbook).

**Firewalls / NAT:** The lab must be able to connect *outbound* to the coordinator (outgoing WebSocket). The coordinator then uses SSH proxy over the same path to reach DUTs.

---

## 3. SSH access and proxy

When a developer or CI runs `labgrid-client console` or `labgrid-client ssh`, the flow is:

```
client → SSH to coordinator (jump host) → SSH to exporter → serial/SSH to DUT
```

The coordinator must SSH to the lab host. That is done with the coordinator public key in `authorized_keys` for user `labgrid-dev`.

### 3.1 Keys involved

| Key | Where it is configured | Purpose |
|-----|---|---|
| **Coordinator** public key | `~labgrid-dev/.ssh/authorized_keys` on the lab | Lets the coordinator SSH to the lab (proxy to DUTs). Deployed by Ansible. |
| Each **developer** public key | `labnet.yaml → developers.<github_user>.sshkey` | Lets the developer reach lab DUTs via `LG_PROXY`. |
| Lab **WireGuard** public key | Manual exchange with maintainer | Establishes VPN tunnel between lab and coordinator. |

The coordinator key is already in the openwrt-tests Ansible playbook; it deploys when you run the playbook.

#### Developer keys in `labnet.yaml`

Each developer who needs remote DUT access needs:

1. Their **personal SSH public key** (ed25519) in the `developers:` section of `labnet.yaml`.
2. Their **GitHub username** as identifier.
3. To be listed in `labs.<lab>.developers` for the target lab.

The openwrt-tests Ansible playbook iterates `labs.<lab>.developers`, looks up each `sshkey` in `developers:`, and appends to `~labgrid-dev/.ssh/authorized_keys` on the lab host. Each developer can then SSH as `labgrid-dev` to use `labgrid-client`.

---

## 4. Ansible: control node and managed node

| Role | In upstream openwrt-tests |
|---|---|
| **Control node** | Maintainer machine (Paul/Aparcar) that runs `ansible-playbook`. |
| **Managed node** | The lab host (the Lenovo in our case). |

For the upstream maintainer to apply the playbook to the FCEFyN lab:

1. **SSH to the lab host** (access as `labgrid-dev` or inventory user).
2. **Control node public key** in `authorized_keys` on the managed node.

This is coordinated manually: the maintainer shares their public key and the lab owner adds it to `authorized_keys`, or the lab owner runs the playbook locally (if they have inventory access).

---

## 5. PR contents to contribute hardware

A PR to openwrt-tests to add a new lab includes:

| File | Description |
|---|---|
| `labnet.yaml` | Lab entry under `labs:`, devices, instances, developer SSH keys. |
| `ansible/files/exporter/<lab>/exporter.yaml` | Exporter config: places with resources (serial, power, SSH target). |
| `ansible/files/exporter/<lab>/netplan.yaml` | Host network config (VLANs). |
| `ansible/files/exporter/<lab>/dnsmasq.conf` | DHCP/TFTP for lab VLANs. |
| `ansible/files/exporter/<lab>/pdudaemon.conf` | PDUDaemon config (power control). |
| `docs/labs/<lab>.md` | Lab documentation: hardware, DUTs, maintainers. |

### 5.1 Developers in labnet.yaml

Each developer registers with their **GitHub username** and **personal SSH public key** (ed25519). Include the upstream maintainer (`aparcar`) so they can debug.

```yaml
labs:
  labgrid-fcefyn:
    developers:
      - francoriba     # GitHub username
      - aparcar         # upstream maintainer (debugging)

developers:
  francoriba:
    sshkey: ssh-ed25519 AAAA...  # developer personal key
```

### 5.2 Generate SSH key for a new developer {: #52-generate-ssh-key-for-new-developer }

```bash
ssh-keygen -t ed25519 -C "github_username" -f ~/.ssh/id_ed25519
cat ~/.ssh/id_ed25519.pub
```

Add the public key (`cat` output) to `labnet.yaml` under `developers.<github_user>.sshkey`. The private key stays on the developer PC.

To use another PC, copy the key pair (`id_ed25519` + `id_ed25519.pub`) to `~/.ssh/` on the new machine with `chmod 600` on the private key. One `labnet.yaml` entry covers all PCs for the same developer.

!!! warning "Do not confuse with host keys"
    Orchestration host keys (`/etc/wireguard/public.key`, keys in `~labgrid-dev/.ssh/`) serve other purposes. Under `labnet.yaml → developers` only put **personal** keys for people who will run `labgrid-client` from laptops.

---

## 6. Onboarding sequence

Suggested order: first the **WireGuard** tunnel (the coordinator VM must register the lab peer; without the tunnel there is no return SSH from the VM). In parallel prepare the **PR** with inventory, exporter, and developers' **personal** SSH keys ([5.2](#52-generate-ssh-key-for-new-developer)). After merge, the openwrt-tests **playbook_labgrid** deploys `authorized_keys` and services on the host.

```mermaid
sequenceDiagram
    participant Lab as Lab_owner_host
    participant Maint as Upstream_maintainer
    participant DC as VM_coordinator_runners
    participant PR as PR_openwrt_tests

    Lab->>Lab: WireGuard keypair on lab host
    Lab->>Maint: WireGuard public key
    Maint->>Lab: Peer config IP endpoint server pubkey
    Maint->>DC: Register lab peer on WireGuard server
    Lab->>Lab: Deploy wg0 Ansible wireguard or manual
    Lab->>DC: WireGuard tunnel active handshake
    Lab->>Lab: Developer SSH ed25519 keys section_5_2
    Lab->>PR: PR labnet developers exporter netplan dnsmasq pdu docs
    Maint->>PR: Review and merge
    Maint->>Lab: WebSocket coordinator URL if needed
    Lab->>Lab: playbook_labgrid openwrt_tests authorized_keys exporter
    Lab->>DC: Outbound exporter WebSocket
    DC->>Lab: SSH to lab via tunnel proxy DUTs
    DC->>DC: Places registered CI runners on VM
```

### 6.1 Checklist

* Generate WireGuard keypair on the lab host and send the public key to the maintainer (Matrix)
* Receive WireGuard config from the maintainer (assigned IP, endpoint, server public key)
* Apply tunnel on the host: Ansible role `wireguard` in `fcefyn_testbed_utils` or manual `wg0` config. See [section 9](#wireguard-ansible-fcefyn)
* Verify tunnel: `sudo wg show wg0` (recent handshake)
* Per developer: generate personal ed25519 key ([5.2](#52-generate-ssh-key-for-new-developer)) and list `labs.<lab>.developers` + `developers.<github_user>.sshkey` in `labnet.yaml`
* Prepare lab files: `exporter.yaml`, `netplan.yaml`, `dnsmasq.conf`, `pdudaemon.conf`
* Document the lab in `docs/labs/<lab>.md` (upstream)
* Open PR to openwrt-tests with the above
* After merge: run `playbook_labgrid.yml` from openwrt-tests on the host (or have the maintainer run it): coordinator SSH key ends up in `~labgrid-dev/.ssh/authorized_keys` and exporter is configured
* Confirm `labgrid-exporter` points at the coordinator WebSocket
* Verify places: `labgrid-client places` (with `LG_PROXY` per upstream README)

---

## 7. Maintainer coordination

| What you need | How to get it |
|---|---|
| WireGuard config (IP, endpoint, peer key) | Send lab WireGuard public key to the maintainer; receive data back. |
| Coordinator URL | Ask the maintainer or see project docs. |
| Coordinator SSH key | Already in Ansible playbook; deploys when applied. Alternatively the maintainer provides it. |
| Ansible access to lab | Lab owner gives SSH to the maintainer (Ansible control node public key), or runs the playbook locally. |
| VLAN configuration | Defined by the lab owner for their hardware; files go in the PR. |

---

## 8. Differences from libremesh-tests

| Aspect | openwrt-tests (upstream) | libremesh-tests (fork) |
|---|---|---|
| Coordinator | Global (datacenter VM) | Same global coordinator |
| Ansible control node | Aparcar infrastructure | The lab itself (self-setup) |
| VLANs | Dynamic per test (isolated default, 192.168.1.x) | Dynamic per test (mesh VLAN 200, 10.13.x.x for multi-node) |
| Multi-node tests | Not supported | Implemented in `conftest_mesh.py` |

Both projects use the **same Labgrid inventory** ([Lab architecture](lab-architecture.md)): each test locks DUTs via Labgrid and sets the VLAN it needs at runtime.

---

## 9. WireGuard in Ansible (fcefyn_testbed_utils) {: #wireguard-ansible-fcefyn }

Role in `fcefyn_testbed_utils` to bring up the lab host tunnel toward the **global-coordinator**. It does not replace key exchange with the upstream maintainer: it only automates install, `wg0.conf`, and systemd on Debian/Ubuntu.

| Item | Location |
|---|---|
| Role | `ansible/roles/wireguard/` |
| Playbook that uses it | `ansible/playbook_testbed.yml` (comments and tag `wireguard`) |
| Variables (placeholders) | `ansible/roles/wireguard/defaults/main.yml` |
| Template | `ansible/roles/wireguard/templates/wg0.conf.j2` |
| Service | `wg-quick@wg0` (enabled and started by the role) |

**Variables to fill** (real values come from the maintainer after you send the lab public key): `wireguard_address`, `wireguard_peer_public_key`, `wireguard_peer_endpoint`, `wireguard_peer_allowed_ips` (default `10.0.0.0/24`), `wireguard_peer_keepalive`. The **private** key does not go in the repo: the role can generate it on the host if missing (`/etc/wireguard/private.key`) and prints the public key in Ansible output to share.

**Example run** (from repo `ansible/` directory, with proper inventory):

```bash
ansible-playbook playbook_testbed.yml --tags wireguard -l <lab_host>
```

For manual tunnel or server-side detail, follow what was agreed with the upstream maintainer.

---

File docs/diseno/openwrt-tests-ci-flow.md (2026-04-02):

# openwrt-tests CI execution flow

How a CI run works end-to-end: from a GitHub Actions trigger to a firmware test on a physical DUT in a remote lab.

Companion to [openwrt-tests onboarding](openwrt-tests-onboarding.md) (infrastructure setup) and [lab architecture](lab-architecture.md) (VLAN and coordinator design).

---

## 1. Two independent planes

The flow combines two separate communication channels that should not be confused:

| Plane | Protocol | Purpose |
|---|---|---|
| **Control** | WebSocket (port 20408) | Coordinator manages places, reservations, locks. `labgrid-client` and the Labgrid pytest plugin use this. |
| **Hardware access** | SSH over WireGuard | Runner reaches the lab host to access physical resources (serial, power, DUT SSH). The coordinator is not involved for this. |

---

## 2. Components per location

### Datacenter VM (global-coordinator)

| Component | Role |
|---|---|
| `labgrid-coordinator` (port 20408) | WebSocket server. Registers places from `places.yaml`, tracks locks and reservations. |
| `places.yaml` | Generated by Ansible from `labnet.yaml`. Lists every place (DUT) across all labs. |
| GitHub Actions self-hosted runners | Processes that poll GitHub via HTTPS and execute workflow jobs. Labeled `global-coordinator`. |
| WireGuard peers | One per lab host. Gives each lab a private IP reachable from the VM. |

### Each lab host (e.g. `labgrid-fcefyn`, `labgrid-aparcar`)

| Component | Role |
|---|---|
| `labgrid-exporter` | Registers local DUT resources (serial, power, network) with the coordinator over WebSocket. |
| `exporter.yaml` | Declares the physical resources of each place: USB serial path, PDUDaemon port, DUT IP+VLAN interface. |
| `pdudaemon` | Controls DUT power via relay or PDU. Exposes an HTTP API on `localhost:16421`. |
| `ser2net` | Exposes USB serial ports as TCP sockets. Used by Labgrid `SerialDriver`. |
| `dnsmasq` | DHCP + TFTP server per VLAN. DUTs boot initramfs via TFTP. |
| `labgrid-bound-connect` | SSH proxy command (runs as `sudo`). Bridges a TCP connection to a DUT IP bound to a specific VLAN interface using `socat`. |
| WireGuard peer | Tunnel to the VM. |

```mermaid
flowchart TD
    subgraph vm ["Datacenter VM (public IP)"]
        RUNNERS["GitHub runners"]
        COORD["labgrid-coordinator :20408"]
    end

    subgraph lab ["Lab host (e.g. labgrid-fcefyn)"]
        EXP["labgrid-exporter"]
        BC["labgrid-bound-connect"]
        PDU["pdudaemon :16421"]
        SER["ser2net"]
        DNS["dnsmasq / TFTP"]
        DUTs["DUTs (192.168.1.1%vlanXXX)"]
    end

    RUNNERS -- "1" --> COORD
    EXP -- "2" --> COORD
    RUNNERS -- "3" --> BC
    BC -- "4" --> DUTs
    PDU -- "5" --> DUTs
    SER -- "5" --> DUTs
    DNS -- "5" --> DUTs
```

| # | Connection | Detail |
|---|---|---|
| 1 | Runners → Coordinator | WebSocket localhost:20408 (reserve / lock / unlock) |
| 2 | Exporter → Coordinator | WebSocket via WireGuard (register resources) |
| 3 | Runners → bound-connect | SSH via WireGuard (LG_PROXY) |
| 4 | bound-connect → DUTs | socat TCP bound to correct VLAN interface |
| 5 | Local services → DUTs | pdudaemon (power), ser2net (serial), dnsmasq (DHCP/TFTP) |

All connections between the VM and the lab host traverse a **WireGuard** tunnel. `places.yaml` on the VM is generated by Ansible from `labnet.yaml`.

---

## 3. Matrix strategy: one job per device

The `generate-matrix` job reads `labnet.yaml` and produces a JSON list of all devices across all labs. GitHub Actions expands it into **parallel jobs**, one per device.

```mermaid
flowchart LR
    LN["labnet.yaml\n(devices + labs)"]
    GM["generate-matrix job\n(ubuntu-latest)"]
    J1["Job: openwrt_one\n(labgrid-fcefyn)\nruns-on: global-coordinator"]
    J2["Job: bananapi_bpi-r4\n(labgrid-fcefyn)\nruns-on: global-coordinator"]
    J3["Job: linksys_e8450\n(labgrid-hauke)\nruns-on: global-coordinator"]

    LN --> GM
    GM -- "matrix JSON" --> J1
    GM -- "matrix JSON" --> J2
    GM -- "matrix JSON" --> J3
```

Each job receives its own `matrix.device`, `matrix.proxy`, `matrix.target`, `matrix.firmware` values.

---

## 4. Environment variables and `$GITHUB_ENV`

Variables are passed between steps via `$GITHUB_ENV`: a **temporary file** the runner creates per job. Each `echo "VAR=val" >> $GITHUB_ENV` writes a line; the runner reads the file after each step and injects the variables into the next step's process environment.

```mermaid
sequenceDiagram
    participant GH as GitHub Actions
    participant Step1 as Step: Set environment
    participant Step2 as Step: Wait for free device
    participant Step3 as Step: Run test
    participant Step4 as Step: Poweroff and unlock

    GH->>Step1: matrix.device, matrix.proxy, matrix.firmware, matrix.version_url
    Step1->>Step1: wget firmware from OpenWrt mirrors
    Step1-->>GH: LG_IMAGE=/path/to/firmware<br/>LG_PROXY=labgrid-fcefyn<br/>(via $GITHUB_ENV)

    GH->>Step2: (reads LG_PROXY from env)
    Step2->>Step2: labgrid-client reserve --wait --shell device=X
    Note right of Step2: eval sets LG_TOKEN in current shell
    Step2-->>GH: LG_TOKEN=xxx<br/>LG_PLACE=+<br/>LG_ENV=targets/device.yaml<br/>(via $GITHUB_ENV)
    Step2->>Step2: labgrid-client -p +$LG_TOKEN lock

    GH->>Step3: (reads all LG_* from env)
    Step3->>Step3: uv run pytest tests/

    GH->>Step4: (reads LG_TOKEN from env)
    Step4->>Step4: labgrid-client power off
    Step4->>Step4: labgrid-client -p +$LG_TOKEN unlock
```

| Variable | Set by | Used by | Value |
|---|---|---|---|
| `LG_IMAGE` | Step "Set environment" | Labgrid plugin (`!template $LG_IMAGE` in target YAML) | Local path to firmware file |
| `LG_PROXY` | Step "Set environment" | `labgrid-client`, Labgrid plugin | Lab proxy name (e.g. `labgrid-fcefyn`) |
| `LG_TOKEN` | Step "Wait for free device" via `eval` | `labgrid-client lock/unlock` | Reservation token from coordinator |
| `LG_PLACE` | Step "Wait for free device" | Labgrid plugin (`!template "$LG_PLACE"`) | `+` (active reservation) |
| `LG_ENV` | Step "Wait for free device" | Labgrid plugin | `targets/<device>.yaml` |
| `LG_COORDINATOR` | Not set (uses default) | `labgrid-client`, Labgrid plugin | `localhost:20408` (runner and coordinator share the VM) |

### `!template` in target YAML

Target files (`targets/<device>.yaml`) use `!template` to expand environment variables at Labgrid load time:

```yaml
resources:
  RemotePlace:
    name: !template "$LG_PLACE"   # expands to "+"

images:
  root: !template $LG_IMAGE       # expands to /path/to/firmware
```

---

## 5. Full CI sequence

```mermaid
sequenceDiagram
    participant GH as GitHub (HTTPS)
    participant R as Runner (VM)
    participant LC as labgrid-client
    participant COORD as labgrid-coordinator (VM :20408)
    participant PP as pytest + Labgrid plugin
    participant LAB as Lab host
    participant DUT as DUT

    GH-->>R: trigger job (HTTPS poll)
    R->>R: checkout repo, install uv

    Note over R: Step "Set environment"
    R->>R: wget firmware from mirrors
    R->>R: write LG_IMAGE, LG_PROXY to $GITHUB_ENV

    Note over R: Step "Wait for free device"
    R->>LC: labgrid-client reserve --wait --shell device=X
    LC->>COORD: WebSocket: reserve(device=X)
    COORD-->>LC: LG_TOKEN=xxx (place allocated)
    LC->>COORD: WebSocket: lock(+$LG_TOKEN)
    R->>R: write LG_TOKEN, LG_PLACE, LG_ENV to $GITHUB_ENV

    Note over R: Step "Run test"
    R->>PP: uv run pytest tests/
    PP->>COORD: WebSocket: getResources(place=+)
    COORD-->>PP: serial=USBSerial@lab, PDU=localhost:16421@lab, IP=192.168.1.1%vlanXXX
    PP->>LAB: SSH (LG_PROXY=labgrid-fcefyn via WireGuard)
    LAB->>LAB: labgrid-bound-connect (socat TCP → 192.168.1.1:22 bound to vlanXXX)
    LAB->>DUT: TCP connection to DUT
    PP-->>DUT: flash firmware via TFTP + U-Boot serial
    PP-->>DUT: SSH to DUT (via bound-connect)
    DUT-->>PP: test results

    Note over R: Step "Poweroff and unlock"
    R->>LC: labgrid-client power off
    LC->>COORD: WebSocket: call PDUDaemonDriver.off
    COORD->>LAB: forward to exporter → pdudaemon → relay → DUT power off
    R->>LC: labgrid-client unlock +$LG_TOKEN
    LC->>COORD: WebSocket: unlock(+$LG_TOKEN)
```

---

## 6. Role of `labgrid-bound-connect`

`labgrid-bound-connect` is a Python script installed on each **lab host** (not on the VM). It is invoked as an **SSH ProxyCommand** when the runner opens a connection to a DUT.

**Problem it solves:** all DUTs share the same IP (`192.168.1.1`), each on a different VLAN interface (`vlan100`, `vlan101`, ...). A normal TCP connect from the lab host would use the default route and miss the right VLAN. The script uses `socat` with `so-bindtodevice=vlanXXX` to force the connection out through the correct interface.

```
Runner (VM)
  └── SSH → lab host (via WireGuard)
              └── labgrid-bound-connect vlan101 192.168.1.1 22
                    └── socat STDIO TCP4:192.168.1.1:22,so-bindtodevice=vlan101
                          └── DUT on VLAN 101
```

The script runs under `sudo` (passwordless via `/etc/sudoers`). It is deployed by the Ansible playbook to `/usr/local/sbin/labgrid-bound-connect` on each lab host.

---

## 7. Summary: who calls what

| Action | Caller | Target | Protocol |
|---|---|---|---|
| Reserve place | `labgrid-client` (runner) | coordinator | WebSocket |
| Lock place | `labgrid-client` (runner) | coordinator | WebSocket |
| Get resources for place | Labgrid pytest plugin | coordinator | WebSocket |
| SSH to DUT | Labgrid pytest plugin | lab host → DUT | SSH over WireGuard + bound-connect |
| Serial access | Labgrid pytest plugin | lab host ser2net | TCP over WireGuard |
| Power control | `labgrid-client` / plugin | coordinator → exporter → pdudaemon | WebSocket → HTTP |
| Unlock place | `labgrid-client` (runner) | coordinator | WebSocket |
| Register resources | `labgrid-exporter` (lab) | coordinator | WebSocket (outbound from lab) |

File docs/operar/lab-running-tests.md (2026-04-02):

# Running tests locally

Pytest and Labgrid on the lab host. Deploy and services: [Routine operations](lab-routine-operations.md).

---

## First time: validate the lab {: #first-time-validate-the-lab }

**Concepts:** Place = reservable DUT (serial, power, TFTP, SSH). Exporter = publishes places. Coordinator = reservations. `labgrid-client` / pytest acquire and run.

**Steps:** (1) Deploy configs via Ansible (see [Routine operations - Ansible](lab-routine-operations.md#ansible)). (2) `sudo systemctl start labgrid-coordinator labgrid-exporter` if not running. (3) `labgrid-client places`. (4) Firmware on TFTP: [TFTP / dnsmasq](../configuracion/tftp-server.md). (5) Reserve before pytest: `labgrid-client lock` (with `LG_PLACE`), run tests, `labgrid-client unlock`.

### labgrid-dev and TFTP symlinks {: #labgrid-dev-and-tftp }

TFTP dirs belong to **`labgrid-dev`**. For Labgrid to create symlinks when running tests, connect to the host as **`labgrid-dev`**. Paths and ownership: [host-config](../configuracion/host-config.md), [TFTP / dnsmasq](../configuracion/tftp-server.md).

---

## Single-node test (one DUT)

```bash
# OpenWrt
LG_PLACE=labgrid-fcefyn-belkin_rt3200_1 \
LG_IMAGE=/srv/tftp/belkin_rt3200_1/linksys_e8450-initramfs-kernel.bin \
uv run pytest tests/test_base.py tests/test_lan.py -v

# LibreMesh (fixture moves DUT VLAN to 200 automatically)
LG_PLACE=labgrid-fcefyn-belkin_rt3200_1 \
LG_IMAGE=/srv/tftp/belkin_rt3200_1/lime-linksys_e8450-initramfs-kernel.bin \
uv run pytest tests/test_libremesh.py tests/test_lan.py -v
```

---

## Multi-node LibreMesh test

The libremesh-tests fixture moves DUT VLANs to 200 automatically (via `labgrid-switch-abstraction`).

```bash
LG_MESH_PLACES="labgrid-fcefyn-openwrt_one,labgrid-fcefyn-bananapi_bpi-r4,labgrid-fcefyn-librerouter_1,labgrid-fcefyn-belkin_rt3200_2" \
LG_IMAGE_MAP="openwrt_one=/srv/tftp/.../openwrt-one-initramfs.itb,..." \
LG_MESH_KEEP_POWERED=1 \
uv run pytest tests/test_mesh.py -v
```

`LG_MESH_KEEP_POWERED=1` leaves DUTs powered after the test (VLANs are still restored to isolated). SSH via alias: `ssh dut-belkin-rt3200-2`.

---

## Remote coordinator access (openwrt-tests)

```bash
# Aparcar coordinator is in the cloud; exporter does the work
# LG_COORDINATOR is set in CI runner env
export LG_COORDINATOR=ws://coordinator.aparcar.org:20408

# List available places
labgrid-client places

# Reserve a specific FCEFYN place
labgrid-client -p labgrid-fcefyn-openwrt_one reserve --wait --token mytoken
```

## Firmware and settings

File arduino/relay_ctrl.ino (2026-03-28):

/**
 * ------------------------------------------------------------
 *  Proyecto: fcefyn-testbed-utils
 *  Script:   relay_ctrl.ino
 *  Autor:    Franco Riba
 *
 *  Descripción:
 *    Control de módulos de relés mediante interfaz USB-Serial.
 *    Diseñado para pruebas automatizadas (HIL - Hardware-in-the-loop).
 *
 *  Hardware:
 *    - Arduino Nano (ATmega328P)
 *    - Módulo relé KY-019 de 8 canales (DUTs) -> D2..D9
 *    - SSR 4 canales (Switch+Cooler) y SSR simple (Fuente) -> D10..D12
 *    - Conexión por USB (baudrate 115200)
 *
 *  Pines:
 *    Canales 0-7: D2..D9   (módulo 8 relés mecánicos, DUTs)
 *    Canal 8:     D10      (SSR Switch, módulo 4ch)
 *    Canal 9:     D11      (SSR Cooler, módulo 4ch)
 *    Canal 10:    D12      (SSR Fuente, Fotek SSR25DA) — activo en alto
 *
 *  Comandos disponibles por Serial:
 *    ON n [n ...]      : enciende uno o varios relés (0..10)
 *    OFF n [n ...]     : apaga uno o varios relés
 *    TOGGLE n [n ...]  : alterna uno o varios relés
 *    PULSE n ms        : enciende el relé n durante ms milisegundos
 *    ALLON             : enciende todos los relés
 *    ALLOFF            : apaga todos los relés
 *    STATUS            : imprime el estado de todos los relés
 *    HELP              : muestra ayuda
 *    ID                : identificación del dispositivo
 *
 *  Notas:
 *    - Canales 0-9: activos en bajo (LOW = ON).
 *    - Canal 10 (Fuente): activo en alto (HIGH = ON), invertido respecto al resto.
 * ------------------------------------------------------------
 */

#include <Arduino.h>

// Configuración
constexpr bool RELAY_ACTIVE_LOW = true;        // true = activo-bajo, false = activo-alto
constexpr uint8_t RELAY_COUNT   = 11;          // 8 DUTs + 3 SSR (Switch, Cooler, Fuente)
constexpr uint8_t RELAY_PINS[RELAY_COUNT] = {
  2, 3, 4, 5, 6, 7, 8, 9,   // D2..D9: módulo 8 relés (DUTs)
  10, 11, 12                 // D10..D12: SSR Switch, Cooler, Fuente
};

enum RelayState : uint8_t { R_OFF = 0, R_ON = 1 };
RelayState states[RELAY_COUNT];

/**
 * @brief Returns true if channel uses active-low logic (LOW = ON).
 * Channel 10 (power source) is active-high; others follow RELAY_ACTIVE_LOW.
 */
bool channelActiveLow(uint8_t ch) {
  if (ch == 10) return false;  // Fuente SSR: active-high
  return RELAY_ACTIVE_LOW;
}

/**
 * @brief Aplica el estado a un relé individual.
 */
void applyRelay(uint8_t ch, RelayState s) {
  if (ch >= RELAY_COUNT) return;
  states[ch] = s;

  bool activeLow = channelActiveLow(ch);
  uint8_t level = (s == R_ON) ? (activeLow ? LOW : HIGH) : (activeLow ? HIGH : LOW);
  digitalWrite(RELAY_PINS[ch], level);
}

/**
 * @brief Aplica el mismo estado a todos los relés.
 */
void allRelays(RelayState s) {
  for (uint8_t i = 0; i < RELAY_COUNT; i++) {
    applyRelay(i, s);
  }
}

/**
 * @brief Imprime el estado actual de todos los relés.
 */
void printStatus() {
  Serial.print(F("STATUS "));
  for (uint8_t i = 0; i < RELAY_COUNT; i++) {
    Serial.print(i);
    Serial.print(':');
    Serial.print(states[i] == R_ON ? F("ON") : F("OFF"));
    if (i < RELAY_COUNT - 1) Serial.print(' ');
  }
  Serial.println();
}

/**
 * @brief Muestra ayuda de comandos.
 */
void help() {
  Serial.println(F("Comandos disponibles:"));
  Serial.println(F("  ON n [n ...] | OFF n [n ...] | TOGGLE n [n ...]"));
  Serial.println(F("  PULSE n ms"));
  Serial.println(F("  ALLON | ALLOFF | STATUS | HELP | ID"));
  Serial.println(F("  n=0..10, ms=milisegundos (1..60000)"));
}

void setup() {
  Serial.begin(115200);

  // Configurar pines como salida
  for (uint8_t i = 0; i < RELAY_COUNT; i++) {
    pinMode(RELAY_PINS[i], OUTPUT);
  }

  // Estado inicial seguro: todo apagado
  allRelays(R_OFF);

  Serial.println(F("OK RELAY-CTRL v2 (11ch) listo @115200"));
  help();
}

/**
 * @brief Lee una línea completa del puerto serial.
 */
bool readLine(String &out) {
  while (Serial.available()) {
    char c = Serial.read();
    if (c == '\r') continue;
    if (c == '\n') return true;
    if (out.length() < 128) out += c; // un poco más de margen
  }
  return false;
}

/**
 * @brief Convierte string a entero con validación.
 */
int toIntSafe(const String &s, bool &ok) {
  if (s.length() == 0) { ok = false; return 0; }
  // Validación básica: debe empezar en dígito (permitimos '0')
  bool digitFound = false;
  for (uint16_t i = 0; i < s.length(); i++) {
    if (isDigit(s[i])) { digitFound = true; break; }
  }
  if (!digitFound) { ok = false; return 0; }
  long v = s.toInt();
  ok = true;
  return (int)v;
}

/**
 * @brief Procesa comandos de múltiples canales: ON/OFF/TOGGLE <n> [n ...]
 */
void processMultiChannelCommand(const String &cmd, String rest) {
  if (rest.length() == 0) {
    Serial.println(F("ERR se requieren canales (0..10). Ej: ON 0 1 8"));
    return;
  }

  bool anyApplied = false;

  // Iterar por tokens separados por espacio
  while (rest.length() > 0) {
    int sp = rest.indexOf(' ');
    String tok = (sp < 0) ? rest : rest.substring(0, sp);
    rest = (sp < 0) ? "" : rest.substring(sp + 1);
    rest.trim();
    tok.trim();

    if (tok.length() == 0) continue;

    bool ok = false;
    int ch = toIntSafe(tok, ok);
    if (!ok || ch < 0 || ch >= (int)RELAY_COUNT) {
      Serial.print(F("WARN token inválido/ fuera de rango: "));
      Serial.println(tok);
      continue;
    }

    if (cmd == F("ON")) {
      applyRelay((uint8_t)ch, R_ON);
    } else if (cmd == F("OFF")) {
      applyRelay((uint8_t)ch, R_OFF);
    } else { // TOGGLE
      applyRelay((uint8_t)ch, states[ch] == R_ON ? R_OFF : R_ON);
    }
    anyApplied = true;
  }

  if (anyApplied) printStatus();
  else Serial.println(F("ERR no se aplicó ningún canal válido"));
}

void loop() {
  static String line;
  if (!readLine(line)) return;

  line.trim();
  line.toUpperCase();
  if (line.length() == 0) { line = ""; return; }

  // Tokenizar
  int sp1 = line.indexOf(' ');
  String cmd  = (sp1 < 0) ? line : line.substring(0, sp1);
  String rest = (sp1 < 0) ? ""   : line.substring(sp1 + 1);
  rest.trim();

  if (cmd == F("ON") || cmd == F("OFF") || cmd == F("TOGGLE")) {
    processMultiChannelCommand(cmd, rest);

  } else if (cmd == F("PULSE")) {
    int sp = rest.indexOf(' ');
    if (sp < 0) {
      Serial.println(F("ERR uso: PULSE n ms"));
    } else {
      bool ok1 = false, ok2 = false;
      int ch = toIntSafe(rest.substring(0, sp), ok1);
      int ms = toIntSafe(rest.substring(sp + 1), ok2);
      if (!ok1 || !ok2 || ch < 0 || ch >= RELAY_COUNT || ms < 1 || ms > 60000) {
        Serial.println(F("ERR args (n=0..10, ms=1..60000)"));
      } else {
        applyRelay(ch, R_ON);
        delay(ms);
        applyRelay(ch, R_OFF);
        printStatus();
      }
    }

  } else if (cmd == F("ALLON")) {
    allRelays(R_ON); printStatus();

  } else if (cmd == F("ALLOFF")) {
    allRelays(R_OFF); printStatus();

  } else if (cmd == F("STATUS")) {
    printStatus();

  } else if (cmd == F("HELP")) {
    help();

  } else if (cmd == F("ID")) {
    Serial.println(F("RELAY-CTRL v2 (11ch)"));

  } else {
    Serial.println(F("ERR comando desconocido (try HELP)"));
  }

  line = "";
}

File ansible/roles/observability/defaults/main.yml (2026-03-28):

---
# DUTs with active metrics observability.
# Each entry generates:
#   - a systemd autossh tunnel unit (dut-metrics-tunnel-<name>.service)
#   - a Prometheus scrape job fragment (/etc/prometheus/jobs.d/<name>.yml)
#
# Prerequisite per DUT (manual, one-time — see docs/configuracion/observabilidad.md):
#   opkg install prometheus-node-exporter-lua prometheus-node-exporter-lua-openwrt
#   uci set prometheus-node-exporter-lua.main.listen_interface='loopback'
#   uci commit prometheus-node-exporter-lua
#   /etc/init.d/prometheus-node-exporter-lua enable && /etc/init.d/prometheus-node-exporter-lua start
#
# local_port: host-side port for the SSH tunnel (unique per DUT, range 19100–19199)
# remote_port: exporter port on the DUT loopback (default 9100)
#
# ssh_alias must match pool-config.yaml. Label dut should match Grafana variable values.

observability_duts:
  - name: gateway-openwrt
    ssh_alias: gateway-openwrt
    local_port: 19106
    remote_port: 9100
    labels:
      dut: gateway-wdr3500
      firmware: openwrt-25.12.1
      target: ath79-tplink

  - name: openwrt-one
    ssh_alias: dut-openwrt-one
    local_port: 19100
    remote_port: 9100
    labels:
      dut: openwrt-one
      firmware: openwrt-24.10.5
      target: mediatek-filogic

  - name: belkin-1
    ssh_alias: dut-belkin-1
    local_port: 19101
    remote_port: 9100
    labels:
      dut: belkin-1
      firmware: openwrt-23.05.5
      target: mediatek-mt7622

  - name: belkin-2
    ssh_alias: dut-belkin-2
    local_port: 19102
    remote_port: 9100
    labels:
      dut: belkin-2
      firmware: openwrt-23.05.5
      target: mediatek-mt7622

  - name: belkin-3
    ssh_alias: dut-belkin-3
    local_port: 19103
    remote_port: 9100
    labels:
      dut: belkin-3
      firmware: openwrt-23.05.5
      target: mediatek-mt7622

  - name: bananapi
    ssh_alias: dut-bananapi
    local_port: 19104
    remote_port: 9100
    labels:
      dut: bananapi
      firmware: openwrt-24.10.5
      target: mediatek-mt7988

  - name: librerouter-1
    ssh_alias: dut-librerouter-1
    local_port: 19105
    remote_port: 9100
    labels:
      dut: librerouter-1
      firmware: librerouteros-23.05-libremesh
      target: ipq4019

# Reverse SSH tunnel: exposes Grafana publicly via Oracle VPS.
# Requires Host oracle-vps in ~/.ssh/config on the lab host (manual prerequisite).
# Set enabled: true to deploy and start the unit.
grafana_public_tunnel:
  enabled: false
  ssh_alias: oracle-vps
  grafana_port: 3000

# Prometheus node exporter on the orchestration host.
# Listens only on loopback to avoid exposing metrics on the lab LAN.
# label dut matches the Grafana dashboard variable so the host appears
# alongside DUTs in the same dashboard.
orchestrator_node_exporter:
  enabled: true
  listen_address: "127.0.0.1"
  listen_port: 9100
  scrape_job_name: orchestrator-host
  labels:
    dut: lab-orchestrator
    role: orchestration-host

# Grafana server settings applied to /etc/grafana/grafana.ini.
grafana_config:
  root_url: "https://fcefyn-testbed.duckdns.org/"
  cookie_secure: "true"
  cookie_samesite: "lax"
  allow_sign_up: "false"

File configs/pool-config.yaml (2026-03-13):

# FCEFYN Testbed Pool Configuration
#
# Edit 'pools' to change which DUTs belong to each project, then run:
#   scripts/switch/pool-manager.py --apply
#
# Modes:
#   libremesh-only:  all DUTs in 'libremesh' pool, 'openwrt' pool empty
#   openwrt-only:    all DUTs in 'openwrt' pool,    'libremesh' pool empty
#   hybrid:          DUTs split across both pools

coordinators:
  openwrt: "coordinator.openwrt.org:20408"
  libremesh: "localhost:20408"

switch:
  host: "192.168.0.1"
  user: "admin"
  # Password is loaded from ~/.config/poe_switch_control.conf (POE_SWITCH_PASSWORD)
  uplink_ports: [9, 10]  # always tagged for all active VLANs

# DUT hardware database — physical facts that never change with pool assignments
duts:
  belkin_rt3200_1:
    location: fcefyn-testbed
    serial_port: "/dev/belkin-rt3200-1"
    serial_speed: 115200
    ssh_alias: "dut-belkin-1"
    pdu_host: "localhost:16421"
    pdu_name: "fcefyn-arduino"
    pdu_index: 0
    switch_port: 11
    switch_vlan_isolated: 100
    tftp_path: "belkin_rt3200_1/"
    libremesh_fixed_ip: "10.13.200.11"

  belkin_rt3200_2:
    location: fcefyn-testbed
    serial_port: "/dev/belkin-rt3200-2"
    serial_speed: 115200
    ssh_alias: "dut-belkin-2"
    pdu_host: "localhost:16421"
    pdu_name: "fcefyn-arduino"
    pdu_index: 1
    switch_port: 12
    switch_vlan_isolated: 101
    tftp_path: "belkin_rt3200_2/"
    libremesh_fixed_ip: "10.13.200.196"

  belkin_rt3200_3:
    location: fcefyn-testbed
    serial_port: "/dev/belkin-rt3200-3"
    serial_speed: 115200
    ssh_alias: "dut-belkin-3"
    pdu_host: "localhost:16421"
    pdu_name: "fcefyn-arduino"
    pdu_index: 2
    switch_port: 13
    switch_vlan_isolated: 102
    tftp_path: "belkin_rt3200_3/"
    libremesh_fixed_ip: "10.13.200.118"

  bananapi_bpi-r4:
    location: fcefyn-testbed
    serial_port: "/dev/bpi-r4"
    serial_speed: 115200
    ssh_alias: "dut-bananapi"
    pdu_host: "localhost:16421"
    pdu_name: "fcefyn-arduino"
    pdu_index: 3
    switch_port: 14
    switch_vlan_isolated: 103
    tftp_path: "bananapi_bpi-r4/"
    libremesh_fixed_ip: "10.13.200.169"

  openwrt_one:
    location: fcefyn-testbed
    serial_port: "/dev/openwrt-one"
    serial_speed: 115200
    ssh_alias: "dut-openwrt-one"
    pdu_host: "localhost:16421"
    pdu_name: "fcefyn-poe-port1"
    pdu_index: 1
    switch_port: 16        # LAN data port (eth0 swapped to br-lan)
    switch_port_poe: 1     # WAN/PoE port — always in same VLAN for U-Boot
    switch_vlan_isolated: 104
    tftp_path: "openwrt_one/"
    libremesh_fixed_ip: "10.13.200.120"

  librerouter_1:
    location: fcefyn-testbed
    serial_port: "/dev/librerouter-1"
    serial_speed: 115200
    ssh_alias: "dut-librerouter-1"
    pdu_host: "localhost:16421"
    pdu_name: "fcefyn-poe-port2"
    pdu_index: 2
    switch_port: 2
    switch_vlan_isolated: 105
    tftp_path: "librerouter_1/"
    libremesh_fixed_ip: "10.13.200.77"

# Pool assignment — edit here to change testbed mode.
# A DUT must belong to exactly one pool (or neither, to exclude it).
pools:
  openwrt:
    duts: []

  libremesh:
    duts:
      - belkin_rt3200_1
      - belkin_rt3200_2
      - belkin_rt3200_3
      - bananapi_bpi-r4
      - openwrt_one
      - librerouter_1

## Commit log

2026-01-16 add 3d models for rack assembly
    [airflow_chimney_duct.scad, airflow_chimney_duct_2levels.stl, airflow_chimney_duct_3levels.stl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]
2026-01-18 add images of parts and improve readme
    [curved_intake_duct.stl, drawer_stop.stl]
2026-01-21 add more 3d parts stl files
    [NanoHolderA.stl, belkin_rt3200_base.stl, hub_shelf_TP-LINK_UH700.stl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]
2026-02-23 add script for poe power cycle using switch
2026-03-04 docs: add arduino relay daemon template
2026-03-08 fix inconsistent switch state in hybrid mode
    [pool-manager.py]
2026-03-09 chore: reorganize directories for switch related ops
2026-03-09 refactor: make switch logic use different switch drivers if needed
2026-03-09 docs: add switch driver interface
2026-03-09 feat: add support for --no-switch flag in libremesh/openwrt modes
2026-03-09 docs: switch documentation to spanish
2026-03-09 fix(switch): chmod lock file when root hits PermissionError on user-owned lock
2026-03-09 fix(switch): apply full config when state matches desired to correct switch staleness
    [pool-manager.py]
2026-03-09 feat(pool-manager): deploy to /etc/labgrid/ by default, add --export-to-configs for manual flow
2026-03-10 fix(arduino): update reference
2026-03-10 fix(style): fix ruff issues across multiple files
    [arduino_daemon.py, arduino_relay_control.py, generate_places_yaml.py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]
2026-03-10 fix(arduino daemon): fix bug
    [arduino_daemon.py]
2026-03-11 update libremesh_node script, se le agregaron funciones de add y kill nodos y que se actualice la red
2026-03-12 fix: change installation method
    [main.yml]
2026-03-13 chore: add backup of TPLink SG2016P switch configs for mesh and isolated modes
    [SwitchConfigBackup_isolated.cfg, SwitchConfigBackup_mesh.cfg]
2026-03-15 refactor: add support for testbed devices with AC solid state relays
2026-03-21 refactor: re-organize rack 3d design directory
    [NanoHolderA.stl, airflow_chimney_duct.scad, airflow_chimney_duct_2levels.stl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]
2026-03-22 docs: switch: add switch documentation
2026-03-24 ops:ansible:fix:intentation of prometheus block
    [main.yml]
2026-03-24 ops:ansible:observability: support multiple devices
2026-03-24 ops:ansible:fix belkin2 firmware spec
    [main.yml]
2026-03-25 fix(observability): set explicit datasource uid to resolve provisioned dashboard
    [main.yml]
2026-03-29 feat(switch): add multi-port PoE control in single SSH session
2026-03-30 docs(onboarding): align sequence diagram, checklist, and WireGuard Ansible section
2026-03-31 docs: switch documentation from esp to english
2026-04-29 fix(provision_mesh_ip): fix indentation error at line 218
    [provision_mesh_ip.py]
